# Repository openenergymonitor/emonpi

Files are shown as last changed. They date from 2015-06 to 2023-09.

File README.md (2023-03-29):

# emonPi

Raspberry Pi based energy Monitoring Unit

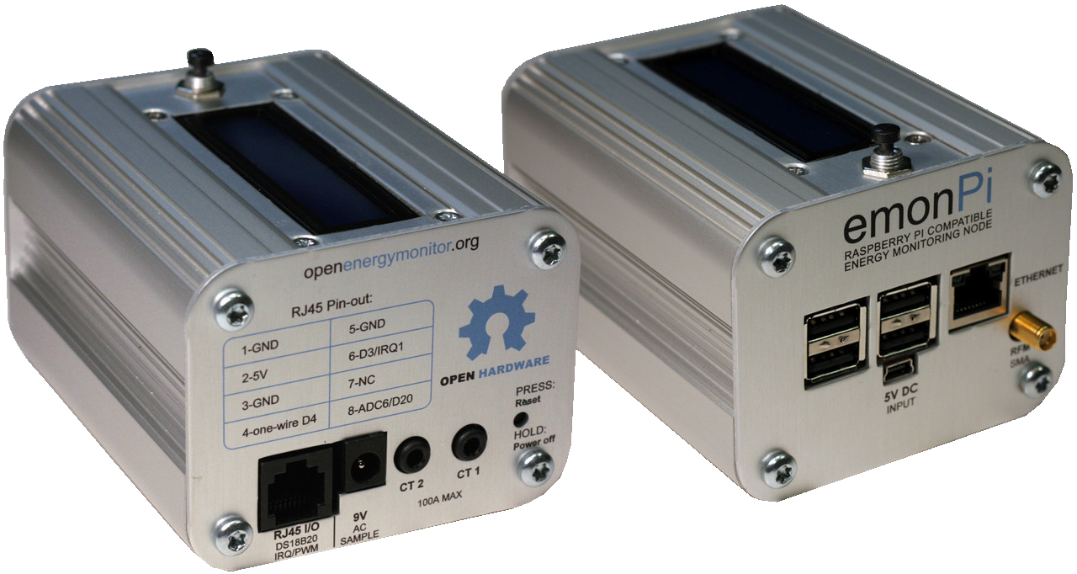
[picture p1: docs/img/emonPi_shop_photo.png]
emonPi


## Documentation

- [Install Guide](https://docs.openenergymonitor.org/emonpi/install.html)
- [Connect](https://docs.openenergymonitor.org/emonpi/connect.html)
- [Pulse counting](https://docs.openenergymonitor.org/emonpi/pulse_counting.html)
- [Temperature sensing](https://docs.openenergymonitor.org/emonpi/temperature_sensing.html)
- [Firmware](https://docs.openenergymonitor.org/emonpi/firmware.html)
- [Configuration](https://docs.openenergymonitor.org/emonpi/configuration.html)
- [Use in North America](https://docs.openenergymonitor.org/emonpi/north-america.html)
- [Modification](https://docs.openenergymonitor.org/emonpi/modification.html)
- [Technical](https://docs.openenergymonitor.org/emonpi/technical.html)

Or view directly on github [here](docs).

## [emonSD image download](https://docs.openenergymonitor.org/emonsd/download.html)

[Software Stack Build & Documentation](https://github.com/openenergymonitor/emonscripts)

## Open-Hardware:

- [Schematic & Board CAD Design Files](https://github.com/openenergymonitor/emonpi/tree/master/hardware)

## Community & Support

- [OpenEnergyMonitor Forums](https://community.openenergymonitor.org)
- OpenEnergyMonitor Shop Support: support@openenergymonitor.zendesk.com

## License

- The hardware designs (schematics and CAD files) are licensed under a Creative Commons Attribution-ShareAlike 3.0 Unported License.
- The firmware is released under the GNU GPL V3 license The documentation is subject to GNU Free Documentation License
- The hardware designs follow the terms of the OSHW (Open-source hardware) Statement of Principles 1.0.

## Disclaimer

```
OUR PRODUCTS AND ASSEMBLY KITS MAY BE USED BY EXPERIENCED, SKILLED USERS, AT THEIR OWN RISK. TO THE FULLEST EXTENT PERMISSIBLE BY THE APPLICABLE LAW, WE HEREBY DISCLAIM ANY AND ALL RESPONSIBILITY, RISK, LIABILITY AND DAMAGES ARISING OUT OF DEATH OR PERSONAL INJURY RESULTING FROM ASSEMBLY OR OPERATION OF OUR PRODUCTS.

Your safety is your own responsibility, including proper use of equipment and safety gear, and determining whether you have adequate skill and experience. OpenEnergyMonitor and Megni registered partnership disclaims all responsibility for any resulting damage, injury, or expense. It is your responsibility to make sure that your activities comply with applicable laws, including copyright. Always check the webpage associated with each unit before you get started. There may be important updates or corrections. All use of the instructions, kits, projects and suggestions given both by megni.co.uk, openenergymonitor.org and shop.openenergymonitor.org are to be used at your own risk. The technology (hardware , firmware and software) are constantly changing, documentation (including build guide and instructions) may not be complete or correct.

If you feel uncomfortable with assembling or using any part of the system, return it to us for a full refund.
```

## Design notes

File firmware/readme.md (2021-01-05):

# Change Log - emonPi Discrete Sampling Firmware

Compile using PlatformIO: https://guide.openenergymonitor.org/technical/compiling/

***

# V2.9.3 (05/01/21

- Wait longer for DS18B20 conversion, require for new batch of RJ45 temp sensors

# V2.9.2 (17/11/19)

- Fix RFM init 

https://community.openenergymonitor.org/t/emonpi-firmware-build/12428/45

```
RAM:   [=====     ]  52.9% (used 1083 bytes from 2048 bytes)
Flash: [======    ]  60.3% (used 18526 bytes from 30720 bytes)
```

# V2.9.0 (16/01/18)

- Allow CT's to be plugged in after unit has powered up. CT input will read zero if no CT is connected.

```
Program:   17886 bytes (54.6% Full)
(.text + .data + .bootloader)

Data:       1048 bytes (51.2% Full)
(.data + .bss + .noinit)
```

# V2.8.4 (21/12/17)

- Correct USA voltage for apparent power sampling to 120V. Only affects battery / DC USB 5V operation. Does not effect when powering unit via AC-AC adaptor.

```
Program:   17942 bytes (54.8% Full)
(.text + .data + .bootloader)

Data:       1034 bytes (50.5% Full)
(.data + .bss + .noinit)
```

# V2.8.3 (07/04/17)

- Reduce min pulse width to 60ms

# V2.8.2 (07/04/17)

* Reduce min pulse width to 60ms

```
Program:   17892 bytes (54.6% Full)
(.text + .data + .bootloader)
Data:       1022 bytes (49.9% Full)
(.data + .bss + .noinit)
```

# V2.8.2 (10/12/16)

* Autodetect LCD on I2C address `0x27` or `0x3f`

```
Program:   17900 bytes (54.6% Full)
(.text + .data + .bootloader)
Data:       1026 bytes (50.1% Full)
(.data + .bss + .noinit)
```

# V2.8.1 (21/11/16)

* Reintroduces "quiet mode" feature as seen in the RFM2Pi firmwares to allow improved RF debugging.

Serial `1q` enables quiet mode (default) and `0q` removes quiet mode for a more verbose output including bad packets that have failed crc checks. In emonHub it can be set with `quiet = true` or `quiet = false` in the interfacer settings. [Pull request discussion](https://github.com/openenergymonitor/emonpi/pull/34).

```
Program:   19206 bytes (58.6% Full)
(.text + .data + .bootloader)
Data:        953 bytes (46.5% Full)
(.data + .bss + .noinit)
```

# V2.8 (18/11/16)

* Compiled using platformIO with [JeeLib 10th Nov 2015 (f097c0039c)](https://github.com/jcw/jeelib/tree/f097c0039c926881d80a74bec7a7aa020de610ee)
* Fixes emonTx drop off [forum discussion](https://community.openenergymonitor.org/t/emon-txs-not-updating-after-emonpi-update/2233/10)

```
Program:   19074 bytes (58.2% Full)
(.text + .data + .bootloader)
Data:        951 bytes (46.4% Full)
(.data + .bss + .noinit)
```

# V2.7 (16/11/16)

* Compiled using platformIO with latest JeeLib (7fc95a72ec)
* Consistency with github releases
* Smaller compiled size
* Ensure soft-reset introduced in V2.5 is included
  * Fix RF droping issue caused by V2.6 being mistakenly compiled

```
Program:   19100 bytes (58.3% Full)
(.text + .data + .bootloader)
Data:        951 bytes (46.4% Full)
(.data + .bss + .noinit)
```

# V2.6 (15/04/16)
* [Update to latest JeeLib with RF Fixes ](https://github.com/jcw/jeelib/issues/92) [68f6e42]~~
* Remove RF keep alive introduced in V2.5~
Compiled with Arduino 1.6.8 | Hex size: 54.8kB | Sketch uses 19,400 bytes (60%) | Global variables: 947 bytes (46%)~~

**(10/05/16) - Temporarily restored to V2.5 to fix emonTx RF dropping issue [thread [[1]](https://community.openenergymonitor.org/t/emonsd-03may16-release/145/40) [[2]](https://openenergymonitor.org/emon/node/12593)**

# V2.5 (18/03/16)
 * Soft reset RFM69CW ever 60s to ensure its kept alive

Compiled with Arduino 1.6.8 | Hex size: 55kB | Sketch uses 19,554 bytes | Global variables: 946 bytes

# V2.4 (8/03/16)
 * Adjust Vcal_EU to improve VRMS voltage reading accuracy when using UK/EU AC-AC
 * Compile with Arduino 1.6.7 with JeeLib 10th Sep 2015 f097c0039c926881d80a74bec7a7aa020de610ee
 * Updated OneWire library to V2.3.2 & updated sensors.getAddress function

Compiled with Arduino 1.6.8 | Hex size: 54.8kB | Sketch uses 19,460 bytes | Global variables: 941 bytes

# V2.3 (20/02/16)
 * Fix VRMS reading bug
 * Compile with Arduino 1.6.7

# V2.2 (30/01/16)
 * Reduction in SRAM memory usage thanks to F-macro serial string implementation
 * Display "Raspberry Pi Booting" message on LCD at startup
 * Only sample from CT channels when CT is connected to that channel (fix noise readings when no CT connected)

# V2.1 (20/1/16)
  * Allow use of group 0

# V2.0 (17/11/15)
  * Don't print ACK's to serial

# V1.9 (16/11/15)
  * Fix counting pulses faster than 110ms, strobed meter LED http://openenergymonitor.org/emon/node/11490

# V1.8 (30/10/15)
  * Enable pulse count INT1 internal pull-up to fix spurious pulse count readings

# V1.7 (12/06/15)
  * Fix bug which stopped USA AC-AC Vcal from being applied at runtime

# V1.6 (12/06/15)
  * Fix interrupt pulse debouce issue by limiting pulse width to 52ms min (50ms is default for LED pulse output meters)
  * Compile with latest JeeLib with fix for RF hang, remove RF reset added in V1.3 (bf179057ee1abc2cfa2965b454421203ac52c6c3)
  * Enable simultaneous pulse counting and temperature monitoring on single RJ45 using breakout

# V1.5 (27/05/15)
  * Change pulse count to be stored as unsigned long datatype
  * Add new variable power 1 + power 2 as third item in the node struct. This will be useful for US installs and Solar PV type 2 installations to provide a feed for consumption (solar PV + grid import / export)

**Important Note:**
After this update a manual change will be required to emonhub.conf, copy and paste the following to override the node decoder for the emonPi node [[5]] in the Nodes section of emonhub.conf:
```
[[5]]
    nodename = emonPi
    firmware = emonPi_RFM69CW_RF12Demo_DiscreteSampling.ino
    hardware = emonpi
    [[[rx]]]
        names = power1,power2,power1_plus_power2,Vrms,T1,T2,T3,T4,T5,T6,pulseCount
        datacodes = h, h, h, h, h, h, h, h, h, h, L
        scales = 1,1,1,0.01,0.1,0.1,0.1,0.1,0.1,0.1,1
        units = W,W,W,V,C,C,C,C,C,C,p
```
https://github.com/openenergymonitor/emonpi/commit/c427cd2bdfce7b3c535388d1ee53cc45183edf9c

# V1.4 (27/05/15)
Make firmware version return command 'v' return firmware version and RFM setting all on one line
https://github.com/openenergymonitor/emonpi/commit/fa4474571cffa45d03483ce9da32f021dd2df91a

# V1.3 (21/05/15)
1.3 firmware dev, add RF init ever 10min to keep RF alive
https://github.com/openenergymonitor/emonpi/commit/96b59c38c045a44e6dea3c1a5e048d038380e88a

# V1.2 (13/05/15)
Fix AC wave detect and improve AC calibration calibration
https://github.com/openenergymonitor/emonpi/commit/41987f1e21b3687b8b0ac6b9f5f5160cdfb808a4

# V1.1 (11/05/15)
Add sample from both CT's as default and set 110V VRMS for apparent power when US calibration is set e.g '2p'
https://github.com/openenergymonitor/emonpi/commit/2565eb3663847c22bfb62b0d1258f8cbc5fea224

# V1.0
First release

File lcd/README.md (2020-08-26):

# HD44780 LCD with PCF8574 I2c

I2C Address: 0x27 or 0x3f

# Enabling The I2C Port

**Tested on Raspbian**

The I2C ports need to be enabled in Raspbian before they can be used.

	$ sudo nano /boot/config.txt

Un-comment / add the line

	dtparam=i2c_arm=on

Edit kernel modules file:

	$ sudo nano /etc/modules

Add this line:

i2c-dev

Exit and save the file.

## Install the I2C utilities:

Usually pre-installed

		$ sudo apt-get install python-smbus i2c-tools

Enter "sudo reboot" to restart the pi and now the I2C pins will be available to use.

## Detect LCD on I2C bus and find out address

	$ sudo i2cdetect -y 1

Expected output is `0x27` or `0x3F` e.g.

```
pi@emonpi:~ $  sudo i2cdetect -y 1
     0  1  2  3  4  5  6  7  8  9  a  b  c  d  e  f
00:          -- -- -- -- -- -- -- -- -- -- -- -- -- 
10: -- -- -- -- -- -- -- -- -- -- -- -- -- -- -- -- 
20: -- -- -- -- -- -- -- 27 -- -- -- -- -- -- -- -- 
30: -- -- -- -- -- -- -- -- -- -- -- -- -- -- -- -- 
40: -- -- -- -- -- -- -- -- -- -- -- -- -- -- -- -- 
50: -- -- -- -- -- -- -- -- -- -- -- -- -- -- -- -- 
60: -- -- -- -- -- -- -- -- -- -- -- -- -- -- -- -- 
70: -- -- -- -- -- -- -- --   
```

Use port 0 for very old 256Mb RAM pi (rev1) - not recommended to use this pi version

# Install emonPiLCD python script

```
sudo apt-get update
sudo apt-get install python3-smbus i2c-tools python3-rpi.gpio python3-pip redis-server python3-gpiozero -y
sudo pip3 install redis paho-mqtt xmltodict requests
```

## Run as service

Run the shell script  
```
./install.sh
```

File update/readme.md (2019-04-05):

# How to run scripts manually

Current directory is emonpi/update

### Update Emoncms

    ./emoncms.sh IS_EMONSD
    ./emoncms.sh 0
    
### Update EmonHub

    ./emonhub.sh
    
### Update Firmware: EmonPi

    ./emonpi.sh
    
### Update Firmware: rfm69pi

    ./rfm69pi.sh
    
### Via main.sh

    ./main.sh UPDATE_TYPE FIRMWARE IMAGE_NAME
    ./main.sh all emonpi emonSD-30Oct18
    ./main.sh emoncms emonSD-30Oct18
    ./main.sh emonhub emonSD-30Oct18
    ./main.sh firmware emonpi emonSD-30Oct18
    
### Via service-runner-update.sh

Current directory is emonpi.

This script is triggered from emoncms via service-runner.

    ./service-runner-update.sh UPDATE_TYPE FIRMWARE
    ./service-runner-update.sh all emonpi

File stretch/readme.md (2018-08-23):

# Raspbian Stretch

This folder contains config files symlinked into the latest emonSD pre-build raspberry pi SD card image based on Raspbian Stretch. 

- Compatiable with RasPi 3B+ 
- Based on Raspbian Stretch Lite 
- **Does not have read-only root FS** - Unlike older emonSD card images, the Stretch image does not have a read-only root partition. After extensive testing and file system monitoring it was determind that we could achieve SD card low write by only mounting /var/log in temp fs and keeping the root partition in RW all the time. This has the advantage of making setup, config and maintenance much easier since the image is closer to the stock raspbian image.
- The folder `~/data``is still mounted on a seperate partition with a low write file-system

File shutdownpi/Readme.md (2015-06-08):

*Not used on production emonpi, functionality is now built into main emonpi lcd script 

Python Script to look for high signal on GPIO 17 (pin 11) and then shutdown the Pi if so

on the emonPi GPIO 17 is connected to ATmega328 Dig5. 
When running default firmware emonPi sets Dig5/GPIO17 high when shutdown push button the the emonPi PCB is held for 5s. The push button is connected to ATmega328 dig 8

emonPi - Raspberry Pi Energy Monitoring 
Part of the OpenEnergyMonitor.org Project

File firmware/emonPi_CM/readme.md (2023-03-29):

# emonPi_CM

**New 16th Feb 2023:** This firmware provides higher accuracy continuous monitoring. Continuous monitoring means that the power readings are representative of the full 10s period that they represent rather than a short snapshot. Support for radio formats: JeeLib Native and **LowPowerLabs (recommended)**.

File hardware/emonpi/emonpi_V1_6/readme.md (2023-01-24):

## emonPi V1.6

**Raspberry Pi Energy Monitoring Shield**

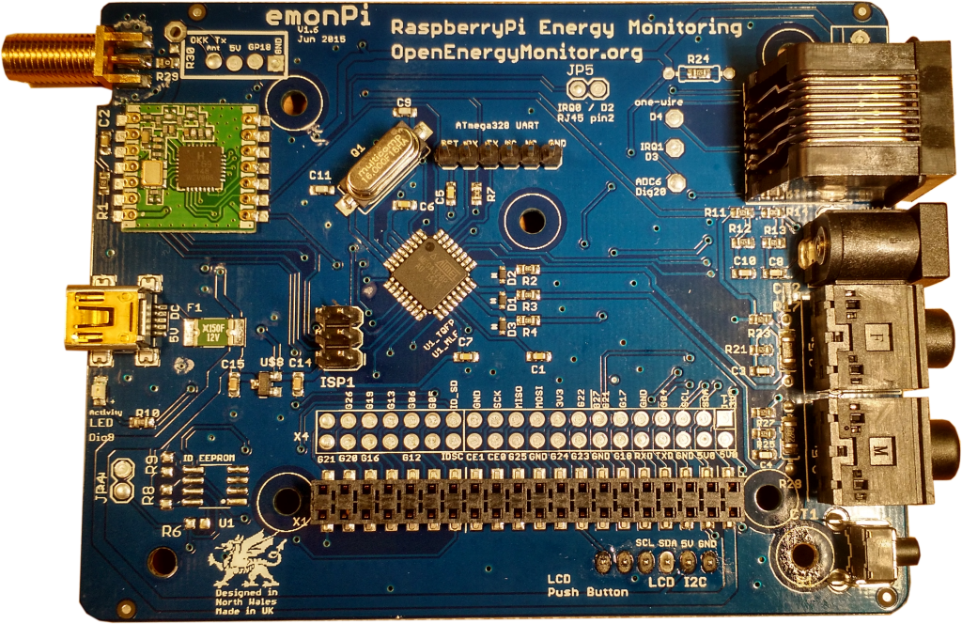
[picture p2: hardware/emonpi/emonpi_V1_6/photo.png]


### Schematic

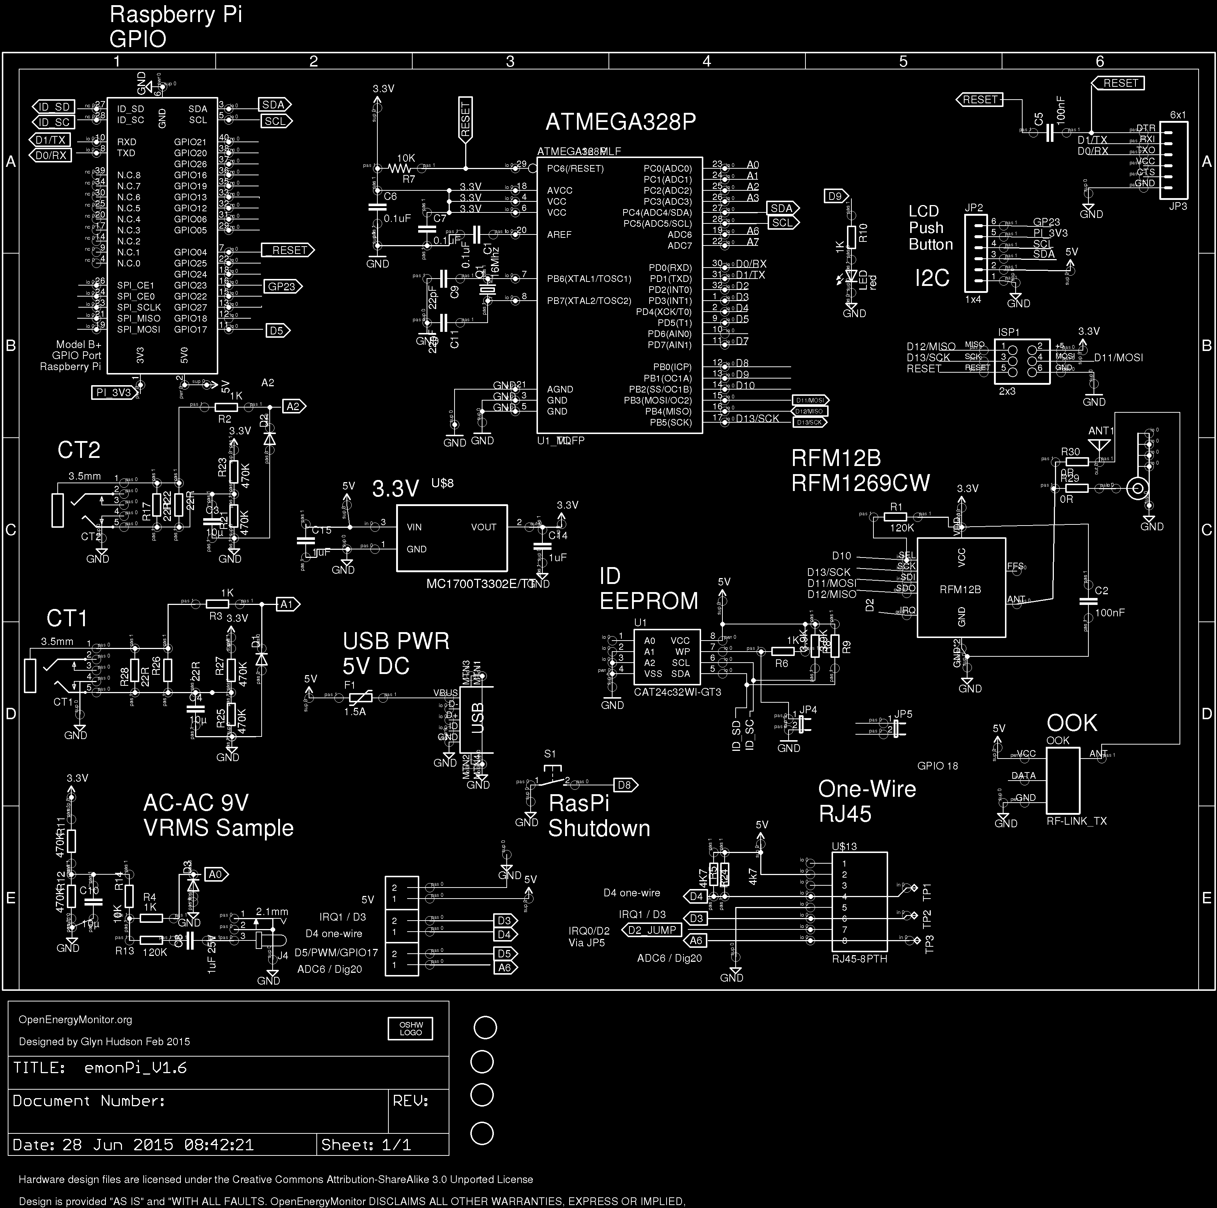
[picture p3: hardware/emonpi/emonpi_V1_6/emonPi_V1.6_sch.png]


### Board

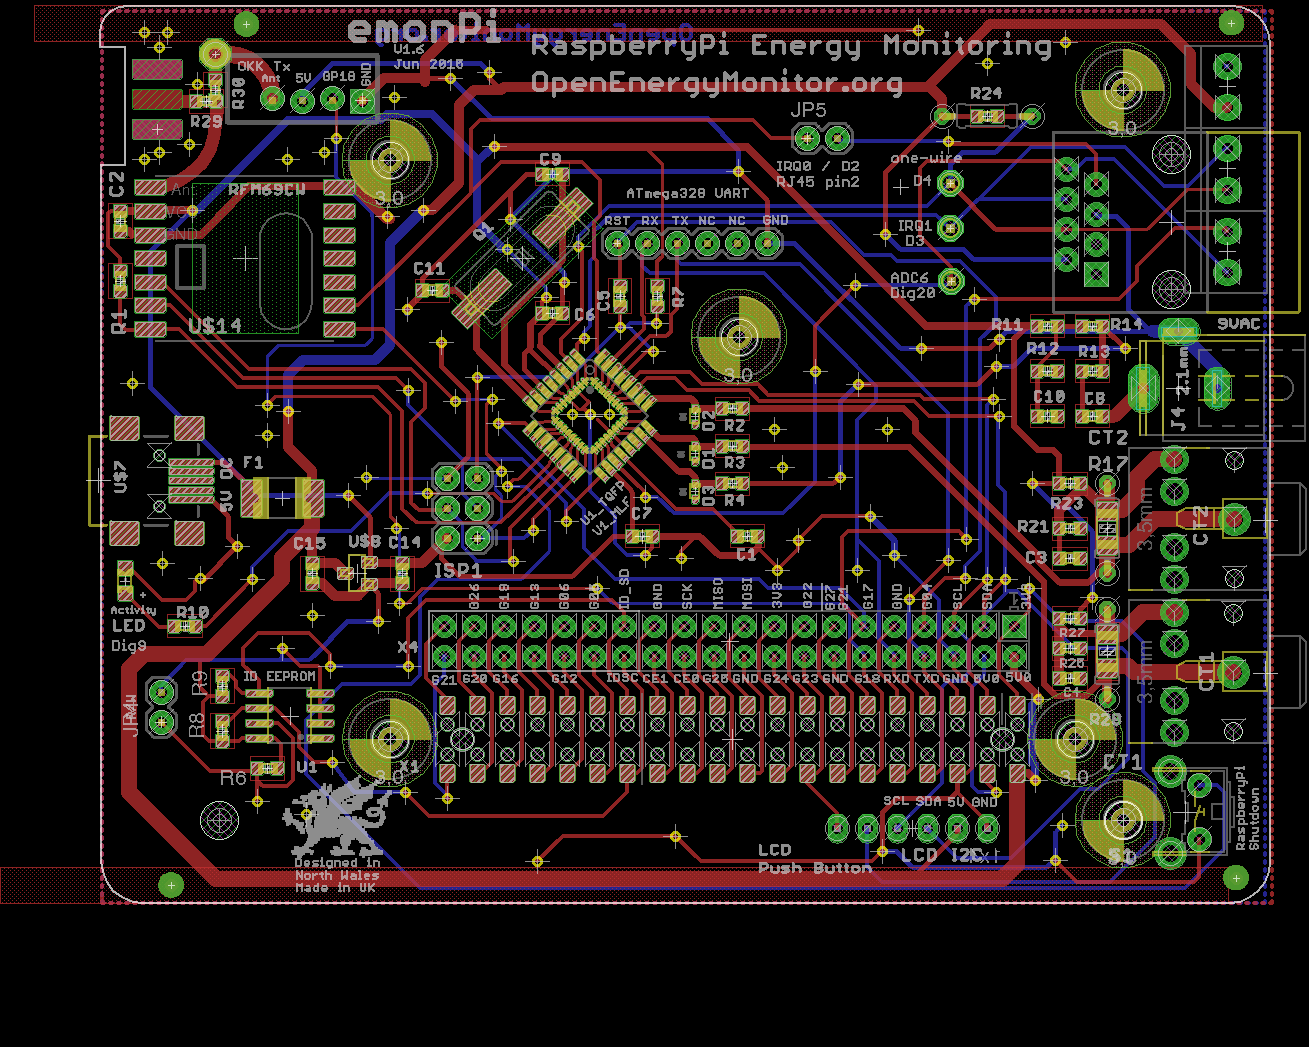
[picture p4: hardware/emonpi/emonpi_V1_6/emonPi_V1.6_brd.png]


### Port Map

| Arduino Pin | AVR Special Function  | emonPi V1.6 Atmega 328 | Raspberry Pi |
|---|---|---|---|
| Analog 0 (D14) | | AC Voltage | |
| Analog 1 (D15) | | CT1 | |
| Analog 2 (D16) | | CT2 | |
| Analog 3 (D17) | | | |
| Analog 4 (D18) | (SDA) | | |
| Analog 5 (D19) | (SCL) | | |
| Analog 6 (D20) | | RJ45 pin 8 – ADC6 / Dig20 | |
| Analog 7 (D21) | | | |
| Digital 0 | (RXD) | FTDI Tx | GPIO 14 / pin 8 |
| Digital 1 | (TXD) | FTDI Rx | GPIO 15 / pin 10  |
| Digital 2 | (int0) PWM | RFM12B/69CW INT / (JP5 – RJ45 pin 7) | |
| Digital 3 | (int1) PWM | RJ45 pin 6 – Pulse counter | |
| Digital 4 | | RJ45 pin 4 – one-wire DS18B20 | |
| Digital 5 | PWM | Raspi GPIO 17 / Pin 11 | GPIO 17 / Pin 11  |
| Digital 6 | PWM | OOK Tx / (GPIO 18 -Pin 12) V1.6 | |
| Digital 7 | | | |
| Digital 8 | | Shutdown PTM Button | |
| Digital 9 | PWM | emonPi PCB LED | |
| Digital 10 | (SS) PWM | RFM69CW SEL | |
| Digital 11 | (MOSI) PWM | RFM69CW SDI | |
| Digital 12 | (MISO) | RFM69CW SDO | |
| Digital 13 | (SCK) | RFM69CW SCK | |

### Raspberry Pi GPIO

| Raspberry Pi GPIO  | RasPi Function  | emonPi V1.6 ATmega328 |
|---|---|---|
| 2 (0 REV1) | I2C | SDA I2C LCD |
| 3 (1 REV 1) | I2C | SCL I2C LCD |
| 4 (pin 7) | | ATmega328 reset |
| 7 | SPI CS | |
| 8 | SPI CS | |
| 9 | SPI | |
| 10 | SPI | |
| 11 | SPI | |
| 14 | UART Tx | Dig 0 /Rx |
| 15 | UART Rx | Dig 1 / Tx |
| 17 (pin 11) | | Atmega Dig 5 – shutdown signal |
| 18 (pin 12) | | OOK Tx (V1.6) |
| 22 | | |
| 23 (pin 16) | | LCD PTM push button (High when pressed)  |
| 24 | | |
| 25 | | |
| 27 (21 REV 1) | | |

Red dots mark GPIO used by the emonPi: 

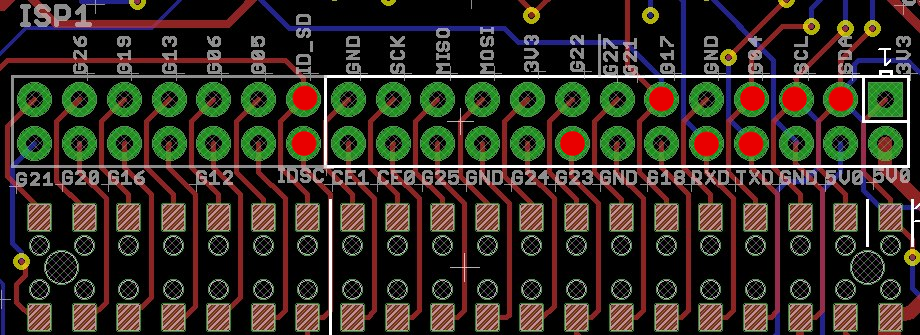
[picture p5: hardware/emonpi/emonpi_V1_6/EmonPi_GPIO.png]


### Enclosure CAD Design

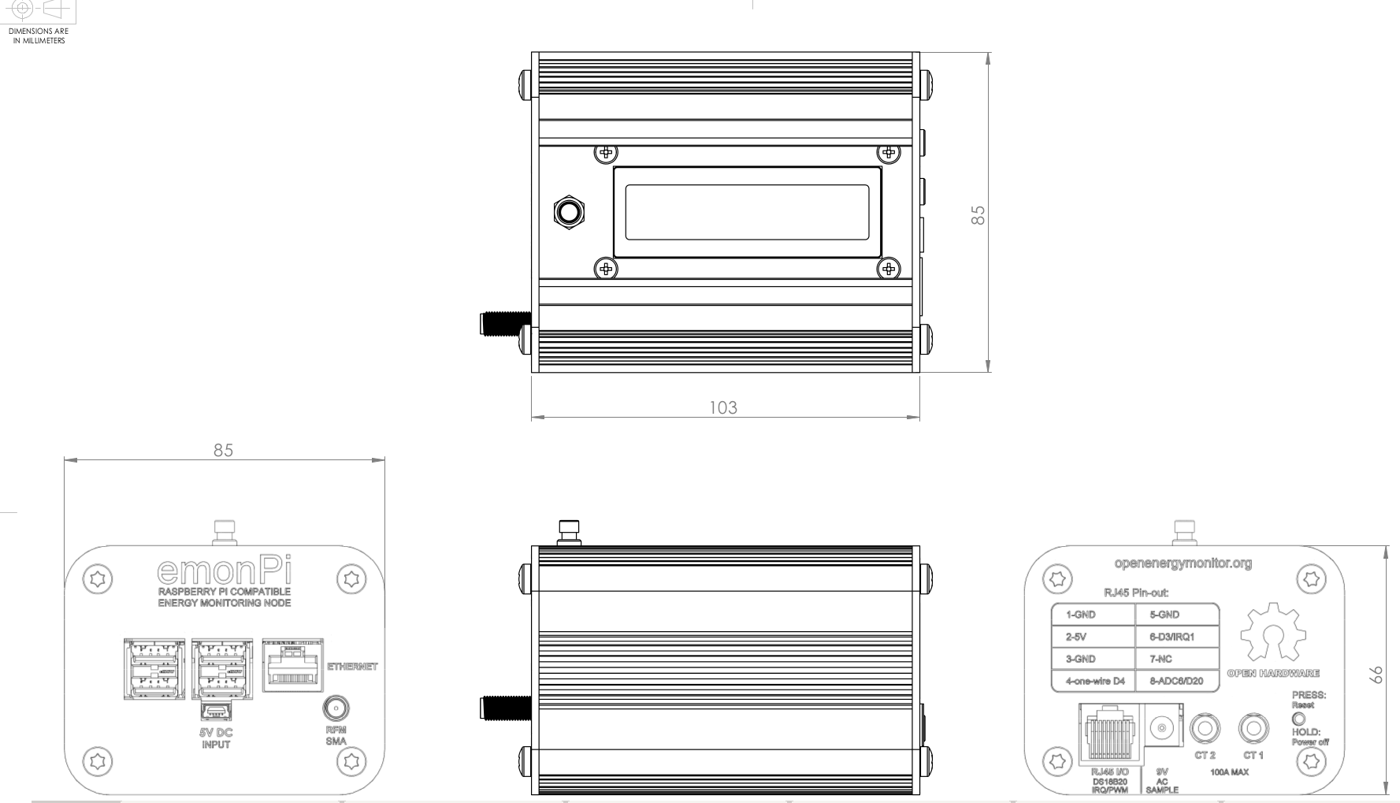
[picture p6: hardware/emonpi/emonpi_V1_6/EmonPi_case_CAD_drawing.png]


### Dimensions

PCB: 99.2mm x 76.1mm

Enclosure: 103mm x 85mm x 99mm

Enclosure Screws: Torx T20

Raspberry Pi fixing kit (Rapid Rapid numbers):

- 4 x 15mm spacer: 33-2040
- 4 x M3 screw: 33-2300

LCD fixing kit (Rapid Rapid numbers):

- 4 x 6mm spacer: 33-2034
- 4 x M3 lock Nut: 33-4402
- 4 x M3 12mm countersunk screw: 33-2955

### Open Hardware

Hardware designs (schematics and CAD) files are licensed under the [Creative Commons Attribution-ShareAlike 3.0 Unported License](http://creativecommons.org/licenses/by-sa/3.0/) and follow the terms of the [OSHW (Open-source hardware) Statement of Principles 1.0.](http://freedomdefined.org/OSHW)

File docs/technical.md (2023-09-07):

# emonPi Technical Overview

The emonPi is an all-in-one Raspberry Pi based energy monitoring unit making for a simple installation where Ethernet or WiFi is available at the meter location.

The emonPi can monitor two single-phase AC circuits using clip-on CT sensors. The emonPi can also monitor temperature, and interface directly with a utility meter via an optical pulse sensor.

emonpi

**Features:**

- 2x CT Sensor inputs for single-phase AC electricity monitoring designed for use with the [100A SCT-013-000 CT sensor](https://shop.openenergymonitor.com/100a-max-clip-on-current-sensor-ct/)
- 1x AC voltage measurement using plug-in AC-AC adapter for real power calculation alongside current measurement from CT sensors. Designed for use with a [9V AC output voltage adapter](https://shop.openenergymonitor.com/ac-ac-power-supply-adapter-ac-voltage-sensor-uk-plug/)
- Support for multiple wired one-wire DS18B20 temperature sensors via RJ45 socket
- Support for pulse counting either wired or via Optical Pulse Sensor
- 433 MHz RFM69 radio transceiver for receiving data from additional energy monitoring or temperature and humidity nodes.
- The emonPi measurement board is based on Arduino (Atmega328). This talks to an integrated Raspberry Pi running our emonSD software stack on it's SD card.
- Full local data logging and visualisation capability using the emonSD Emoncms software stack. Data can also be sent to a remote emoncms server such as emoncms.org.
- Network connectivity via either Ethernet or WiFi.
- **LCD Display:** for easier setup, displays network IP address and sensor status.
- **Push button:** for shutdown and enabling/disabling SSH access.

## emonPi Internals

The emonPi is based on a RaspberryPi + emonPi measurement board. The emonPi measurement board is based on an ATmega328p 8-bit microcontroller running Arduino based firmware. The following video gives a good overview of what is inside an emonPi. Note that we currently ship RaspberryPi version 3b+ which has WiFi onboard rather than the older version featured in this video.

<div class='videoWrapper'>
<iframe width="560" height="315" src="https://www.youtube.com/embed/lc2LzCZnySo" frameborder="0" allowfullscreen></iframe>
</div>

## System Overview

The following system diagram shows the main hardware and software components that make up the emonPi. On the left we have the emonPi measurement board based on the ATmega328 microcontroller with inputs from the different sensors, RFM69 433 MHz transceiver, button and I2C connection to the LCD. 

The Atmega328 microprocessor communicates with the Raspberry Pi via the internal UART serial port (/dev/ttyAMA0).

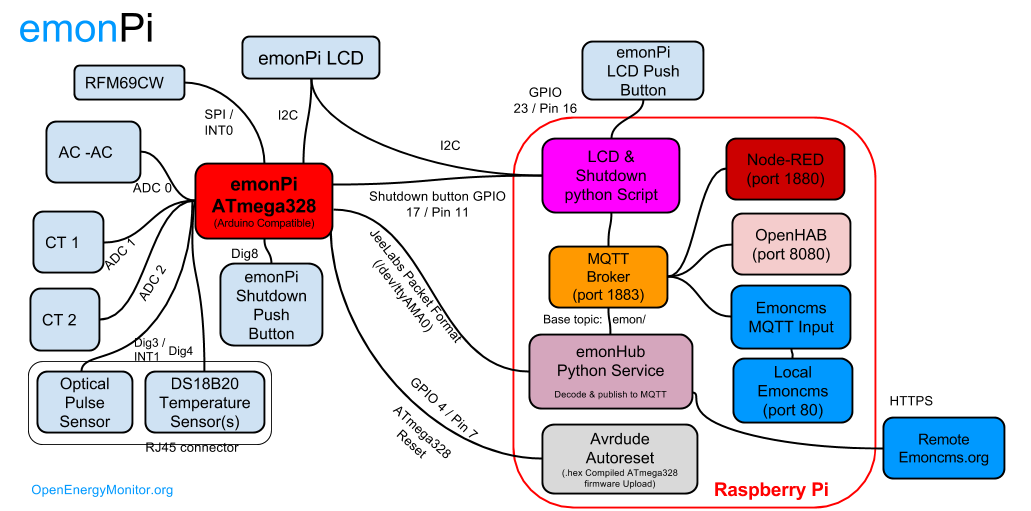
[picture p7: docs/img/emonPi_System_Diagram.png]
emonPi system diagram


### RF

The emonPi uses the HopeRF RFM69CW RF module to receive data from other wireless nodes (emonTx, emonTH etc) using 433 MHz. We use the [JeeLib packet format](http://jeelabs.org/2011/06/09/rf12-packet-format-and-design/). Each RF node has a unique node ID but common network group (default 210). The ATmega328 runs a modified version of [JeeLabs RFM12Demo Sketch](https://github.com/jeelabs/jeelib/blob/master/examples/RF12/RF12demo/RF12demo.ino) to receive the data from radio nodes. Received radio packets are forwarded over serial and decoded on the RaspberryPi using EmonHub.

### Energy Monitoring

The emonPi measurement board includes input circuitry that converts the outputs from the ACAC adapter and CT sensors into signals that are compatible with the Analog to Digital converter (ADC). The ATmega328's 10-bit ADC samples the voltage and current channels sequentially. The Firmware running on the ATmega328 calculates real power, apparent power, power factor, Vrms and Irms of each channel. The real power reading is then pushed every 5s to the RaspberryPi for logging and visualisation.

To learn more about how the electricity monitoring works, see our Learn site here:

- [Learn: AC Power Theory](https://learn.openenergymonitor.org/electricity-monitoring/ac-power-theory/introduction)
- [Learn: CT Sensors, interfacing with an Arduino](https://learn.openenergymonitor.org/electricity-monitoring/ct-sensors/interface-with-arduino)
- [Learn: Measuring AC Voltage with an AC to AC power adapter](https://learn.openenergymonitor.org/electricity-monitoring/voltage-sensing/measuring-voltage-with-an-acac-power-adapter)

The full emonPi measurement board firmware can be accessed and downloaded here:

- [emonPi Discrete Sampling Firmware](https://github.com/openenergymonitor/emonpi/tree/master/firmware)
- The firmware uses the [EmonLib Discrete Sampling Library](https://github.com/openenergymonitor/EmonLib/)

The CT input's are designed for use with the [100A SCT-013-000 CT sensor](https://shop.openenergymonitor.com/100a-max-clip-on-current-sensor-ct/). This sensor has 2000 turns, which means that the current in the secondary is 2000 less than the current in the mains wire primary. The emonPi has a fixed sized burden resistor specified to match this sensor at 22 Ohms. It is possible to change this burden resistor if you wish to use a CT with a different current range or number of turns.

### Pulse Counting

Pulse counting on the emonPi uses the hardware interrupt IRQ1 on the ATmega328. The first hardware interrupt IRQ0 is used by the RFM69CW. Only one pulse counter input is possible per emonTx/emonPi. See guide [+ Add Optical Pulse Sensor](pulse_counting.md) for more information on the optical pulse sensor.

The emonPi firmware implements a check for a minimum pulse width, this can be shortened on systems with more frequent pulses, see line: [https://github.com/openenergymonitor/emonpi/blob/master/firmware/emonPi_DS_jeelib_classic/main.ino#L96](https://github.com/openenergymonitor/emonpi/blob/master/firmware/emonPi_DS_jeelib_classic/main.ino#L96).

## RaspberryPi and emonSD

The emonPi Raspberry Pi runs our emonSD software stack which is based on [Raspbian Buster Lite](https://www.raspberrypi.org/downloads/raspbian/). The pre-built emonSD image is available to [purchase](https://shop.openenergymonitor.com/emonsd-pre-loaded-raspberry-pi-sd-card/) or [download](../emonsd/download.md) or it is possible to built the image yourself using our automated build script, see [EmonScripts](https://github.com/openenergymonitor/EmonScripts).

EmonSD includes [emonHub](https://github.com/openenergymonitor/emonhub) which reads in the serial data from the emonPi measurement board and acts as a broker forwarding this data on to the local installation of emoncms via MQTT or to a remote server such as emoncms.org via HTTP. 

[Emoncms](https://github.com/emoncms/emoncms) is our open source web application for processing, logging and visualising energy, temperature and other environmental data. It is installed as part of the emonSD software stack and provides full local data logging and visualisation capabilities.

## Open Source

**emonPi Firmware** (see [Firmware Modification](../electricity-monitoring/platformio/index.md)<br>
[emonPi Discrete Sampling Firmware](https://github.com/openenergymonitor/emonpi/tree/master/firmware)

**emonPi Schematic and Board files:**<br> [https://github.com/openenergymonitor/emonpi/tree/master/hardware/emonpi/emonpi_V1_6](https://github.com/openenergymonitor/emonpi/tree/master/hardware/emonpi/emonpi_V1_6)

---

## emonPi Specification

| Attribute | Parameter  | Link |
|---|---|---|
| Error due to component and sensor tolerances | <11% | [Further info](https://openenergymonitor.org/emon/buildingblocks/emontx-error-sources)
| Measuring Current (CT) |50mA-96A | [Further info](https://openenergymonitor.org/emon/buildingblocks/ct-sensors-interface)
| Measuring Voltage (AC-AC) | 1st: 110VAC-254VAC / 2nd: 9VAC-12VAC| [Further info](https://openenergymonitor.org/emon/buildingblocks/measuring-voltage-with-an-acac-power-adapter)
| Sample period |  5s  | [Discrete sampling](https://github.com/openenergymonitor/emonpi/blob/master/firmware/firmware/firmware.ino)
| Frequency | 433Mhz | [Identify RF module](https://openenergymonitor.org/emon/buildingblocks/which-radio-module)
| RF range | 40m-100m | [Antenna testing](https://blog.openenergymonitor.org/2014/03/emontx-v3-antenna-testing/)
| Power Consumption | 1.5W-2.5W RasPi2 / 2W-4W RasPi3 |
| Operating temperature | -25 to +80 DegC | [Further info](https://www.raspberrypi.org/help/faqs/#performanceOperatingTemperature)
| Physical Dimensions | 10cm x 8.5cm x 10cm |

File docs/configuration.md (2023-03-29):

# Configuration

**The following configuration instructions apply to the new emonPi_CM firmware only.**

This firmware is available in two variants: 

- **Recommended: LowPowerLabs** radio format.
- JeeLib Native radio format

The firmware does not support receiving data from the original JeeLib Classic radio format.

Make sure that all sensor nodes (e.g emonTx, emonTH) that send data to the emonPi_CM are running firmware that transmits in the correct format.

## The emonPi_CM front-end firmware - description

The firmware that runs in the Atmel ATMega 328P primarily provides the energy monitoring
function and handles the radio traffic coming in from other sensor nodes.

It uses emonLibCM, set up for two current channels, to obtain and process current and
voltage readings and, from external sensors, temperature readings and the pulse input.

The radio traffic is almost completely processed within the RFM69CW radio module, all the
sketch needs to do is retrieve the complete message when it becomes available. When a
complete message is available, a call to `radio.receiveDone()` will return `true`, and the
message is formatted and sent via the serial connection to the Raspberry Pi.

Likewise, when a set of readings is available from emonLibCM, `EmonLibCM_Ready()`
returns true and the power values (or assumed apparent powers calculated from the
nominal voltage and measured current) are loaded into the emonpi structure and similarly
passed to the Raspberry Pi by `send_emonpi_serial()`.

It is now possible to fully calibrate the emonPi. Calibration commands come in via the
same serial interface from the Raspberry Pi, and are handled by `getCalibration()` (in a
separate source file).

It’s also possible to transmit a message – that function is handled by the outbound r.f. data
handler.

Configuration, calibration and the latest energy values are stored in the EEPROM memory
of the ATMega 328P. The task of saving the data to, and retrieving the data from, the
EEPROM is handled

## Configuration & on-line calibration

On-line configuration is locked for the first 3 minutes after the front-end sketch has started
in order to allow the Raspberry Pi to start, without any data emitted to the serial port
affecting the configuration or calibration.

If the emonPi does not appear in emonCMS the very first time it is powered up (following
setting up the Wi-Fi parameters etc), restart the energy monitoring front end with a short
press of the reset button adjacent to the CT1 connector.

The following setup/configuration commands are available:

- **l** list the settings (terse)
- **L** list the settings (verbose)
- **r** restore sketch defaults & restart
- **s** save config to EEPROM
- **v** show firmware version
- **V** verbose mode - changes etc echoed to serial output
- **b\<n\>** set r.f. band n = a single numeral: 4 = 433MHz, 8 = 868MHz, 9 = 915MHz (may require hardware change)
- **p\<nn\>** set the r.f. power. nn - an integer 0 - 31 representing -18 dBm to +13 dBm. Default: 25 (+7 dBm)
- **g\<nnn\>** set Network Group nnn - an integer (OEM default = 210)
- **n\<nn\>** set node ID n= an integer (standard node ids are 1..60)
- **c\<n\>** n = 0 for OFF, n = 1 for ON, enable current & power factor values to serial output for calibration.
- **d\<xx.x\>** a floating point number for the datalogging period
- **k\<x\> \<yy.y\> \<zz.z\>**
  - Calibrate an analogue input channel:
  - x = a single numeral: 0 = voltage calibration, 1 = ct1 calibration, 2 = ct2 calibration, etc
  - yy.y = a floating point number for the voltage/current calibration constant
  - zz.z = a floating point number for the phase calibration for this c.t. (z is not needed, or ignored if supplied, when x = 0)
  - e.g. k0 256.8
  - k1 90.9 2.00
- **f\<xx\>** the line frequency in Hz: normally either 50 or 60
- **a\<xx.x\>** a floating point number for the assumed voltage if no a.c. is detected
- **m\<x\> \<yy\>** meter pulse counting: 
  - x = 0 for OFF, x = 1 for ON
  - yy = an integer for the pulse minimum period in ms. (y is not needed, or ignored when x = 0)
- **t0 \<y\>** turn temperature measurement on or off: y = 0 for OFF, y = 1 for ON, y = 2 ON & search for sensors
- **t\<x\> \<yy\> \<yy\> \<yy\> \<yy\> \<yy\> \<yy\> \<yy\> \<yy\>**
  - change a temperature sensor's address or position:
  - x = a single numeral: the position of the sensor in the list (1-based)
  - yy = 8 hexadecimal bytes representing the sensor's address
  - e.g. 28 81 43 31 07 00 00 D9
  - N.B. Sensors CANNOT be added beyond the array size.
- **T\<ccc\>\n** - transmit a string of alpha-numeric characters.
- **w\<x\>** set the radio on or off 0:OFF, 1:Receive ON, 2:Transmit ON, 3:both ON
- **z** set the energy values and pulse count(s) to zero
- **?** show helper text

The command will be acknowledged, and confirmation given when saving the settings,
only after verbose mode has been set. When you change one or more of the settings, the
change will take effect immediately and you might see the displayed values change. (See
below for the temperature sensors, which are different.)

Option (‘s’) will save all the changes. If you do not do this, the settings will revert to the
previous values at the next restart. After you save (‘s’) the changes, the new settings will
be used forever, or until changed again.

If you restore the sketch default values (‘r’), all the EEPROM data is ignored and the
sketch restarts immediately, using the values set in the sketch. There is then no means of
recovering the EEPROM data.

If the EEPROM has been used previously and has had non-compliant values written, the
EEPROM content will be ignored and the sketch will start using its own default values.
Saving the configuration will format the EEPROM and the sketch’s set values will be
stored.

## Adding or moving Temperature Sensors

Sensors can be added, or moved around, without stopping continuous monitoring of power
and energy, but temperature readings must be disabled. If you are indifferent as to the
order of the sensors, then all you need to do is stop temperature monitoring with ‘t0 0‘
followed by ‘t0 1’ to restart it. The sensors will be detected and read. If you need to
preserve the order which they appear, save the configuration to EEPROM with ‘s’.

If you need to preserve the order of existing sensors, or put new sensors into a specific
order, then the procedure is:

- Make a note of the addresses (serial numbers) and the order of any existing sensors with the verbose ‘V’ then list ‘L’ commands.
- Stop temperature monitoring with ‘t0 0’
- Connect the new/replacement sensor(s) and enable temperature monitoring with ‘t0 1’, list the sensors again.
- You will probably find the order of sensors is not what you want. You can put the sensors into the order you need by typing in the address of each. Stop temperature monitoring with ‘t0 0’, then type each sensor address into the position it needs to occupy, e.g:
  - ‘t1 28 81 43 31 07 00 00 D9’
  - ‘t2 28 8D A5 C7 05 00 00 D5’
  - (‘28’ in the first byte is the signature of a DS18B20.) 
- Enable temperature monitoring with ‘t0 1’, list the sensors and check that all is correct and that they are reading as expected.
- Save the configuration to EEPROM with ‘s’

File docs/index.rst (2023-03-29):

emonPi User Guide
=================

.. toctree::
   :maxdepth: 2
   
   Install Guide <install.md>
   connect.md
   pulse_counting.md
   temperature_sensing.md
   firmware.md
   configuration.md
   modifications.md
   north-america.md
   Technical <technical.md>

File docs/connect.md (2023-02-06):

# Connect

The software running on both the emonPi and emonBase SD card is the same. We have created a pre-built image which we call *emonSD* with everything in place to support both local and remote data logging with Emoncms.

This guide walks through connecting an emonPi or emonBase running the emonSD software to your local network or/and the wider internet with either WiFi, Ethernet or 3G GSM Dongle. If you do not wish to connect to a network it is also possible to access the emonPi and emonBase user interface in stand-alone access point mode.

If you are building your own RaspberryPi base station the emonSD image is available to download here: [Pre-build SD card download & Change Log](../emonsd/download.md). The SD card can also be [purchased from the shop](http://shop.openenergymonitor.com/pre-loaded-emonsd-microsd-card-for-raspberry-pi/).

## Option 1: Connecting via Ethernet

Where possible we recommend connecting via Ethernet for best reliability and ease of setup. To ensure that your emonPi/emonBase does not start a WiFi access point on first boot, connect up the Ethernet cable between the emonPi/emonBase and internet router first and then power up the unit.

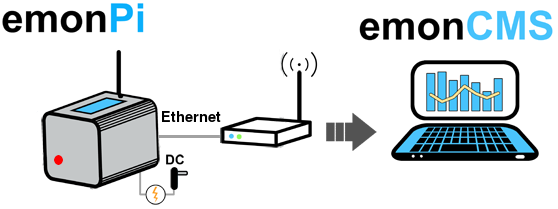
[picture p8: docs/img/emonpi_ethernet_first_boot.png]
emonPi First Boot Ethernet


*Note to self-build users: To ensure that the Pi has enough power a [2.0A USB power adapter is recommended, 2.5A ideal](http://shop.openenergymonitor.com/power-supplies/).*

**emonPi:** The LCD display will display the firmware version then scan for connected sensors. Once the Raspberry Pi has booted up, the LCD will display the IP address of the emonPi on the local network:



*Take care to connect the Ethernet to the socket on the same side as the USB sockets, not the RJ45 connector on the opposite side.*

**emonBase:** Without the LCD Display we have to rely on either the hostname or network discovery tools to find the EmonBase on the network. Try browsing to the hostname: http://emonpi, http://emonpi.local or http://emonpi.lan. 

You should now see the emoncms user login page. Register a new account and then continue to the next step [Log Locally](../emoncms/intro-rpi.md) to configure your system.

If the hostname does not work, it is usually possible to find a list of devices and their IP address's on your internet router. Alternatively Network Discovery tools such as Fing work well. Download [Fing Android](https://play.google.com/store/apps/details?id=com.overlook.android.fing&hl=en_GB) or [Fing iOS](https://itunes.apple.com/gb/app/fing-network-scanner/id430921107?mt=8).

**UPDATE HIGHLY RECOMMENDED:** Now your emonPi/emonBase is connected to a network this would be a good time to pull in any new updates: `Setup > Admin > Update`

## Option 2: Connecting via WiFi

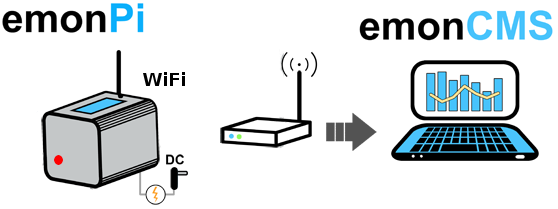
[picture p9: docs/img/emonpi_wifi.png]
emonPi WiFi


- Connect 5V USB power [(2A USB power adapter recommended, 2.5A ideal)](http://shop.openenergymonitor.com/power-supplies/)
- After a couple of minutes the emonPi/emonBase will broadcast a Wifi access point (AP) called `emonsd` with password `emonsd2022` (If you are using an image older than `emonSD-10Nov22`, please refer to this dropdown list to find the correct credentials for your install: https://docs.openenergymonitor.org/emonsd/download.html#emonsd-download).

emonSD-10Nov22 SSID

*Note: Please be patient, it can take a number of minutes to start broadcasting an a WiFi AP at startup. The LCD will display `WiFi: YES 0% 192.168.42.1` once the WiFi AP is active.*

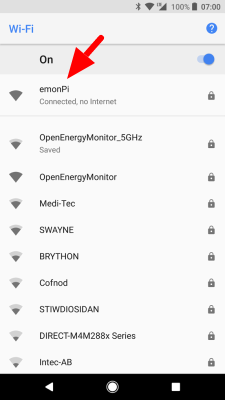
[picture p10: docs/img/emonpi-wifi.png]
emonpi wiki connect


- Connect to `emonPi` WiFi network then either browse to hostname: [http://emonpi](http://emonpi) or [http://emonpi.local](http://emonpi.local) or IP address [http://192.168.42.1](http://192.168.42.1)
- emonPi network setup wizard should now be displayed:

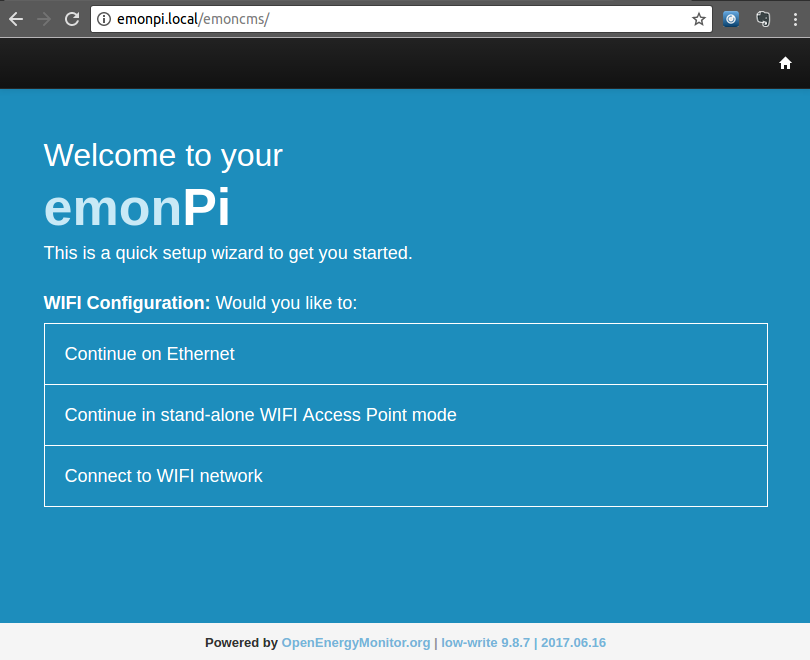
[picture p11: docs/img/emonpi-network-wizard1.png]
emonpi-network-wizard1


- Follow setup wizard to connect to local WiFi network:

*Note: If required emonPi can operate in Wifi AP mode without any network connection. If operating in AP mode use of a [RTC (real-time-clock)](modifications.md) is highly recommended to keep system time.*

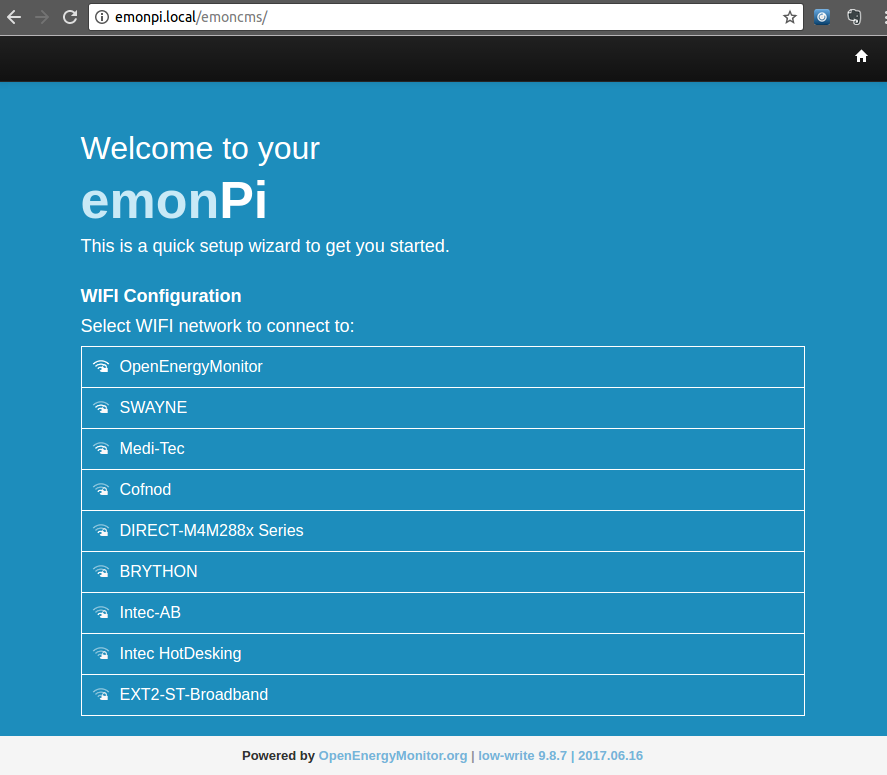
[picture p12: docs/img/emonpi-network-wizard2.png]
emonpi-network-wizard2


**Please be patient, scanning for networks can take a while**

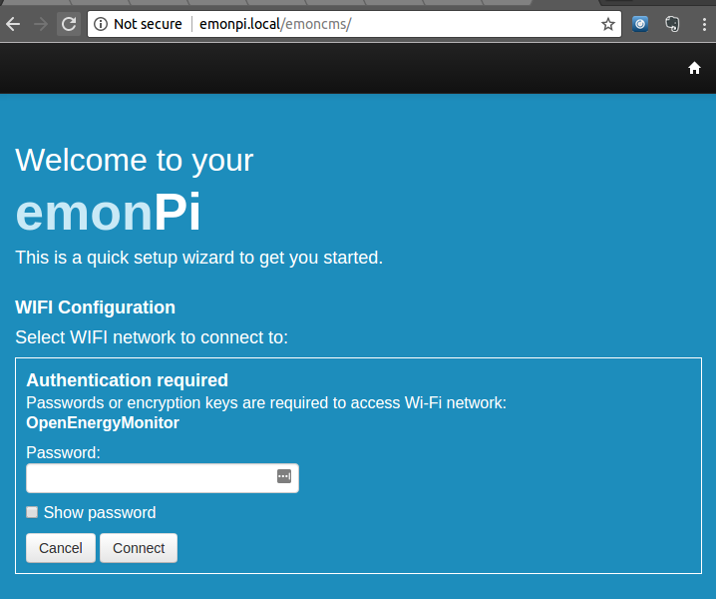
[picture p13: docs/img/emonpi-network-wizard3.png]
emonpi-network-wizard3


- After selecting local WiFi network and entering password the emonPi will turn off its own WiFi AP then reboot and try and connect to local WiFi network.

*Note: if connection fails e.g. incorrect password, follow instructions 1b to connect temporary via Ethernet and use the Emoncms WiFi setup as detailed in step 4*

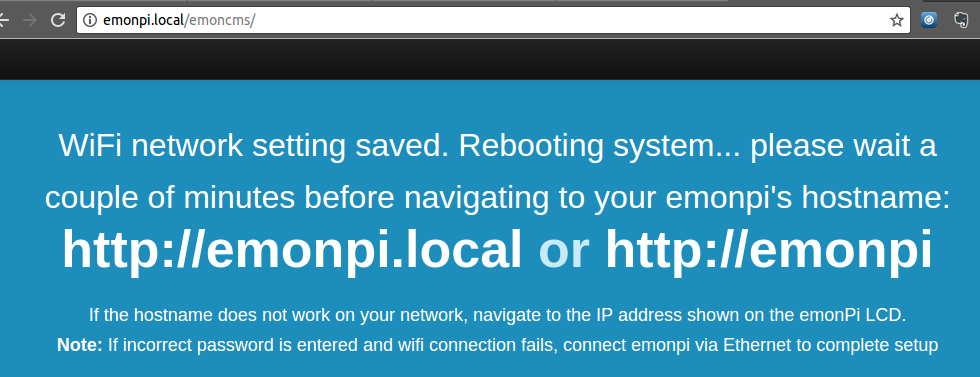
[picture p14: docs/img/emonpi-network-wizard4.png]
emonpi-network-wizard4


- After a couple of minutes attempt to connect to your emonPi/emonBase via it's hostname: [http://emonpi](http://emonpi), [http://emonpi.local](http://emonpi.local) or [http://emonpi.lan](http://emonpi.lan).

- emonPi: If hostname does not work on your network, enter the IP address shown on the LCD into your browsers address bar
- *If using an emonBase and hostname does not work, look up its IP address from your router or use the Fing Network Discovery tool on [Android](https://play.google.com/store/apps/details?id=com.overlook.android.fing&hl=en_GB) and [iOS](https://itunes.apple.com/gb/app/fing-network-scanner/id430921107?mt=8)*.

You should now see the emoncms user login page. Register a new account and then continue to the next step [Log Locally](../emoncms/intro-rpi.md) to configure your system.

## Option 3: Connect to Ethernet and then configure Wifi

An alternative approach to WiFi setup is to connect first using Ethernet and then use the Emoncms WiFi module to configure the WiFi connection. Start by following the Ethernet steps above. Create an emoncms account, login and navigate to **Setup > WiFi**:

Network scan should happen automatically and show the available WiFi networks:

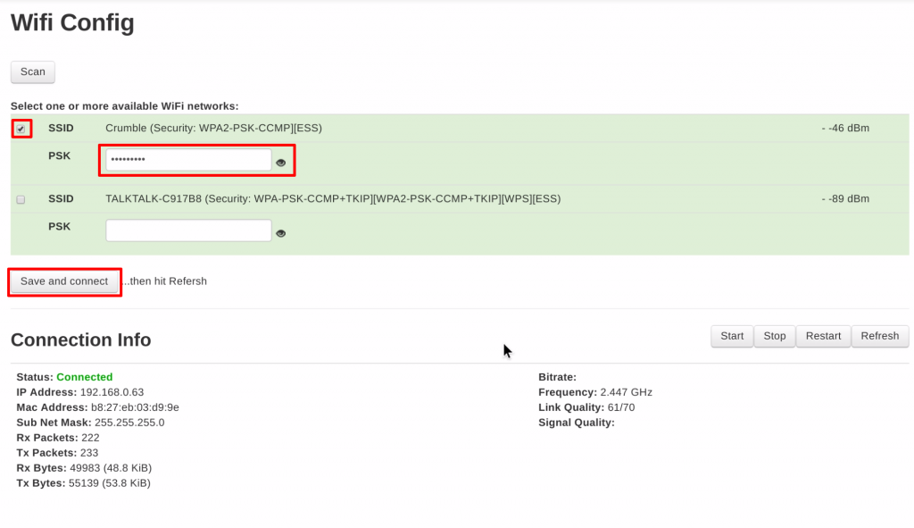
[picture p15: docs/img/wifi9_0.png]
Connect to Wifi


Check the box to select the network(s) you want to connect to. Enter the PSK password and then click `Save and Connect`.

After a few seconds 'Connection Info' should refresh automatically to report `Status: Connected` and after a few more seconds the IP address should appear.

## Advanced: Assign static 

If local static IP address is required the easiest way is to allow IP address to be given via DHCP then fix the IP address on the router. Not all routers support this.

Alternatively to set a static IP address on the emonPi itself connect via SSH and edit /etc/network/interfaces. E.g the following commands will SSH into emonPi, create backup of the interfaces file then setup a static IP on Ethernet. For WiFi change eth0 to wlan0.

    ssh pi@192.168.X.X
    sudo cp /etc/dhcpcd.conf /etc/backup_dhcpcd.conf
    sudo nano /etc/dhcpcd.conf

Append to the end of dhcpcd.conf (change to suit your network and interface required static IP):

    interface eth0
    static ip_address=192.168.0.10/24
    static routers=192.168.0.1
    static domain_name_servers=192.168.0.1

    interface wlan0
    static ip_address=192.168.0.200/24
    static routers=192.168.0.1
    static domain_name_servers=192.168.0.1

    [CTRL + X] then Y to save and exit nano
    sudo reboot

[For more info see Tutorial - How to give your Raspberry Pi a Static IP Address](http://www.modmypi.com/blog/tutorial-how-to-give-your-raspberry-pi-a-static-ip-address)

If required the changes above to dhcpcd.conf can be made by inserting the SD card into a Linux computer and editing the file directly if working offline.

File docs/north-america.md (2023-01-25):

# Use in North America

The emonPi / emonTx hardware units are designed for use on single-phase systems. However, the they can be used on a North American Split-Phase system with the following considerations:

## 1. Ensure clip-on CT sensor will fit your conductors

Typical residential Service Entrance Wires are AWG 2/0 Copper or AWG 4/0 Aluminium.  The opening in the [standard clip-on CT sensor sold in the OpenEnergyMonitor shop](http://shop.openenergymonitor.com/100a-max-clip-on-current-sensor-ct/) is **13mm**, and hence can accommodate a maximum wire size of **AWG 1/0**. Therefore, we recommend you measure the diameter of your feeders before purchasing a CT sensor.

If the standard CT sensor does not fit your conductors there are two options:

1. Use an [Optical Pulse Sensor](https://shop.openenergymonitor.com/optical-utility-meter-led-pulse-sensor/) instead of CT sensor to interface directly with a utility meter. This will give an accurate reading of energy consumed (kWh) but will not provide a real-time power reading (W).

2. Use an alternative larger CT sensor: It's possible to obtain larger CT sensors. However, using an alternative CT will usually require re-calibration and possibly, hardware modification (burden resistor may need replacement). See [Learn > emonTx in North America](../electricity-monitoring/ac-power-theory/use-in-north-america.md) for more info. Please search / post on the [community forums](https://community.openenergymonitor.org) for further assistance.

```{warning}
Installing clip-on CT sensors on USA electrical systems should only by undertaken by a professional electrician. In a typical residential installation, even if the main breaker is switched off, the load center Service Entrance Wires and bus bars are always live.
```

## 2. Use USA AC-AC Adapter

Use the [USA AC-AC voltage sensor adapter sold via the OpenEnergyMonitor Shop](http://shop.openenergymonitor.com/ac-ac-power-supply-adapter-ac-voltage-sensor-us-plug). The system has been calibrated to work with this adapter. Using any other adapter will usually require re-calibration.

## 3. Software Calibration

a) emonPi: Set EmonHub USA Calibration in the `[[RFM2Pi]]` interfacer section of `emonhub.conf` set: `calibration=110v`.

`emonhub.conf` can be edited directly in local Emoncms as described in [EmonHub > Overview](../emonhub/overview.md). See [[[RFM2Pi]] section of emonHub configuration guide](../emonhub/configuration.md) for advanced emonhub config info.

b) emonTx: Enable USA calibration using [on-board DIP switch](../emontx3/configuration.md)

## 4. Sum power values

If monitoring a split-phase system the power values from each leg can be summed in Emoncms to calculate the total power.

The emonPi by default reports `power1_plus_power2`, this input will need to be logged to a feed. See [Setup > Logging Locally](../emoncms/intro-rpi.md).

If using emonTx then the power values from multiple CT inputs can be summed in Emoncms using `+ feed` Input Processor.

See [Learn > emonTx in North America](../electricity-monitoring/ac-power-theory/use-in-north-america.md) for further technical info about the USA system.

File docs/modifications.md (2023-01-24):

# Modifications

## Adding a Real Time Clock (RTC)

The emonPi updates its internal linux time via NTP when connected to the internet. However, if the emonPi is used in an offline network, or an accurate time stamp is essential, a hardware Real Time Clock (RTC) can easily be added to the Pi's GPIO. We have tested using a [DS3231 based RTC module](http://thepihut.com/products/mini-rtc-module-for-raspberry-pi). This RTC module communicates  with the emonPi via I2C, it can be easily connected as follows by soldering a five-pin header onto the emonPi aux GPIO pins: 

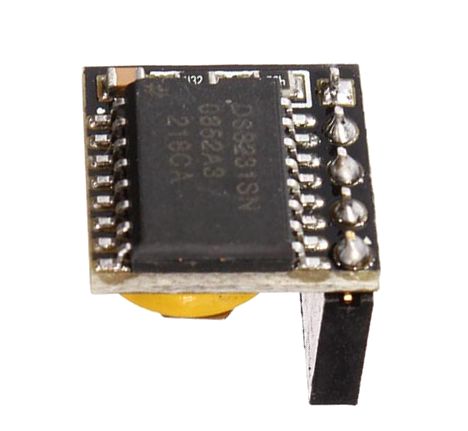
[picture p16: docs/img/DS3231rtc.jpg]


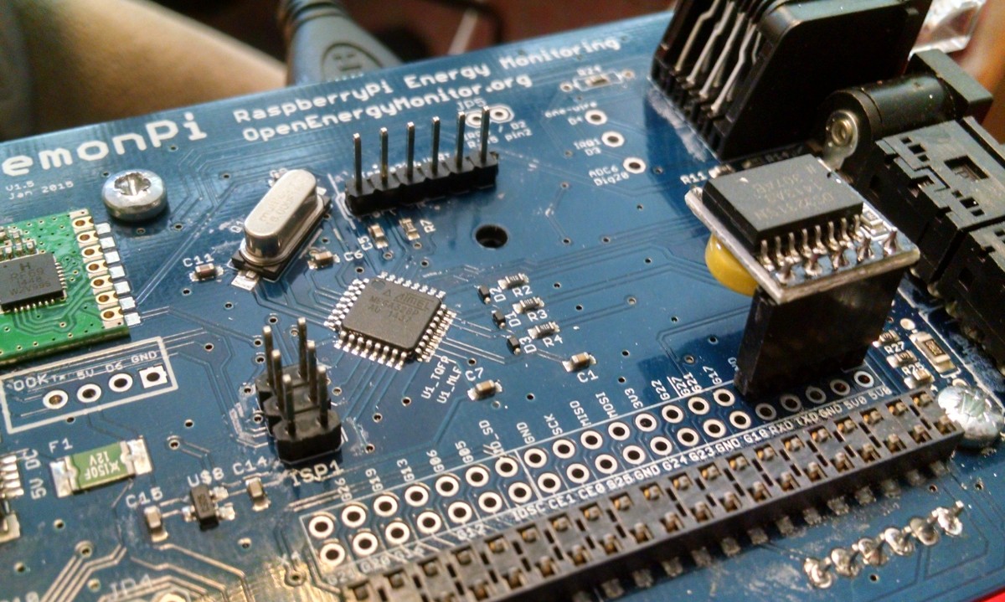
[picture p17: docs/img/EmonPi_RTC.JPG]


Once connected, check it's detected on the I2C bus by running:

    sudo i2cdetect -y 1

If the RTC is successfully detected it should return the following: 

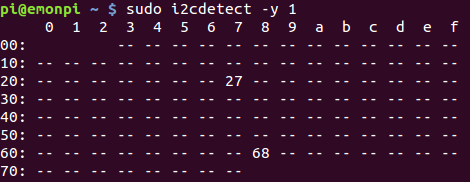
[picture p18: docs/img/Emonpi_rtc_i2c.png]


**0x27** is the emonPi's I2C LCD display and 0x68 is the RTC module.

To setup the DS3231 RTC:

    git clone https://github.com/Seeed-Studio/pi-hat
    cd pi-hats/tools
    sudo ./install.sh -u rtc_ds3231
    sudo reboot

When the RTC has been successfully installed, the output of `sudo i2cdetect -y 1` should show "UU" insted of "68" that is showed previously before the RTC was installed.
 
Read hardware clock and print result

    sudo hwclock -r

Set the system time from the hardware clock

    sudo hwclock -s

Set the hardware clock from the current system time

    sudo hwclock -w

Access help for more usage

    hwclock --help

## LightWaveRF OOK

*Guide below copied for posterity from old wiki, we havent tried this for some time and the steps below may need modification to work on more recent emonSD images.*

[OOK (On-Off-Keying)](http://en.wikipedia.org/wiki/On-off_keying) is a simple RF modulation commonly used by RF controled remote plugs. With the addition of a OOK module the emonPi can be used to control RF plugs. 

This documentation is focused on controlling LightWaveRF plugs & dimmers however it would possible to control other OOK plugs with the correct protocol e.g FS20. The LightWaveRF OOK protocol has been reverse engineered and open-sourced. 

There is a development comunity at [http://lightwaverfcommunity.org.uk](http://lightwaverfcommunity.org.uk).

Thanks to [Lawrie Griffiths](https://github.com/lawrie)/[Geek Grandad blog](https://geekgrandad.wordpress.com) for creating [LightWaveRF Arduino library](https://github.com/lawrie/LightwaveRF) and porting it to [Raspberry Pi with MQTT service](https://github.com/openenergymonitor/lightwaverf-pi). 

The OOK transmitter footprint is (from left to right): ANT, 5V, D6 + (on emonPi V1.6 GPIO18 / Pin 12), GND.

The OOK transmitter data line is connected to Dig 6 of ATmega328 and on current rev of emonPi (V1.6 - sold since Nov 2015) the OOK is also be connected directly to to GPIO 18 (pin 12) and the antenna connection of the OOK module can be jumpered to share the main SMA emonPi antenna.

OOK Tx module footprint on emonPi V1.6:

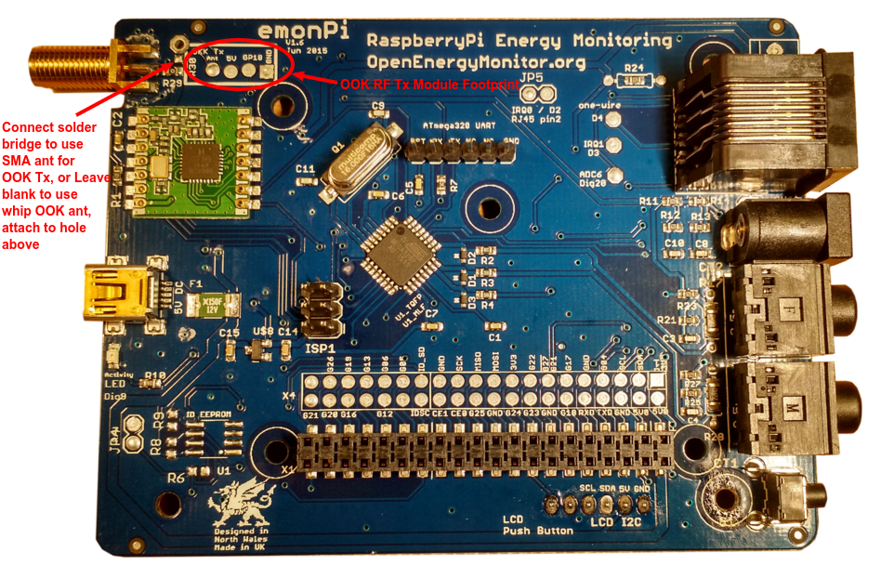
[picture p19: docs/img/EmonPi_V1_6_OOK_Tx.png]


OOK Tx module hacked onto the older emonPi V1.5 (sold pre Nov 2015), the white wire connects to OOK RF antenna to the SMA antenna. A separate antenna could be used. The red wire connects the OOK Data pin to GPIO 18 (labeled G18):

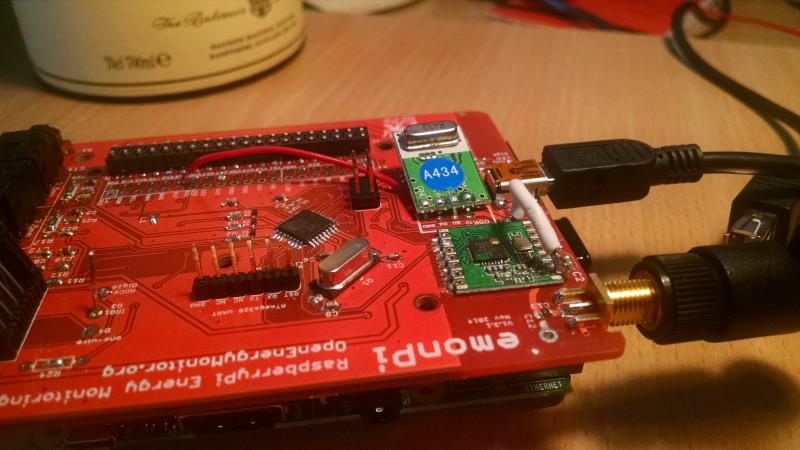
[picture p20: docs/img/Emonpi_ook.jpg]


Installation (process needs review):

    git clone https://github.com/lawrie/lightwaverf-pi.git
    cd lightwaverf-pi
    make
    sudo make install
    sudo service lwrfd start
    sudo update-rc.d lwrfd defaults

LWRF plugs can be controlled by publishing to 'lwrf' MQTT topic. 

The message format is `<channel> <command> [<level>]`, where channel is 1-16, command is 0-2 (2 means mood), and level is 0-31 (used for dimmers).

E.g publishing “1 1” to 'lwrf' topic turns channel 1 on and “1 0” turns it off. 

Plugs can be paired with the emonPi in the usual LightwaveRF way: Either press and hold pairing button (if button exists) or turn on the plug from main power and send 'on' command. Most LightWaveRF plugs allow multiple (up to 6) control devices to be paired. 

To reset the plug and delete all pairing, press and hold the pairing button to enter pairing mode, then press and hold again to erase memory. Then press (don't hold) once to confirm. For plugs without a pairing button, turn on the plug from the mains power, then in the first few seconds, press the 'all off' button on the RF remote. 

**Emulate Remote**

The LightWaveRF Pi MQTT emulates a LightWaveRF remote with the following default ID: `byte id[] = {0x6f,0xed,0xbb,0xdb,0x7b,0xee};`. If you want to be able to control your plugs with either YOUR LightWaveRF remote or the emonPi you will need to capture the unique ID of your remote. To do this you will need an [OOK receiver module](http://uk.rs-online.com/web/p/lower-power-rf-modules/6172044) and an Arduino running the [lwrf receive sketch](https://github.com/lawrie/LightwaveRF/tree/master/examples/lwreceive). The ID is the last 6 bytes of the transmission. Once captured replace the ID in [mqrfmqtt.c](https://github.com/lawrie/LightwaveRF/tree/master/examples/lwreceive) with your remote's ID then recompile (make, sudo make install).

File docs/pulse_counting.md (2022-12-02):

# Pulse counting

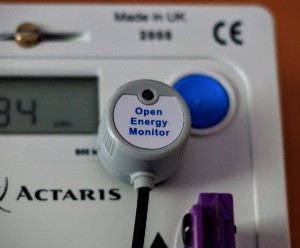
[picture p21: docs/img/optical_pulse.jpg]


Many meters, including single phase, 3-phase, import and export electricity meters, gas meters, water meters and heat meters, have pulse outputs. The pulse output may be a flashing LED or a relay (typically solid state) or both.

Using an Optical Pulse Sensor it is possible to detect the LED / IR 'pulse' output from a utility meters. Meters with wired pulse outputs can be connected directly with two wires and usually switch a voltage provided by the monitoring hardware.

In the case of an electricity meter, a pulse output corresponds to a certain amount of energy passing through the meter (kWh/Wh). For single-phase domestic electricity meters e.g. Elster A100c, each pulse typically corresponds to 1 Wh (1000 pulses per kWh). Water and gas meters will usually be marked to show the quantity of water (litres/gallons) or gas (cubic meters/cubic feet) that each pulse represents.

- The emonPi has one spare interrupt pulse input as standard (IRQ 1, Dig3) which can be used for pulse counting.
- This pulse input is accessible via the RJ45 socket.

Unlike clip-on CT based monitoring, pulse counting is measuring exactly what the utility meter is measuring i.e. what you get billed for. Pulse counting cannot provide an instantaneous power reading like clip on CT sensors can. It is often worthwhile using pulse counting in conjunction with clip on CT sensors to get the best of both techniques.

The emonPi can simultaneously perform pulse counting and CT based monitoring.

```{note}
Some meters are configured to pulse on both import and export. If your meter is, and you use it for both (e.g. an import meter on a property with grid-connected Solar PV) then you will have difficulty making good use of an optical pulse sensor, as it will not agree with either the meter reading or any CT sensor measurement.

One possibility is to use the sign (positive or negative) of the output of a CT sensor attached to the meter's input (or output) to distinguish between positive and negative pulses. You can then either reject negative pulses, or count them separately if you wish.

<a href="https://community.openenergymonitor.org/t/large-discrepancy-between-pulse-counter-and-ct/10561">This community forum discussion</a> contains more information on how to do this.
```

## Option 1: Using an Optical pulse sensor

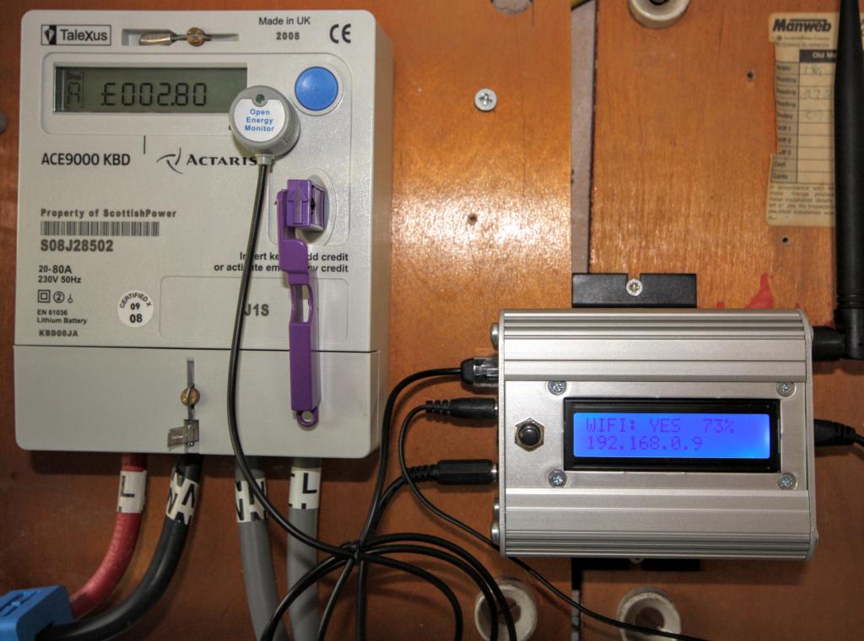
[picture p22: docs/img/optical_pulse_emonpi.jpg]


```{warning}
It is advisable to shield the sensor and the meter from bright light as this can adversely affect readings.
```

1. Identify your utility meter's pulse output, usually a red flashing LED marked 'kWh'. Stick the sensor over the LED, carefully aligning the hole so the flashing LED shines through clearly. Be sure to clean any dust from the meter face before attaching the sensor.

2. Plug sensors RJ45 connector into emonPi / emonTx RJ45 socket.

```{warning}
Ensure the sensor is plugged into the RJ45 socket on the emonPi on the same side as the CT connection jack-plug sockets NOT the Etherent socket.
```

If installed correctly when the emonPi / emonTx is powered up the pulse sensor LED should flash in sync with the utility meter LED. See video clip:

*You may need to switch on a large electrical load e.g. kettle to generate some pulses*

<div class='videoWrapper'>
<iframe width="560" height="315" src="https://www.youtube.com/embed/vq5EmMRrOY0" frameborder="0" allowfullscreen></iframe>
</div>

*Note: If the pulsecount value in emoncms does not increase in line with LED flashes, it maybe that there is light from another source interfering with the pulse detection. Some meters have a plastic cover that makes it quite hard to keep external light away from the pulse sensor. See forum thread [here](https://community.openenergymonitor.org/t/first-try-with-emonpi-pulsecount-stuck-at-1/7375) for more details.*

## Option 2: Wired pulse counting

To connect to a meter with a wired pulse output it's possible to either wire the pulse output cable directly to a RJ45 passthrough connector or to a RJ45 to terminal block adapter. The screenshot below shows an example with a simple RJ45 passthrough connector.

**RJ45 Pinout**<br>
The RJ45 implements a standard pinout used by other manufacturers of DS18B20 temperate sensing hardware such as Sheepwalk Electronics.

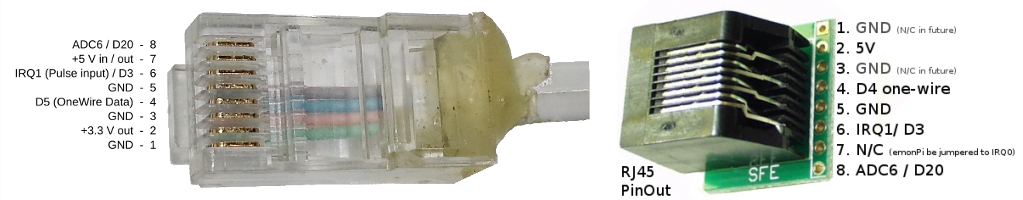
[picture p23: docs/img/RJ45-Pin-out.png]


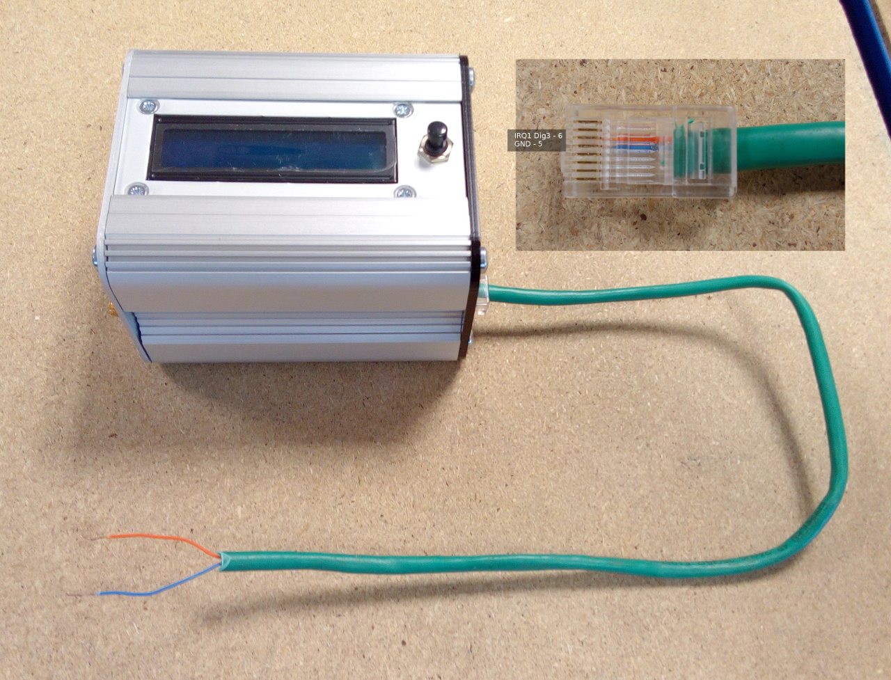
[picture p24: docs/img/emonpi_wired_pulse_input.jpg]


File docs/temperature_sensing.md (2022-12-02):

# Temperature sensing

The emonPi supports temperature sensing using DS18B20 one-wire digital temperature sensors. The standard firmware on the emonPi supports up to 6x temperature sensors.

The emonPi has a special RJ45 socket to which either a single RJ45 DS18B20 temperature sensor can be connected directly or multiple sensors can be connected via either a RJ45 breakout board or terminal block breakout board. 

## Example: 4x temperature sensors and a RJ45 breakout

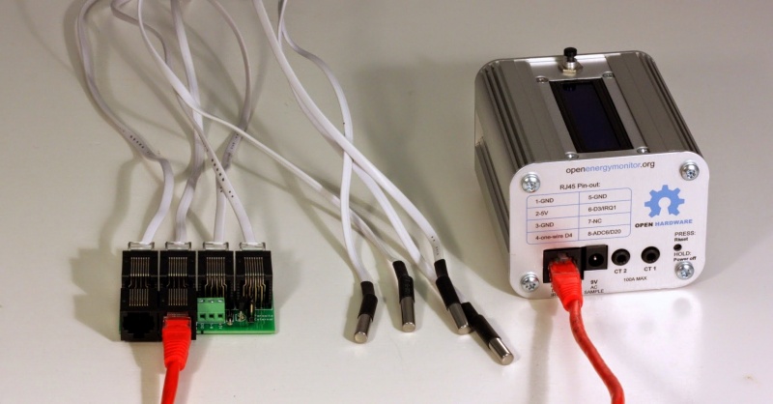
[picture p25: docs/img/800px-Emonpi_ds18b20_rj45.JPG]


- [Shop: RJ45 Encapsulated DS18B20 temperature sensor](http://shop.openenergymonitor.com/rj45-encapsulated-ds18b20-temperature-sensor/)
- [Shop: emonPi / emonTx RJ45 Expander for DS18B20 & Pulse Sensors](https://shop.openenergymonitor.com/rj45-expander-for-ds18b20-pulse-sensors/)
- [An RJ45 coupler can be used to extend RJ45 sensor cables.](http://www.sheepwalkelectronics.co.uk/product_info.php?cPath=26&products_id=36)

## RJ45 Pinout

The RJ45 implements a standard pinout used by other manufacturers of DS18B20 temperate sensing hardware such as Sheepwalk Electronics.



*Note: The RJ45 socket does not support power supply switching via Dig19 (ADC5) as described above.*

## Further reading

If you are using temperature sensors with heating systems such as heat pumps the following blog post by John Cantor provides a number of useful mounting suggestions: [John Cantor's Blog: Temperature sensors for monitoring heat pumps](https://heatpumps.co.uk/2015/06/08/temperature-sensing-with-openenergymonitor)

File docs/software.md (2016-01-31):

# emonPi Software Stack

The emonPi shield is an ATmega328 (with Arduino Uno serial bootloader) based energy monitoring shield for the Raspberry Pi, in addition to doing energy and temperature monitoring on board it also has a RFM69 radio transciever module for receiving and sending data to other wireless nodes. The software running on the emonPi shield is a combination of the [RFM12demo](http://jeelabs.net/projects/jeelib/wiki/RF12demo) example using [JeeLib](https://github.com/jcw/jeelib) RFM69 driver developed by [JeeLabs](http://jeelabs.org/) and the energy monitoring and temperature monitoring code seen on the [emonTx V3](https://github.com/openenergymonitor/emonTxFirmware/tree/master/emonTxV3) using the [EmonLib](https://github.com/openenergymonitor/emonlib) energy monitoring library. Data generated by the emonPi shield and received/sent from the RFM69 network is transferred to the Raspberry Pi via the internal serial port (/dev/ttyAMA0) using [JeeLib packet format](http://jeelabs.net/projects/jeelib/wiki/RF12demo#Output-format): space seperated byte value string used by the JeeLabs RFM12demo example.

On the Raspberry Pi the serial port that connects to the emonpi shield is read by emonhub, from emonhub's perspective the emonpi shield appears as any other wireless node. Node data read from the serial port looks like this:

    OK 10 0 100 0 200 0 100          (emonTx V3 data received via rfm69i transceiver)
    OK 5 0 1 0 2 0 3                 (emonpi shield data generated on the shield)

The source of the data is distinguished by the node ID, which is the first number after the OK. Every number after the OK and the nodeid is a byte value 0 - 256.

**Why byte value string?**

The origin of the reason data is received from RFM12demo as a byte value string is that structures are used to build the RFM packet on the wirless nodes. Using structures makes it possible to send data with much fewer bytes than sending data as a string. A typical structure definition on the emontx looks like this:

    typedef struct { int power1, power2, power3, power4, Vrms, temp; } PayloadTX;

In the emonTx structure every variable happens to be an 2 byte integer so the first 2 bytes of the payload will be power1, the next two bytes power2 and so on. When the rf payload data is received by the RFM transciever its just a series of bytes which then need to be converted back to their real values. This series of bytes is the space seperated byte value string sent from the emonPi shield to the Raspberry Pi serial port which is then decoded by emonHub.

### emonHub

The byte value string is decoded back into real values in the EmonHubJeeInterfacer in emonHub according to the decoder specification in emonhub.conf

    [[15]]
        nodename = EmonPi
        firmware = emonPi_RFM69CW_RF12Demo_DiscreteSampling.ino
        hardware = emonpi
        [[[rx]]]
            names = power1,power2,pulseCount,Vrms,T1,T2,T3,T4,T5,T6
            datacode = h
            scales = 1,1,1,0.01,0.01,0.01,0.01,0.01,0.01,0.01
            units = W,W,"",V,C,C,C,C,C,C
        [[[tx]]]
 
The real values are then made available via an internal bus for other emonhub interfacers to use.

The MQTT Interfacer published the node data to the mosquitto MQTT server running on the emonpi. The topic string contains the nodeid and specifies that its received (rx) data.

    topic            csv values
    emonhub/rx/10    100,200,300
    emonhub/rx/15    1,2,3
    
The MQTT Interfacer also subscribes to topics starting with:

    emonhub/tx/#
    
The topic emonhub/tx/nodeid is used to send data from emoncms or other applications on the emonpi back up to the emonpi shield or the rfm network, designed to be used for control.

### emonPi LCD

The emonPi LCD script subscribes to the emonhub/rx/# topics directly in order to print the power values to the emonPi LCD display.

### Low-write-v8.5 emoncms on the emonpi

The emonpi will have the low write version of emoncms that's running locally enabled by default rather than needing to be enabled as was the case in the previous raspberrypi sd card image.

Even if the local emoncms is not used for storing data it can be used for emonhub configuration and checking the data received from the emonpi shield and rfm network.

The local emoncms can now be used for editing the emonhub.conf file via the browser and viewing the emonhub.log to check for errors. This is intended to reduce the need to SSH into the raspberrypi.

The local emoncms subscribes to the emonhub/rx/nodeid messages published by the emonhub MQTT interfacer via the Modules/nodes/nodes_mqtt_process.php script or emoncms-nodes-service script. This script also reads the nodename, firmware, hardware and variable names and units from emonhub.conf which is used to provide this information in the nodes interface.

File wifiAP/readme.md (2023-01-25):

This guide details how to setup the emonPi to broadcast a WIFI Hotspot using the Edimax EW-7811UN (rtl871xdrv chipset) USB WIFI adapter to make it possible to connect directly to an EmonPi from a tablet or computer without the need for a router or internet connection. 

Bridging Ethernet (eth0) and 3G GSM modems (eth1) using NAT is also covered. The allows the emonPi to function as a 3G router while also being able to access local emoncms. Perfect for remote installations.

This guide was put together using a Pi2 running emonPi SD card `emonSD-20Feb16` based on `RASPBIAN JESSIE LITE (2015-11-21). Kernel 4.1.18`.

There are 4 pieces of software that need to be installed to get this to work:

1. hostapd – WIFI Hotspot
2. edimax version of hostapd
3. isc-dhcp-server – DHCP Server
4. iptables - NAT (link network interfaces) 

# 1) Install dhcp server 

	sudo apt-get install isc-dhcp-server 

# 2) Install Hostapd

If your using **RasPi3 or official RasPi Wifi dongle - nl80211 chipset** with the brcmfmac driver simply 

	sudo apt-get install hostapd
	
If using **Edimax EW-7811UN (rtl871xdrv chipset)** need to use latest version of hostapd (which requires compile) which supports rtl871xdrv in AP mode.

```
sudo apt-get install libnl-genl-3-dev libnl-3-dev
git clone https://github.com/lostincynicism/hostapd-rtl8188
cd hostapd-rtl8188/hostapd
sudo make
sudo make install
``` 

check vesion :

	pi@emonpi:~ $ hostapd -v
	hostapd v2.4 for Realtek rtl871xdrv

# 3) Configure /etc/network/interfaces

Open the network interfaces file to edit:

	sudo nano /etc/network/interfaces

Replace content with:

```
auto lo
iface lo inet loopback

auto eth0
allow-hotplug eth0
iface eth0 inet manual

#allow-hotplug wlan0
#iface wlan0 inet manual
#    wpa-conf /etc/wpa_supplicant/wpa_supplicant.conf

iface wlan0 inet static
address 192.168.42.1
netmask 255.255.255.0

allow-hotplug eth1
iface eth1 inet dhcp
```

# 4) Configure /etc/hostapd/hostapd.conf

Open hostapd config file with:

	sudo nano /etc/hostapd/hostapd.conf

Add the following lines to hostapd.conf (set SSID and password of your choice)

WITHOUT AUTHENTICATION  USE - for **Edimax EW-7811UN (rtl871xdrv chipset**
```
interface=wlan0
ssid=emonPi
driver=nl80211
hw_mode=g
channel=6
wmm_enabled=0
```

WITHOUT AUTHENTICATION  -if using **RasPi3 or official RasPi Wifi dongle - nl80211 chipset with the brcmfmac driver**
```
interface=wlan0
ssid=emonPi
driver=nl80211
hw_mode=g
channel=6
wmm_enabled=0
```

WITH AUTENTICATION USE - for **Edimax EW-7811UN (rtl871xdrv chipset)**

```
interface=wlan0
driver=rtl871xdrv
ssid=emonPi
hw_mode=g
channel=6
macaddr_acl=0
wmm_enabled=0
auth_algs=1
ignore_broadcast_ssid=0
wpa=2
wpa_passphrase=raspberry
wpa_key_mgmt=WPA-PSK
wpa_pairwise=TKIP
rsn_pairwise=CCMP
```
WITH AUTENTICATION  - if using **RasPi3 or official RasPi Wifi dongle - nl80211 chipset with the brcmfmac driver**

```
interface=wlan0
driver=nl80211
ssid=emonPi
hw_mode=g
channel=6
macaddr_acl=0
wmm_enabled=0
auth_algs=1
ignore_broadcast_ssid=0
wpa=2
wpa_key_mgmt=WPA-PSK
wpa_passphrase=raspberry
rsn_pairwise=CCMP
```

Manual start to test everything is working, you should see a Wifi network called `emonPi` and password `raspberry`

	sudo hostapd -dd /etc/hostapd/hostapd.conf

#5) Configure /etc/default/hostapd

	sudo nano /etc/default/hostapd

Set

	DAEMON_CONF="/etc/hostapd/hostapd.conf"

	6) Configure /etc/dhcp/dhcpd.conf

Open dhcpd config file:

	sudo nano /etc/dhcp/dhcpd.conf

Add the following to the end of the file:

```
lease-file-name "/home/pi/data/dhcpd.leases";
subnet 192.168.42.0 netmask 255.255.255.0 {
        range 192.168.42.2 192.168.42.20;
        option broadcast-address 192.168.42.255;
        option routers 192.168.42.1;
        default-lease-time 600;
        max-lease-time 7200;
        option domain-name "local";
        option domain-name-servers 8.8.8.8, 8.8.4.4;
}
```

comment out: 

	#option domain-name "example.org";

	#option domain-name-servers ns1.example.org, ns2.example.org;

uncomment

	authoritative;

Save and exit. 

## Create dhcpd.leases in ~/data 

	sudo touch /home/pi/data/dhcpd.leases

# 7) Configure /etc/default/isc-dhcp-server

	sudo nano /etc/default/isc-dhcp-server 

Remove the comment from DHCPD_CONF, DHCPD_PID and then set the INTERFACES to "wlan0" (including ""), see example below:

```
# Defaults for isc-dhcp-server initscript 
# sourced by /etc/init.d/isc-dhcp-server 
# installed at /etc/default/isc-dhcp-server by the maintainer scripts 
# 
# This is a POSIX shell fragment 
# 

# Path to dhcpd's config file (default: /etc/dhcp/dhcpd.conf). 
DHCPD_CONF=/etc/dhcp/dhcpd.conf 

# Path to dhcpd's PID file (default: /var/run/dhcpd.pid). 
DHCPD_PID=/var/run/dhcpd.pid 

# Additional options to start dhcpd with. 
#       Don't use options -cf or -pf here; use DHCPD_CONF/ DHCPD_PID instead 
#OPTIONS="" 

# On what interfaces should the DHCP server (dhcpd) serve DHCP requests? 
#       Separate multiple interfaces with spaces, e.g. "eth0 eth1". 
INTERFACES="wlan0"
```

# 8.) Setup NAT forwarding 

To bridge eth0 the wlan0 while still allowing us to access the Pi via SSH (pure network bridge does not)

To set this up automatically on boot, edit the file /etc/sysctl.conf and 

	sudo nano /etc/sysctl.conf

Add the following line to the bottom of the file:

	net.ipv4.ip_forward=1

Second, to enable NAT in the kernel, run the following commands to bridge eth0 the wlan0:
```
sudo iptables -t nat -A POSTROUTING -o eth0 -j MASQUERADE
sudo iptables -A FORWARD -i eth0 -o wlan0 -m state --state RELATED,ESTABLISHED -j ACCEPT
sudo iptables -A FORWARD -i wlan0 -o eth0 -j ACCEPT
```

If bridge is also required to eth1 (for 3G dongle) also add:
```
sudo iptables -t nat -A POSTROUTING -o eth1 -j MASQUERADE
sudo iptables -A FORWARD -i eth1 -o wlan0 -m state --state RELATED,ESTABLISHED -j ACCEPT
sudo iptables -A FORWARD -i wlan0 -o eth1 -j ACCEPT
```
Save the iptables rules to /etc/iptables.ipv4.nat

	sudo sh -c "iptables-save > /etc/iptables.ipv4.nat"

Now edit the file /etc/network/interfaces and add the following line to the bottom of the file:

	up iptables-restore < /etc/iptables.ipv4.nat

This did not work for me I had to also add entry to rc.local to load iptables (see below)

# 8) Edit /etc/rc.local

	sudo nano /etc/rc.local

Add before exit 0:

```
sudo iptables-restore < /etc/iptables.ipv4.nat
sudo ifconfig wlan0 192.168.42.1
sudo service isc-dhcp-server restart
```

# 9) Start services at boot

	sudo update-rc.d isc-dhcp-server defaults
	sudo update-rc.d hostapd defaults

Thats it restart your emonpi/emonbase to finish and then connect to network emonPi with password: raspberry

# 11) Add a Real Time Clock (RTC)
When running an emonPi in offline mode we recommend adding a hardware RTC to ensure the system time is always correct. See [emonPi modifications](https://docs.openenergymonitor.org/emonpi/modifications.html)

# Operation 

Once your up and running and connected to emonPi hotspot you should be able to browse to [http://192.168.42.1/emoncms](http://192.168.42.1/emoncms) to acess local Emoncms

# Automated Operation

I've made a script to start and stop WiFi AP mode. 

It works starting WiFi AP when emonPi is in normal Wifi mode without any rebooting and then when AP is stopped normal client mode is resumed.

The script also bridges eth1 (USB 3G dongle) to the WiFi AP. This will be useful when using emonPi with 3G dongle, this will allow a local user to connect to the emponPi via Wifi AP, to connect via SSH, view data locally and even get internet via the 3G dongle...an emonPi 3G router! 

	sudo ln -s /home/pi/emonpi/wifiAP/wifiAP.sh /usr/local/sbin/wifiAP
	
then run 

	sudo wifiAP start

Then to stop

	sudo wifiAP stop

# Forum discussion 

https://openenergymonitor.org/emon/node/12305

# Resources 
Useful blogs, guides and forum threads that I used to work out how to set up the above:

http://www.daveconroy.com/turn-your-raspberry-pi-into-a-wifi-hotspot-with-edimax-nano-usb-ew-7811un-rtl8188cus-chipset

http://askubuntu.com/questions/140126/how-do-i-configure-a-dhcp-server
http://ubuntuforums.org/showthread.php?t=2068111

http://raspberrypi.stackexchange.com/questions/9678/static-ip-failing-for-wlan0

https://forums.opensuse.org/showthread.php/438756-DHCP-can-t-write-to-dhcpd-leases

http://elinux.org/RPI-Wireless-Hotspot

http://askubuntu.com/questions/140126/how-do-i-configure-a-dhcp-server

http://www.instructables.com/id/Raspberry-Pi-as-a-3g-Huawei-E303-wireless-Edima/?ALLSTEPS

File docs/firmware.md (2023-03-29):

# Firmware

The emonPi firmware is based on Arduino.

## Available Firmware

### [emonPi_CM](https://github.com/openenergymonitor/emonpi/tree/master/firmware/emonPi_CM): continuous sampling firmware

**New 16th Feb 2023:** This firmware provides higher accuracy continuous monitoring. Continuous monitoring means that the power readings are representative of the full 10s period that they represent rather than a short snapshot. Support for radio formats: JeeLib Native and **LowPowerLabs (recommended)**.

### [emonPi_DS_jeelib_classic](https://github.com/openenergymonitor/emonpi/tree/master/firmware/emonPi_DS_jeelib_classic): discrete sampling firmware

The original emonPi firmware, this performs power measurement in short discreet snapshots ~300ms long per CT channel at 50Hz per 10s period. Compatible with the original jeelib classic radio format.

## Updating firmware directly from the emonPi user interface

The easiest way of updating the emonPi firmware is to use the firmware upload tool available at `Setup > Admin > Update > Firmware`.

Select port: `ttyAMA0` and Hardware: `emonPi`. Then depending on which firmware variant you wish to upload as described above select the radio format and firmware as required.

Click `Update Firmware` to upload the firmware.



## How to compile and upload firmware

It is also possible to compile and upload the emonPi firmware (Instructions need to be added here on how to compile and upload directly on an emonPi).

### PlatformIO Command Line

PlatformIO works great from the command line. See the excellent [PlatformIO Quick Start Guide](https://docs.platformio.org/en/latest/core/installation/index.html#super-quick-mac-linux) for installation instructions.

**Compile and upload emonPi_CM Continuous Sampling firmware**

    git clone https://github.com/openenergymonitor/emonpi
    cd emonpi/firmware/emonPi_CM
    pio run
    
**Compile and upload emonPi_DS_jeelib_classic Discrete Sampling firmware**

    git clone https://github.com/openenergymonitor/emonpi
    cd emonpi/firmware/emonPi_DS_jeelib_classic
    pio run

**View serial port with PlatformIO CLI**

    pio device monitor

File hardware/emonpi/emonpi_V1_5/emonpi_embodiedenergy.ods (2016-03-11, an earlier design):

EMONPI SHIELD |  | weight (g) | weight (g) |  | MJ/kg | Wh/g |  | Wh |  |  | Source |  |  | EmonPi Shield breakdown
Atmega 328 | 1 | 0.14375 | 0.14375 |  | 1787 | 496 |  | 71 |  |  | Kemma et al. 2005 | "Small" Integrated Circuits (low estimate).
10k | 1 | 0.0008 | 0.0008 |  | 2969 | 825 |  | 0.660 |  |  | Kemma et al. 2005 | Surface mounted devices and LEDs (avg.) |  | SMT Components | 100.2983847222 | 1.98%
100nf | 5 | 0.000024 | 0.00012 |  | 2969 | 825 |  | 0.099 |  |  | Kemma et al. 2005 | Surface mounted devices and LEDs (avg.) |  | SMT Crystal | 453.5972222222 | 8.95%
22pf | 2 | 0.000024 | 0.000048 |  | 2969 | 825 |  | 0.040 |  |  | Kemma et al. 2005 | Surface mounted devices and LEDs (avg.) |  | Integrated circuits | 236.1045833333 | 4.66%
16MHz crystal | 1 | 0.55 | 0.55 | metal case? | 2969 | 825 |  | 454 |  |  | Kemma et al. 2005 | Surface mounted devices and LEDs (avg.) |  | Connectors | 475.2916666667 | 9.37%
 |  |  | 0 |  |  |  |  |  |  |  |  |  |  | PCB | 2166.0416666667 | 42.72%
LED | 1 | 0.005897 | 0.005897 |  | 2969 | 825 |  | 4.863 |  |  | Kemma et al. 2005 | Surface mounted devices and LEDs (avg.) |  | Assembly | 1639.4444444445 | 32.33%
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

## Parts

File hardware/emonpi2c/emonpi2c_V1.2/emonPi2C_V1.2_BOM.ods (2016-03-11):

Qty | Part | Value | Package | Order Code | Notes
3 | R1, R2, R3, R5 | 4.7K | R0603
1 | R4 – Pot | 10k Pot | 3-pin thru hole pot | 850-9643 | Optional – on rear
1 | R6 | 1.3K | R0603
1 | C1 | 0.1uF | C0603
1 | C2 | 1uF | C0603
1 | S1 | 9.5mm | TACTILE-PTH
1 | SV1 | 6-pin | 2.54mm | 78-0625 | Straight?
1 | T1 | 850 | SOT23 | 739-0303
1 | U1 | PCF8574T/3 | SOIC16 | 517-0671
1 | X1 | HD44780LCD-1602 | LCD1602
Mounting Kit
4 | Screws | 20mm screw | counter sunk | 33-2960
4 | Spacer | 5mm | threaded | 33-3540
4 | Nut | M3 | Locking | 33-4402

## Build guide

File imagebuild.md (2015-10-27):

### Raspbian

Download the official raspberrpi raspbian image and write to the SD card.

[http://www.raspberrypi.org/downloads](http://www.raspberrypi.org/downloads)
    
To upload the image using dd on linux 

Check the mount location of the SD card using:

    df -h
    
Unmount any mounted SD card partitions
    
    umount /dev/sdb1
    umount /dev/sdb2
    
Write the raspbian image to the SD card (Make sure of=/dev/sdb is the correct location)

    sudo dd bs=4M if=2014-06-20-wheezy-raspbian.img of=/dev/sdb

Insert the SD card into the raspberrypi and power the pi up.

Find the IP address of your raspberrypi on your network then connect and login to your pi with SSH, for windows users there's a nice tool called [putty](http://www.putty.org/) which you can use to do this. To connect via ssh on linux, type the following in terminal:

    ssh pi@YOUR_PI_IP_ADDRESS

It will then prompt you for a username and password which are: **username:**pi, **password:**raspberry.

### Setup Data partition

Steps for creating 3rd partition for data using fdisk and mkfs:

    sudo fdisk -l
    Note end of last partition (5785599 on standard sd card)
    sudo fdisk /dev/mmcblk0
    enter: n->p->3
    enter: 5785600
    enter: default or 7626751
    enter: w (write partition to disk)
    fails with error, will write at reboot
    sudo reboot
    
    On reboot, login and run:
    sudo mkfs.ext2 -b 1024 /dev/mmcblk0p3
    
**Note:** *We create here an ext2 filesystem with a blocksize of 1024 bytes instead of the default 4096 bytes. A lower block size results in significant write load reduction when using an application like emoncms that only makes small but frequent and across many files updates to disk. Ext2 is choosen because it supports multiple linux user ownership options which are needed for the mysql data folder. Ext2 is non-journaling which reduces the write load a little although it may make data recovery harder vs Ext4, The data disk size is small however and the downtime from running fsck is perhaps less critical.*

Create a directory that will be a mount point for the rw data partition

    mkdir /home/pi/data
    
### Read only mode

Configure Raspbian to run in read-only mode for increased stability (optional but recommended)

The following is copied from: 
http://emonhub.org/documentation/install/raspberrypi/sd-card/

Then run these commands to make changes to filesystem

    sudo cp /etc/default/rcS /etc/default/rcS.orig
    sudo sh -c "echo 'RAMTMP=yes' >> /etc/default/rcS"
    sudo mv /etc/fstab /etc/fstab.orig
    sudo sh -c "echo 'tmpfs           /tmp            tmpfs   nodev,nosuid,size=30M,mode=1777       0    0' >> /etc/fstab"
    sudo sh -c "echo 'tmpfs           /var/log        tmpfs   nodev,nosuid,size=30M,mode=1777       0    0' >> /etc/fstab"
    sudo sh -c "echo 'tmpfs           /var/lib/dhcp   tmpfs   nodev,nosuid,size=1M,mode=1777        0    0' >> /etc/fstab"
    sudo sh -c "echo 'proc            /proc           proc    defaults                              0    0' >> /etc/fstab"
    sudo sh -c "echo '/dev/mmcblk0p1  /boot           vfat    defaults                              0    2' >> /etc/fstab"
    sudo sh -c "echo '/dev/mmcblk0p2  /               ext4    defaults,ro,noatime,errors=remount-ro 0    1' >> /etc/fstab"
    sudo sh -c "echo '/dev/mmcblk0p3  /home/pi/data   ext2    defaults,rw,noatime                   0    2' >> /etc/fstab"
    sudo sh -c "echo ' ' >> /etc/fstab"
    sudo mv /etc/mtab /etc/mtab.orig
    sudo ln -s /proc/self/mounts /etc/mtab
    
The Pi will now run in Read-Only mode from the next restart.

Before restarting create two shortcut commands to switch between read-only and write access modes.

Firstly “ rpi-rw “ will be the command to unlock the filesystem for editing, run

    sudo nano /usr/bin/rpi-rw

and add the following to the blank file that opens

    #!/bin/sh
    sudo mount -o remount,rw /dev/mmcblk0p2  /
    echo "Filesystem is unlocked - Write access"
    echo "type ' rpi-ro ' to lock"

save and exit using ctrl-x -> y -> enter and then to make this executable run

    sudo chmod +x  /usr/bin/rpi-rw

Next “ rpi-ro “ will be the command to lock the filesytem down again, run

    sudo nano /usr/bin/rpi-ro

and add the following to the blank file that opens

    #!/bin/sh
    sudo mount -o remount,ro /dev/mmcblk0p2  /
    echo "Filesystem is locked - Read Only access"
    echo "type ' rpi-rw ' to unlock"

save and exit using ctrl-x -> y -> enter and then to make this executable run

    sudo chmod +x  /usr/bin/rpi-ro
        
Lastly reboot for changes to take effect

    sudo shutdown -r now
    
Login again, change data partition permissions:

    sudo chmod -R a+w data
    sudo chown -R pi data
    sudo chgrp -R pi data

Install software stack:

    git clone https://github.com/openenergymonitor/emonpi.git
    ./install
    ./emoncmsinstall

Add wifi check script to run every minute to check wifi is connected. 

    sudo cp /home/pi/emonpi/wifi-check /usr/local/bin/wifi-check
    sudo chmod +x /usr/local/bin/wifi-check
    sudo crontab -e
  
add to crontab to run every 5 min:

    */5 * * * * /usr/local/bin/wifi-check > /tmp/wificheck.log 2>&1

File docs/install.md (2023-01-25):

# EmonPi Install Guide

The following guide provides an quick overview of how to setup the hardware part of an emonPi energy monitoring system for monitoring up to two AC circuits.

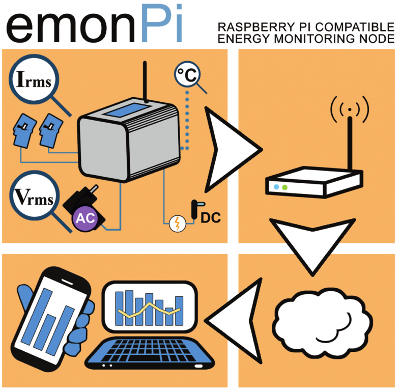
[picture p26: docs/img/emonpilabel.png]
emonpi install digram


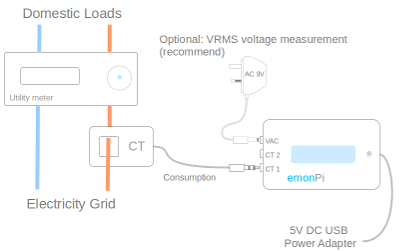
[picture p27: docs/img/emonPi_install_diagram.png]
emonpi install


```{warning}
[Please read the CT installation guide before installing.](../electricity-monitoring/ct-sensors/installation)
Your safety is your responsibility. Clip-on current sensors are non-invasive and should not have direct contact with the AC mains. However, installing the sensors will require working in close proximity to cables carrying high voltage. As a precaution, we recommend ensuring the cables are fully isolated; i.e., switch off the power prior to installing your sensors and proceed slowly with care. If you have any doubts, seek professional assistance.
```

## 1. CT sensor

- Clip the CT sensor around either the **Line** or **Neutral** cable
- Connect jack plug into either CT1 or CT2 socket on the emonPi
- If the power reading is negative, reverse the CT sensor orientation
- CT sensor cable should not be extended to avoid induced noise
- For Solar PV install see [Solar PV Application page](../applications/solar-pv.md)
- [Learn more about how CT sensors work...](https://learn.openenergymonitor.org/electricity-monitoring/voltage-sensing/measuring-voltage-with-an-acac-power-adapter)

```{note}
The clip-on CT sensors must be clipped round either the Line or Neutral AC wire. **NOT BOTH**
```

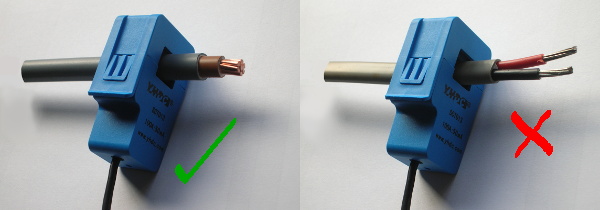
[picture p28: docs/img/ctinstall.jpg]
CT sensor installation


## 2. AC-AC Adapter

- Plug the AC-AC adapter into a power outlet
- This may require installation of a new outlet or extending an existing one
- AC-AC adapter cable can be extended if required
- Plug power connector into the AC socket on the emonPi
- Essential for [Solar PV monitoring](../applications/solar-pv.md)
- Provides AC waveform reference for accurate Real Power measurements.
- [Learn more about measuring voltage with AC-AC power adapator...](https://learn.openenergymonitor.org/electricity-monitoring/voltage-sensing/measuring-voltage-with-an-acac-power-adapter)

## 3. DC 5V USB Adapter

- Plug the DC 5V USB adapter into a power outlet
- Plug the mini-B USB connector into the emonPi
- High quality minimum [1.2A power supply recommended](https://shop.openenergymonitor.com/power-supplies/)

## 4. Optical Utility Meter LED Pulse Sensor (optional)

- See [Optical Pulse Sensor setup page](https://guide.openenergymonitor.org/setup/pulse-counting/)
- Connects to emonPi / emonTx via RJ45 connector
- Self-adhesive velcro attachment to utility meter
- One optical pulse sensor per emonPi/emonTx
- Can be used in conjunction with temperature sensors using [RJ45 Breakout](http://shop.openenergymonitor.com/rj45-expander-for-ds18b20-pulse-sensors/)

## 5. Temperature Sensors (optional)

- Connect to emonPi / emonTx via RJ45 connector.
- Up to 6x [RJ45 sensors](https://shop.openenergymonitor.com/rj45-encapsulated-ds18b20-temperature-sensor/) can be connected using the [RJ45 expander](http://shop.openenergymonitor.com/rj45-expander-for-ds18b20-pulse-sensors/).
- Up to 6x [wired sensors](https://shop.openenergymonitor.com/encapsulated-ds18b20-temperature-sensor/) can be connected using the [terminal block breakout board](https://shop.openenergymonitor.com/rj45-to-terminal-block-breakout-for-ds18b20/).
- Sensor wire can be extended using RJ45 cable and the [RJ45 Extender](http://shop.openenergymonitor.com/rj45-extender/).

## 6. Installation Examples

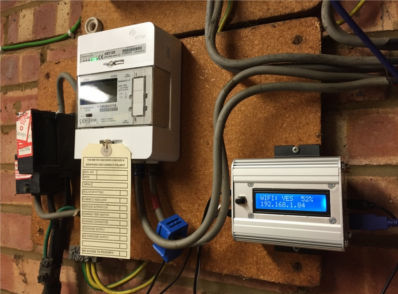
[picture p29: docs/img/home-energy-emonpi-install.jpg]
home energy


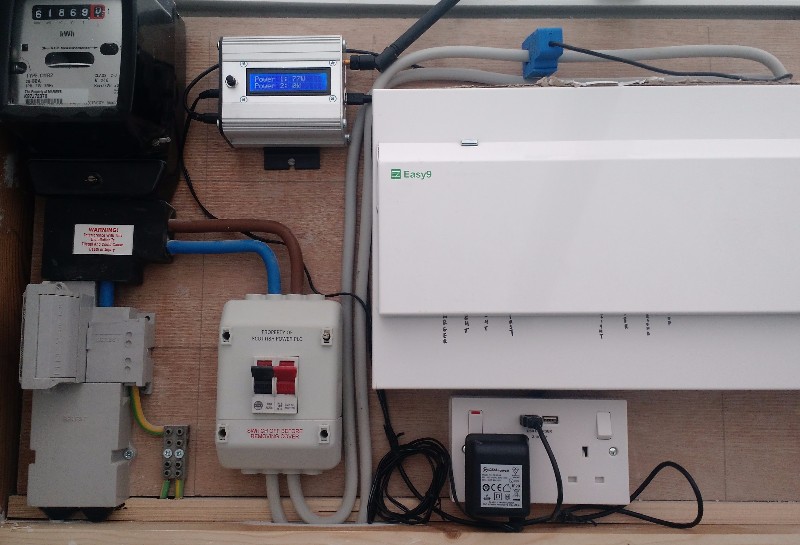
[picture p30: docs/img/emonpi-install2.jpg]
home energy2


The included clips can be used to mount the emonPi / emonTx on a wall. 

See [Solar PV Application Note](/applications/solar-pv/) for emonPi solar PV install guide & images.

## 7. Power Up

```{note}
Ensure all sensors are connected before powering up.
```

a.) **Switch on DC & AC power**

b.) **Check CT sensor(s) & AC Wave are detected:**



c.) **emonPi should remember WiFi network and re-connect**



## 8. Shutdown

Optional: Shut down the emonPi, hold down the shutdown button for 5 seconds, then wait 30 seconds for unit to fully shut down.

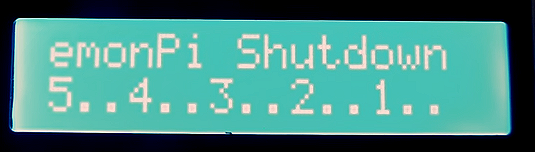
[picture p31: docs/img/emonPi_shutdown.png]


```{warning}
Unplugging power from the emonPi without following the correct shutdown procedure can result in a corrupted SD card.
```

## 9. Video Guide
<div class='videoWrapper'>
<iframe width="560" height="315" src="https://www.youtube.com/embed/6SB4fRYQjno" frameborder="0" allowfullscreen></iframe>
</div>

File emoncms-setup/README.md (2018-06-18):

## emonPi / emonBase Network setup wizard 

Network setup wizard on first-boot via Emoncms interface 

See blog post:

https://blog.openenergymonitor.org/2017/06/emonpi-network-setup-wizard/

### Install 

Setup sudoers entry

    sudo visudo -cf /home/pi/emonpi/emoncms-setup/emoncms-setup-sudoers && \
    sudo cp /home/pi/emonpi/emoncms-setup/emoncms-setup-sudoers /etc/sudoers.d/
    sudo chmod 0440 /etc/sudoers.d/emoncms-setup-sudoers
    
Install Emoncms module 

    ln -s /home/pi/emonpi/emoncms-setup /var/www/emoncms/Modules/setup

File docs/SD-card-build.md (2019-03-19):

# Archived emonSD-26Oct17 build guide

**For download: See [emonSD releases page (Git wiki)](https://github.com/openenergymonitor/emonpi/wiki/emonSD-pre-built-SD-card-Download-%26-Change-Log)**.

***

## emonPi/emonBase Resources

- [**User docs & setup guide**](http://guide.openenergymonitor.org)
- [**Purchase Pre-built SD card**](http://shop.openenergymonitor.com/emonsd-pre-loaded-raspberry-pi-sd-card/)
- [**Purchase emonPi**](shop.openenergymonitor.com/emonpi-3/)
- [**Pre-built image repository & changelog**](https://github.com/openenergymonitor/emonpi/wiki/emonSD-pre-built-SD-card-Download-&-Change-Log)

***

# emonSD Features  

- Base image RASPBIAN JESSIE LITE
- 8GB min SD card size
- Read-only root file system
- Stable Emoncms Core
- Apache web-server
- MQTT
- NodeRed
- OpenHAB

***

# Contents

<!-- toc -->

- [Initial Linux Setup](#initial-linux-setup)
  * [Update](#update)
  * [Change password, set international options & expand File-system](#change-password-set-international-options--expand-file-system)
  * [Change hostname](#change-hostname)
  * [Change Password](#change-password)
  * [Root filesystem read-only with RW data partition](#root-filesystem-read-only-with-rw-data-partition)
  * [Custom MOTD (message of the day)](#custom-motd-message-of-the-day)
  * [Memory Tweak](#memory-tweak)
- [RasPi Serial port setup](#raspi-serial-port-setup)
  * [Use custom cmdline.txt](#use-custom-cmdlinetxt)
  * [Disable serial console boot](#disable-serial-console-boot)
  * [Enable serial uploads with avrdude and autoreset](#enable-serial-uploads-with-avrdude-and-autoreset)
  * [Raspberry Pi 3 Compatibility](#raspberry-pi-3-compatibility)
- [Setup Read-only filesystem](#setup-read-only-filesystem)
- [Install emonPi Services](#install-emonpi-services)
  * [emonPi LCD service](#emonpi-lcd-service)
  * [Setup emonPi update](#setup-emonpi-update)
  * [Setup NTP Update](#setup-ntp-update)
  * [Fix Random seed](#fix-random-seed)
- [Install mosquitto MQTT](#install-mosquitto-mqtt)
- [emonHub](#emonhub)
  * [Install emonHub (emon-pi) variant:](#install-emonhub-emon-pi-variant)
- [Install Emoncms Core](#install-emoncms-core)
  * [emonPi specific Emoncms settings](#emonpi-specific-emoncms-settings)
  * [Move MYSQL database location](#move-mysql-database-location)
  * [Low write mode Emoncms optimisations](#low-write-mode-emoncms-optimisations)
  * [Install Emoncms Modules](#install-emoncms-modules)
    + [Configure Emoncms WiFi Module](#configure-emoncms-wifi-module)
      - [Install wifi-check script](#install-wifi-check-script)
    + [Setup Emoncms Backup & import module](#setup-emoncms-backup--import-module)
  * [Emoncms Language Support](#emoncms-language-support)
- [Install Emoncms MQTT input service](#install-emoncms-mqtt-input-service)
- [Lightwave RF MQTT service](#lightwave-rf-mqtt-service)
- [Configure Firewall](#configure-firewall)
- [Install NodeRED](#install-nodered)
- [Install openHAB](#install-openhab)
- [GSM HiLink Huawei USB modem dongle support](#gsm-hilink-huawei-usb-modem-dongle-support)
- [emonPi Setup Wifi AP mode](#emonpi-setup-wifi-ap-mode)
- [Symlink scripts](#symlink-scripts)
  * [emonSDexpand:](#emonsdexpand)
  * [Fstab:](#fstab)
- [Clean Up](#clean-up)
  * [Remove unused packages](#remove-unused-packages)
  * [Run Factory reset](#run-factory-reset)

<!-- tocstop -->

***

# Initial Linux Setup

## Update

	sudo apt-get update -y
	sudo apt-get upgrade -y

## Change password, set international options & expand File-system

Using raspi-config utility:

	sudo raspi-config

Raspbian minimal image is 2GB by default, expand to fill 4GB. Then reboot

## Change hostname

From 'raspberry' to 'emonpi'

	sudo nano /etc/hosts
	sudo nano /etc/hostname

## Change Password

From 'raspberrypi' to 'emonpi2016'

	sudo passwd

## Root filesystem read-only with RW data partition

## Custom MOTD (message of the day)

Use custom motd to alert users they are logging into an emonPi with RW / RO toggle instructions:

```
sudo rm /etc/motd
sudo ln -s /home/pi/emonpi/motd /etc/motd
```

## Memory Tweak

Append `gpu_mem=16` to `/boot/config.txt` this caps the RAM available to the GPU. Since we are running headless this will give us more RAM at the expense of the GPU

***

# RasPi Serial port setup

To allow the emonPi to communicate with the RasPi via serial we need to disconnect the terminal console from /tty/AMA0.

## Use custom cmdline.txt

	sudo mv /boot/cmdline.txt /boot/original.cmdline.txt
	sudo cp /home/pi/emonpi/cmdline.txt /boot/

This changes the  a custom cmdline.txt file:

From:

	dwc_otg.lpm_enable=0 console=ttyAMA0,115200 console=tty1 root=/dev/mmcblk0p2 rootfstype=ext4 elevator=deadline fsck.repair=yes rootwait

To:

	dwc_otg.lpm_enable=0 console=tty1 elevator=noop root=/dev/mmcblk0p2 rootfstype=ext4 fsck.repair=yes rootwait

Note changing `elevator=deadline` to `elevator=noop` disk scheduler. Noop that is best recommend for flash disks, this will result in a reduction in disk I/O performance

"Noop: Inserts all the incoming I/O requests to a First In First Out queue and implements request merging. Best used with storage devices that does not depend on mechanical movement to access data (yes, like our flash drives). Advantage here is that flash drives does not require reordering of multiple I/O requests unlike in normal hard drives" - [Full article](http://androidmodguide.blogspot.co.uk/p/io-schedulers.html). [Forum topic discussion](http://openenergymonitor.org/emon/node/11695).

## Disable serial console boot

 	sudo systemctl stop serial-getty@ttyAMA0.service
 	sudo systemctl disable serial-getty@ttyAMA0.service

## Enable serial uploads with avrdude and autoreset

	git clone https://github.com/openenergymonitor/avrdude-rpi.git ~/avrdude-rpi && ~/avrdude-rpi/install

## Raspberry Pi 3 Compatibility

The emonPi communicates with the RasPi via GPIO 14/15 which on the Model B,B+ and Pi2 is mapped to UART0. However on the Pi3 these pins are mapped to UART1 since UART0 is now used for the bluetooth module. However UART1 is software UART and baud rate is dependant to clock speed which can change with the CPU load, undervoltage and temperature; therefore not stable enough. One hack is to force the CPU to a lower speed ( add `core_freq=250` to `/boot/cmdline.txt`) which cripples the Pi3 performance. A better solution for the emonPi is to swap BT and map UART1 back to UART0 (ttyAMA0) so we can talk to the emomPi in the same way as before.  

RasPi 3 by default has bluetooth (BT) mapped to `/dev/AMA0`. To allow use to use high performace hardware serial (dev/ttyAMA0) and move bluetooth to software serial (/dev/ttyS0) we need to add an overlay to `config.txt`. See `/boot/overlays/README` for more details. See [this post for RasPi3 serial explained](https://spellfoundry.com/2016/05/29/configuring-gpio-serial-port-raspbian-jessie-including-pi-3/).

	sudo nano /boot/config.txt

Add to the end of the file

	dtoverlay=pi3-miniuart-bt

We also need to run to stop BT modem trying to use UART

	sudo systemctl disable hciuart

See [RasPi device tree commit](https://github.com/raspberrypi/firmware/commit/845eb064cb52af00f2ea33c0c9c54136f664a3e4) for `pi3-disable-bt` and [forum thread discussion](https://www.raspberrypi.org/forums/viewtopic.php?f=107&t=138223)

Reboot then test serial comms with:

	sudo minicom -D /dev/ttyAMA0 -b38400

You should see data from emonPi ATmega328, sending serial `v` should result in emonPi returning it's firmware version and config settings.

To fix SSHD bug (when using the on board WiFi adapter and NO Ethernet). [Forum thread](https://openenergymonitor.org/emon/node/12566). Edit ` /etc/ssh/sshd_config ` and append:

	IPQoS cs0 cs0

***

# Setup Read-only filesystem

[Follow Raspberry Pi Read-Only guide](https://github.com/emoncms/emoncms/blob/master/docs/RaspberryPi/read-only.md)

# Install emonPi Services

	sudo apt-get install git-core -y
	cd /home/pi
	git clone https://github.com/openenergymonitor/emonpi
	git clone https://github.com/openenergymonitor/RFM2Pi

## emonPi LCD service

Enable I2C module, install packages needed for emonPi LCD service `python-smbus i2c-tools python-rpi.gpio python-pip redis-server` and `pip install uptime redis paho-mqtt`, and install emonPi LCD python scrip service to run at boot

	sudo emonpi/lcd/./install

Restart and test if I2C LCD is detected, it should be on address `0x27`:

	sudo i2cdetect -y 1

## Setup emonPi update

	Add Pi user cron entry:

		crontab -e

	Add the cron entries to check if emonpi update or emonpi backup has been triggered once every 60s:

	```
	MAILTO=""

	# # Run emonPi update script ever min, scrip exits unless update flag exists in /tmp
	* * * * * /home/pi/emonpi/service-runner >> /var/log/service-runner.log 2>&1
	```

	To enable triggering update on first factory boot (when emonpiupdate.log does not exist) add entry to `rc.local`:

		/home/pi/emonpi/./firstbootupdate

	This line should be present already if the emonPi speicifc `rc.local` file has been symlinked into place, if not:

		sudo rm /etc/rc.local
		sudo ln -s /home/pi/emonpi/emonpi/rc.local_jessieminimal /etc/rc.local

	The `update` script looks for a flag in `/tmp/emonpiupdate` which is set when use clicks Update in Emoncms. If flag is present then the update script runs `emonpiupdate`, `emoncmsupdate` and `emonhubupdate` and logs to `~/data/emonpiupdate.log`. If log file is not present then update is ran on first (factory) boot.

## Setup NTP Update

See [forum thread](https://community.openenergymonitor.org/t/emontx-communication-with-rpi/3659/2)

`sudo crontab -e`

Add

```
# Force NTP update every 1 hour

0 * * * * /home/pi/emonpi/ntp_update.sh >> /var/log/ntp_update.log 2>&1
```

## Fix Random seed

Random seed is important for secure ssh and https connections. Using a RO root FS we need to symlink randomised to RW data partition to enable to service to run and be random. See [forum thread](https://community.openenergymonitor.org/t/random-seed/3637).

```
$ rpi-rw
$ cd /var/lib/systemd/
$ sudo mv random-seed ~/data/
$ sudo ln -s ~/data/random-seed
$ rpi-ro
$ sudo systemctl restart systemd-random-seed
$ sudo systemctl status systemd-random-seed
```

Random seed service should now be running.

***

# Install mosquitto MQTT

Install & configure Mosquitto MQTT server, PHP MQTT
```
wget http://repo.mosquitto.org/debian/mosquitto-repo.gpg.key
sudo apt-key add mosquitto-repo.gpg.key
cd /etc/apt/sources.list.d/
sudo wget http://repo.mosquitto.org/debian/mosquitto-jessie.list
sudo apt-get update
sudo apt-get install mosquitto mosquitto-clients libmosquitto-dev -y
sudo pecl install Mosquitto-beta
(Hit enter to autodetect libmosquitto location)
```

To check which version of Mosquitto pecl has installed run `$ pecl list-upgrades`. Currently emonSD (Oct17) is running Mosquitto 0.3. See this [forum post](https://community.openenergymonitor.org/t/raspbian-stretch/5096/60?u=glyn.hudson) and [this one](https://community.openenergymonitor.org/t/upgrading-emonsd-php-mosquito-version/6265/13) discussing the choice of Mosquitto alpa.

```
pecl list-upgrades
Channel pear.php.net: No upgrades available
Channel pear.swiftmailer.org: No upgrades available
pecl.php.net Available Upgrades (stable):
=========================================
Channel      Package   Local          Remote         Size
pecl.php.net dio       0.0.6 (beta)   0.1.0 (beta)   37kB
pecl.php.net Mosquitto 0.3.0 (beta)   0.4.0 (beta)   24kB
pecl.php.net redis     2.2.5 (stable) 3.1.6 (stable) 196kB
```

To upgrade to Mosquitto 0.4 run (currently not fully tested as of Jan 18): *Update: seems to work fine*

`$ sudo pecl install Mosquitto-0.4.0`

Install PHP Mosquitto extension:

    printf "extension=mosquitto.so" | sudo tee /etc/php5/mods-available/mosquitto.ini 1>&2
    sudo php5enmod mosquitto

Turn off Mosquitto persistence and enable authentication:

	sudo nano /etc/mosquitto/mosquitto.conf

Set `persistence false` and add the lines:

	allow_anonymous false
	password_file /etc/mosquitto/passwd

Set logging to errors only

	log_type error

Create a password file for MQTT user `emonpi` with:

	sudo mosquitto_passwd -c /etc/mosquitto/passwd emonpi

Enter password `emonpimqtt2016` (default)

**Test MQTT**

Open *another shell window* to subscribe to a test topic:

	mosquitto_sub -v -u 'emonpi' -P 'emonpimqtt2016' -t 'test/topic'

 In the first shell oublish to the test topic :

	mosquitto_pub -u 'emonpi' -P 'emonpimqtt2016' -t 'test/topic' -m 'helloWorld'

If all is working we should see `helloWorld` in the second shell

***

# emonHub

Install other EmonHub dependencies if they have not been installed already by emonPi LCD service

```
sudo apt-get install -y python-pip python-serial python-configobj”
sudo pip install paho-mqtt pydispatcher
```

## Install emonHub (emon-pi) variant:

	cd ~/
	git clone https://github.com/openenergymonitor/emonhub.git && emonhub/install

Check log file:

	tail /var/log/emonhub/emonhub.log

We can check data is being posted to MQTT by subscribing to the base topic `emon/#` if new node variable MQTT topic structure is used or `emonhub/#` if old MQTT CSV topic structure is used

	mosquitto_sub -v -u 'emonpi' -P 'emonpimqtt2016' -t 'emon/#'

***

# Install Emoncms Core

*V9 Core (stable branch)*

Follow [Emoncms Raspberry Pi Raspbian Jessie install guide](https://github.com/emoncms/emoncms/blob/master/docs/RaspberryPi/readme.md)

## emonPi specific Emoncms settings

* MYSQL root password: `emonpimysql2016`
* MYSQL `emoncms` user password: `emonpiemoncmsmysql2016`
* Use emonPi default settings:
	* `cd /var/www/emoncms && cp default.emonpi.settings.php settings.php`
* Create feed directories in RW partition `/home/pi/data` instead of `/var/lib`:
	* `sudo mkdir /home/pi/data/{phpfina,phptimeseries}`
	* `sudo chown www-data:root /home/pi/data/{phpfina,phptimeseries}`

*Note: at time of writing the version of `php5-redis` included in the Raspbian Jessie sources (2.2.5-1) caused Apache to crash (segmentation errors in Apache error log). Installing the latest stable version (2.2.7) of php5-redis from github fixed the issue. This step probably won't be required in the future when the updated version of php5-redis makes it's way into the sources. The check the version in the sources: `sudo apt-cache show php5-redis`*

```
git clone --branch 2.2.7 https://github.com/phpredis/phpredis
cd phpredis
(check the version we are about to install:)
cat php_redis.h | grep VERSION
phpize
./configure
sudo make
sudo make install
```

## Move MYSQL database location

The MYSQL database for Emoncms is usually in `/var/lib`, since the emonPi runs the root FS as read-only we need to move the MYSQL database to the RW partition `home/pi/data/mysql`. Follow stepsL [Moving MYSQL database in Emoncms Read-only documentation](https://github.com/emoncms/emoncms/blob/master/docs/RaspberryPi/read-only.md#move-mysql-database)

## Low write mode Emoncms optimisations

[Related forum discussion thread](http://openenergymonitor.org/emon/node/11695)

Follow [Raspberry Pi Emoncms Low-Write guide](https://github.com/emoncms/emoncms/blob/master/docs/RaspberryPi/Low-write-mode.md) from [Setting up logging on read-only FS](https://github.com/emoncms/emoncms/blob/master/docs/RaspberryPi/Low-write-mode.md#setup-logfile-environment) onwards (we have earlier setup read-only mode):

* [Setting up logging on read-only FS](https://github.com/emoncms/emoncms/blob/master/docs/RaspberryPi/Low-write-mode.md#setup-logfile-environment)
	* After running install we want to use emonPi specific rc.local instead:
		* `sudo rm /etc/rc.local`
		* `sudo ln -s /home/pi/emonpi/rc.local_jessieminimal /etc/rc.local`

* [Move PHP sessions to tmpfs (RAM)](https://github.com/emoncms/emoncms/blob/master/docs/RaspberryPi/Low-write-mode.md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)
* [Configure Redis](https://github.com/emoncms/emoncms/blob/master/docs/RaspberryPi/Low-write-mode.md#configure-redis)
	* After redis config **Ensure all redis databases have been removed from `/var/lib/redis`**
* Disable apache access log:
	* `sudo nano /etc/apache2/conf-enabled/other-vhosts-access-log.conf`
	* comment out the access log
* Ensure apache error log goes to /var/log/apache2/error.log
 	*  `sudo nano /etc/apache2/envvars`
 	*  Ensure `export APACHE_LOG_DIR=/var/log/apache2/$SUFFIX`

* [Reduce garbage in syslog due to Raspbian bug](https://openenergymonitor.org/emon/node/12566):

	* Edit the `/etc/rsyslog.conf` and comment out the last 4 lines that use xconsole:

```
#daemon.*;mail.*;\

#       news.err;\

#       *.=debug;*.=info;\

#       *.=notice;*.=warn       |/dev/xconsole
```

No need to [Enable Low-write mode in emoncms](https://github.com/emoncms/emoncms/blob/master/docs/RaspberryPi/Low-write-mode.md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) since these changes to `settings.php` are already set in `default.emonpi.settings.php` that we installed earlier.

## Install Emoncms Modules

```
cd /var/www/emoncms/Modules
git clone https://github.com/emoncms/dashboard.git
git clone https://github.com/emoncms/app.git
git clone https://github.com/emoncms/wifi.git
git clone https://github.com/emoncms/config
git clone https://github.com/emoncms/graph

cd /home/pi/
git clone https://github.com/emoncms/backup
git clone https://github.com/emoncms/postprocess
git clone https://github.com/emoncms/usefulscripts
```

- After installing modules check and apply database updates in Emoncms Admin.

### Configure Emoncms WiFi Module

Follow install instructions in [WiFi module Readme](https://github.com/emoncms/wifi/blob/9.0/README.md) to give web user permission to execute system WLAN commands.

Move `wpa_supplicant.conf` (file where WiFi network authentication details are stored) to RW partition with symlink back to /etc:

	sudo mv /etc/wpa_supplicant/wpa_supplicant.conf /home/pi/data/wpa_supplicant.conf
	sudo ln -s /home/pi/data/wpa_supplicant.conf /etc/wpa_supplicant/wpa_supplicant.conf  

#### Install wifi-check script

To check if wifi is connected every 5min and re-initiate connection if not.

Add wifi-check script to `/user/local/bin`:

	sudo ln -s /home/pi/emonpi/wifi-check /usr/local/bin/wifi-check

Make wifi check script run as root crontab every 5min:

	sudo crontab -e

Add the line:

``*/5 * * * * /usr/local/bin/wifi-check > /var/log/wificheck.log 2>&1" mycron ; ``

### Setup Emoncms Backup & import module

Follow [instructions on emonPi backup module page](https://github.com/emoncms/backup) to symlink the Emoncms module from the folder in /home/pi/backup that also contains the backup shell scripts

## Emoncms Language Support

```
sudo apt-get install gettext
sudo dpkg-reconfigure locales
```
Select required languages from the list by pressing [Space], hit [Enter to install], see [language translations supported by Emoncms](https://github.com/emoncms/emoncms/tree/master/Modules/user/locale)

`sudo apache2 restart`

[more info on gettext](https://github.com/emoncms/emoncms/blob/master/docs/gettext.md)

***

# Install Emoncms MQTT input service

To enable data posted to base topic `emon/` topic to appear in Emoncms inputs e.g `emon/emontx/power1 10` creates an input from emonTx node with power1 with value 10.

[Follow install guide]( https://github.com/emoncms/emoncms/blob/master/docs/RaspberryPi/MQTT.md)

	sudo service mqtt_input start

[Forum Thread discussing emonhub MQTT support](http://openenergymonitor.org/emon/node/12091)

*Previously EmonHub posted decoded data to MQTT topic with CSV format to  `emonhub/rx/5/values 10,11,12` which the Nodes module suscribed to and decoded. Using the MQTT input service in conjunction with the new EmonHub MQTT node topic structure depreciates the Nodes module*

# Lightwave RF MQTT service

[Follow LightWave RF MQTT GitHub Repo Install Guide](https://github.com/openenergymonitor/lightwaverf-pi)

***

# Configure Firewall

Apache web server `sudo ufw allow 80/tcp` and`sudo ufw allow 443/tcp`

SSH server: `sudo ufw allow 22/tcp`

Mosquitto MQTT: `sudo ufw allow 1883/tcp`

Redis: `sudo ufw allow 6379/tcp`

OpenHAB: `sudo ufw allow 8080/tcp`

NodeRed: `sudo ufw allow 1880/tcp`

	sudo ufw enable

***

# Install NodeRED

[Follow OEM NodeRED install guide](https://github.com/openenergymonitor/oem_node-red) with OEM examples.

Default flows admin user: `emonpi` and password `emonpi2016`

***

# Install openHAB

[Follow OEM openHAB install guide](https://github.com/openenergymonitor/oem_openHab) with OEM examples

# GSM HiLink Huawei USB modem dongle support

[Follow Huawei Hi-Link RasPi setup guide](https://github.com/openenergymonitor/huawei-hilink-status/blob/master/README.md) to setup HiLink devices and useful status utility. The emonPiLCD now uses the same Huawei API to display GSM / 3G connection status and signal level on the LCD.

# emonPi Setup Wifi AP mode

Wifi Access Point mode is useful when using emonPi without a interent connection of with a 3G dongle.

[Follow guide to install hostpad and DHCP](https://github.com/openenergymonitor/emonpi/blob/master/docs/wifiAP.md)

Including installing start/ stop script to start the AP and also bridge the 3G dongle interface on eth1 to wlan0

***

# Symlink scripts

## emonSDexpand:

`sudo ln -s /home/pi/usefulscripts/sdpart/sdpart_imagefile /sbin/emonSDexpand`

## Fstab:

`sudo ln -s /home/pi/emonpi/fstab /etc/fstab`

***

# Clean Up

## Remove unused packages

`$ sudo apt-get clean all`

## Run Factory reset

```
sudo su
/home/pi/emonpi/.factoryreset
```

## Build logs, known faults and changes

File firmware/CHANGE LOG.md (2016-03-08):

# Change Log - emonPi Firmwarwe

# V3.3 (08/03/16
 * Adjust Vcal_EU to improve VRMS voltage reading accuracy when using UK/EU AC-AC
 * Compile with Arduino 1.6.7 with JeeLib 10th Sep 2015 f097c0039c926881d80a74bec7a7aa020de610ee
 * Updated OneWire library to V2.3.2 & updated sensors.getAddress function

Sketch uses 20,668 bytes (64%) of program storage space. Maximum is 32,256 bytes.
Global variables use 1,070 bytes (52%) of dynamic memory, leaving 978 bytes for local variables. Maximum is 2,048 bytes.

# V3.2 (31/01/16) 
 * Reduction in SRAM memory usage thanks to F-macro serial string implementation

# V3.1 (31/01/16)
 * Display "Rasberry Pi Booting" message at startup & don't sample from CT input channel when no CT is physically connected to that input

# V3.0 December 2015
  * Continuous sampling using emonLibCM https://github.com/openenergymonitor/EmonLibCM

# V2.0 (17/11/15)
  * Don't print ACK's to serial 

# V1.9 (16/11/15)
  * Fix counting pulses faster than 110ms, strobed meter LED http://openenergymonitor.org/emon/node/11490

# V1.8 (30/10/15)
  * Enable pulse count INT1 internal pull-up to fix spurious pulse count readings
 
# V1.7 (12/06/15)
  * Fix bug which stopped USA AC-AC Vcal from being applied at runtime

# V1.6 (12/06/15)
  * Fix interrupt pulse debouce issue by limiting pulse width to 52ms min (50ms is default for LED pulse output meters) 
  * Compile with latest JeeLib with fix for RF hang, remove RF reset added in V1.3 (bf179057ee1abc2cfa2965b454421203ac52c6c3)
  * Enable simultaneous pulse counting and temperature monitoring on single RJ45 using breakout

# V1.5 (27/05/15)
  * Change pulse count to be stored as unsigned long datatype
  * Add new variable power 1 + power 2 as third item in the node struct. This will be useful for US installs and Solar PV type 2 installations to provide a feed for consumption (solar PV + grid import / export)

**Important Note:**
After this update a manual change will be required to emonhub.conf, copy and paste the following to override the node decoder for the emonPi node [[5]] in the Nodes section of emonhub.conf:
```
[[5]]
    nodename = emonPi
    firmware = emonPi_RFM69CW_RF12Demo_DiscreteSampling.ino
    hardware = emonpi
    [[[rx]]]
        names = power1,power2,power1_plus_power2,Vrms,T1,T2,T3,T4,T5,T6,pulseCount
        datacodes = h, h, h, h, h, h, h, h, h, h, L
        scales = 1,1,1,0.01,0.1,0.1,0.1,0.1,0.1,0.1,1
        units = W,W,W,V,C,C,C,C,C,C,p
```
https://github.com/openenergymonitor/emonpi/commit/c427cd2bdfce7b3c535388d1ee53cc45183edf9c

# V1.4 (27/05/15)
Make firmware version return command 'v' return firmware version and RFM setting all on one line
https://github.com/openenergymonitor/emonpi/commit/fa4474571cffa45d03483ce9da32f021dd2df91a

# V1.3 (21/05/15)
1.3 firmware dev, add RF init ever 10min to keep RF alive
https://github.com/openenergymonitor/emonpi/commit/96b59c38c045a44e6dea3c1a5e048d038380e88a

# V1.2 (13/05/15) 
Fix AC wave detect and improve AC calibration calibration 
https://github.com/openenergymonitor/emonpi/commit/41987f1e21b3687b8b0ac6b9f5f5160cdfb808a4

# V1.1 (11/05/15) 
Add sample from both CT's as default and set 110V VRMS for apparent power when US calibration is set e.g '2p'
https://github.com/openenergymonitor/emonpi/commit/2565eb3663847c22bfb62b0d1258f8cbc5fea224

# V1.0 
First release

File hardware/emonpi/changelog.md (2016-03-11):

# Hardware Change Log

## emonPi

### V1.5
    
* First release KickStarter rewards **May-Nov 2015**

### V1.6 

**Nov 15 onwards**

   * Pull back tracks and GND place around mount holes
   * Connect OOK to GPIO 18
   * Move OOK to top of board to avoid Pi2 connector shorting issue
   * Disconnect RJ45 pin 1 and 3 from GND to stop short when Ethernet is inserted
    * Add to silkscreen that the diode Cathode (flat line - negative) points upward) on the PCB and the Anode goes to GND (downward)
    * Add double side silkscreen for LCD I2C & switch header
    * Fix 'designed by' typo on rear silkscreen :-)

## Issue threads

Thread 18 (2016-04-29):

emonPi LCD display correct RasPi3 WiFi signal strength

glynhudson, 2016-04-29:
RasPi3 wifi reports:

```
$ iwconfig
wlan0     IEEE 802.11bgn  ESSID:"Moelwyn"
          Mode:Managed  Frequency:2.447 GHz  Access Point: 00:11:09:0D:1F:CD
          Bit Rate=54 Mb/s   Tx-Power=1496 dBm
          Retry short limit:7   RTS thr:off   Fragment thr:off
          Encryption key:off
          Power Management:on
          Link Quality=41/70  Signal level=-69 dBm
          Rx invalid nwid:0  Rx invalid crypt:0  Rx invalid frag:0
          Tx excessive retries:0  Invalid misc:0   Missed beacon:0
```

Edimax dongle on Pi2 reports

```
$ iwconfig
wlan0     IEEE 802.11bgn  ESSID:"Crumble"  Nickname:"<WIFI@REALTEK>"
          Mode:Managed  Frequency:2.447 GHz  Access Point: 7C:4C:A5:2E:7C:ED
          Bit Rate:72.2 Mb/s   Sensitivity:0/0
          Retry:off   RTS thr:off   Fragment thr:off
          Power Management:off
          Link Quality=100/100  Signal level=90/100  Noise level=0/100
          Rx invalid nwid:0  Rx invalid crypt:0  Rx invalid frag:0
          Tx excessive retries:0  Invalid misc:0   Missed beacon:0
```

Currently with the above o/p the LCD would display -69% for the Wifi strength on the pi3 and 90% from pi2 as the LCD script currently reads the `Signal Level` with

```
        if wlan0ip:
            # wlan link status
            with open('/proc/net/wireless', 'r') as f:
                wireless = f.readlines()
            signals = [x.split()[3] for x in wireless if x.strip().startswith('wlan0')]
            if signals:
                signallevel = signals[0].partition('.')[0]
        r.set("wlan:signallevel", signallevel)
```

We need to detect a negative number and then instead display `signal quality` as a percentage e.g  Link Quality=41/70 = 41/70*100 = 59%

Closed 2016-05-04.

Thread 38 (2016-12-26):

Lastest emonSD image updates on every reboot!

pb66, 2016-12-26:
Latest build and fully updated.

My emonPi updates on every reboot, it seems the "firstbootupdate" script is initializing an update even when it is not required. When I looked into it and tested the separate "or" parts of the if statement in this line

https://github.com/openenergymonitor/emonpi/blob/master/firstbootupdate#L13

I found the log file is non-zero size as expected since it is not the first boot, but the $button value is 0 at rest and 1 when pressed, so the button action actually works as a "update bypass" if held while rebooting not a "forced update".

By editing this line to

    if [ ! -s /home/pi/data/emonpiupdate.log ] || [ $button == 1 ]; then

it works as expected.

I can see there was a [recent change](https://github.com/openenergymonitor/emonpi/commit/44f5aa70f050cdb41e36110ab4e361653e9284af) to this code that inverted the action based on the $button value, was this intended? has the switch been physically changed in production?

glynhudson, 2016-12-27:
Good spot, I got the GPIO state inverted. It's been fixed now. Thanks 👍

pb66, 2016-12-28:
Cool! thanks.
I submitted PR to change the comment to suit #39 too

glynhudson, 2016-12-29:
Great, thanks!

- sent from my mobile device

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

Closed 2016-12-27.

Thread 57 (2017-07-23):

Postprocess Module Included in SD Image?

davidski, 2017-07-23:
Is the postprocess module intended to be included in the stock SD image? It's not currently in the listed default modules, though I have it on my Nov 2016 image, possibly as a result of having run the emoncms update script, which appears to install that module.

Seeking clarification before I add this to the default module list in my Chef-version of the build process. :smile:

JonMurphy, 2017-07-24:
this should help!
https://community.openenergymonitor.org/t/post-process-disappeared/4583?u=jon

davidski, 2017-07-24:
Thanks, @JonMurphy! Looking through that thread and the `emoncms/postprocess` repo, it looks like the postprocess module has existed as a stand alone module for a while and should be included in the emonSD setup process. If you or another contributor could confirm that that's correct, I'll get an issue opened on the emonSD repo.

TrystanLea, 2017-07-24:
Yes I can confirm postprocess module is included and I plan to announce and write a guide for it soon :)

Closed 2017-07-24.

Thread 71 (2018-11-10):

Overflow of "now" variable after 50 days?

SeanDS, 2018-11-10:
In [src.ino](https://github.com/openenergymonitor/emonpi/blob/24dee5dd0ed66a6f366b11d1dd90a0bde74fb6fc/firmware/src/src.ino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), the variable `now` is set to the result of `millis()`. The [Arduino documentation for this function](https://www.arduino.cc/reference/en/language/functions/time/millis/) states:

    This number will overflow (go back to zero), after approximately 50 days.

I think this has an effect on the RF reset timeout and sample checks:
```arduino
if ((now - last_rf_rest) > RF_RESET_PERIOD)
```
```arduino
if ((now - last_sample) > TIME_BETWEEN_READINGS)
```

I think that after `now` overflows, the checks above will always result in false until `now` again reaches the time of the last `last_rf_rest` and `last_sample` times before the overflow, i.e. around once every 50 days. That means that from power-on, the board will reset the RF module and make samples every `RF_RESET_PERIOD` and `TIME_BETWEEN_READINGS` milliseconds, until ~50 days have past, then only make samples and reset the RF module *every 50 days*.

Maybe I've misunderstood how this works in the C/AVR/Arduino world, but I thought I'd point it out in case this is a bug.

A potential fix could simply be to put this before the two checks above:

```arduino
  // Check if now has overflowed.
  if (now < last_sample || now < last_rf_rest) {
    // Assume now has overflowed, so reset variables that are checked against now.
    last_rf_rest = 0;
    last_sample = 0;
  }
```

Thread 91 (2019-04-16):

User pi

borpin, 2019-04-16:
https://github.com/openenergymonitor/emonpi/blob/0c477c895f3eb198bf821c79cd068f396631cf12/install/init.sh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

Could the current user be used instead of `pi` or else pass in a parameter for the user?

Thinking is making it non-rpi specific

TrystanLea, 2019-04-25:
Fixed here, thanks: https://github.com/openenergymonitor/emonpi/commit/f3a63c9b3012c42c98abdcc96fdbdcd1a8d5f589

Closed 2019-04-25.

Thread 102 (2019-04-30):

On update only pull current branch

borpin, 2019-04-30:
https://github.com/openenergymonitor/emonpi/blob/1a87023a3000b611c2d99a87505e88d84e8d79eb/update/emoncms.sh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

Looking for somewhere to put the git command to allow a git describe to respond with the expected output, and I realised that only the current branch is pulled on update.

Why not just a `git pull` as that 'fetches' (everything) and 'merges' the current branch.

Either way, can `git fetch --all --prune` be inserted before this conditional as it simply updates git with the commit history rather than changing anything.

borpin, 2019-09-02:
closed via #114

Closed 2019-09-02.

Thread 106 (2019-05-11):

Possible Cleanup of old Node Red Files

Paulf007, 2019-05-11:
As node-red was removed from the image , consider removing the old .node-red modules.
If you install node red-on the emon pi with the installation script node red crashed on startup as there are still old nodes that has not been loaded in the flows.
See below -

Flows stopped due to missing node types.
emoncms-server
wunderground

Steve720, 2019-05-11:
Seen here too.  Had to remove /home/pi/.node-red before installing node-red on a fresh install of emonSD-30Oct18.zip.

borpin, 2019-05-12:
There is work currently in place to replace the creation of an Image file, to an install script that will run on Raspbian Light.  This will solve this problem.  The Image file won't be updated I suspect, just withdrawn.

glynhudson, 2019-05-12:
Sure, the `~/.node-red` folder will be removed from the next image created using the new build scripts. Apologies for the hassle.

Closed 2019-05-12.

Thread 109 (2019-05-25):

Conflicting safe update lists causing problems when update called from emoncms

pb66, 2019-05-25:
See https://community.openenergymonitor.org/t/permanent-raspberry-pi-booting-after-failed-emonpi-update/10963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

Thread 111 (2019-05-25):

Old updater runs but all paths are invalid as changed for new updater scripts

pb66, 2019-05-25:
see https://community.openenergymonitor.org/t/permanent-raspberry-pi-booting-after-failed-emonpi-update/10963/5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

Closed 2019-05-29.

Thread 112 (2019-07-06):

Archive missing v2.83

JensMunkHansen, 2019-07-06:
Hi Developers

I made a typo in the emonhub.conf from the GUI. It puzzled me a lot since using ssh I was looking at a different file. I followed a thread which suggested me to update firmware....

I would very much like to get back to my starting point v2.83 bit it is missing in your archive. Is it possible for you to add it.

Thanks in advance
Jens

glynhudson, 2019-11-17:
Hi, I would recommend updating to the lastest emonPi FW

Closed 2019-11-17.

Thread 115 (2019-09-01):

"keep alive" too aggressive?

pb66, 2019-09-01:
https://github.com/openenergymonitor/emonpi/blob/2.9.1/firmware/src/src.ino#L269-L271

```
if ((now - last_rf_rest) > RF_RESET_PERIOD) {
      rf12_initialize(nodeID, RF_freq, networkGroup);                             // Periodically reset RFM69CW to keep it alive :-(
    }
```

This code appears to run every iteration of the main loop after the first 60s because `last_rf_rest` is declared as 0 during set up and never gets updated.

glynhudson, 2019-09-01:
Good spot. Have you heard if this is this causing any known issues?

Maybe it's not worth changing since it's proven stable in its current form. The RF on my early test emonPi has not had a single dropout in over 4yrs of operation.

pb66, 2019-11-17:
TBH I wasn't aware of any actual reported cases but there is now that someone has tried recompiling the emonpi FW with some changes. See https://community.openenergymonitor.org/t/emonpi-firmware-build/12428/37?u=pb66

adtyne, 2019-11-17:
This issue gave me serious problems building a working customised firmware in recent days, adding a single line to update `last_rf_rest` fixed my issues immediately. I'm not sure why this hasn't cause a problem in your build environment, but hit problems using PlatformIO on my Pi, PlatformIO on my desktop machine and using the Arduino IDE and resolving the dependencies manually.

Whilst this might not be causing problems in the official build, and may only cause problems for people wanting to do extend the functionality to suit their own purposes.  I don't see that applying this fix would be a determent to the wider user base, and it might just prevent a problem down the line.

glynhudson, 2019-11-17:
Fixed by https://github.com/openenergymonitor/emonpi/commit/e3ca73b876ebac2c324eeba84f8d517dc34e543d

Please let me know if V2.9.2 release works for you: https://github.com/openenergymonitor/emonpi/releases/tag/2.9.2

adtyne, 2019-11-20:
Hello Glyn

I’ve been running that firmware on my system since you published the release without any problems.

Many Thanks

Alistair Tyne

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

glynhudson, 2019-11-20:
Thanks, the change has been incorporated into a stable firmware release. Our internal testing has also not highlighted any issues. Thanks for your help.

Closed 2019-11-17.

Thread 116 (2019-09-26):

Setting upstream branch tracking info

TrystanLea, 2019-09-26:
In attempting to automate the switching of the postprocess, device and sync modules to newly created stable branches I came across an issue caused by for some reason certain repositories not having upstream branch tracking info set. This meant I could not pull in all branches and switch to the newly created stable branches.

The solution I found to work was the following:
 https://github.com/openenergymonitor/emonpi/compare/923e05deeb9ea5945b5493c665f21a20f6be182c..master

I needed to run:

    git branch --set-upstream-to=origin/$branch

and then:

    git pull

without the branch specific pull, it was then possible to run:

    git checkout stable

@borpin what do you think of this solution? Its a shame to pollute every emonpiupdate log with:

    Branch stable set up to track remote branch stable from origin.

but it does seem to work well.

TrystanLea, 2019-09-26:
PS: @borpin im sure you will be happy with the new stable branches. Im thinking of adding a feature to select stable, master or auto from the emoncms UI to make switching between stable/master on a global level easier.

borpin, 2019-09-27:
On changing from UI - great! I was thinking of an advanced update page that would allow a per repo brach selection option.

Not come across this problem with git. Can't try till Sunday. Can you tell me what you tried that failed?

Did you try a `git fetch --all` (from memory)?

Might be how the initial clone was done in the past. Is it a problem on a fresh scripted install?

TrystanLea, 2019-09-27:
Thanks @borpin yes I tried git fetch -all, not quite sure why that didnt work. Im also away until Sunday now. Will reply with more detail then.

borpin, 2019-09-30:
So I have just had a go on an emonpi setup, created by the script (I think) a while back.

I've included a screenshot as the colour helps explain things.

TL:DR
It **should** work by simply using `git fetch` (not `git pull`) first which gets all of the repo info and then a `git checkout <branch>`.

The oddity is that it talks about a 'new' branch, but I don't think it really means that, rather that it has created a new local branch that is tracking a remote branch (if you see what I mean).

```
pi@emonpi:/var/www/emoncms $ cd Modules/device/
pi@emonpi:/var/www/emoncms/Modules/device $ git branch -a
* master
  remotes/origin/HEAD -> origin/master
  remotes/origin/emoncmsorg
  remotes/origin/indexedinputs
  remotes/origin/master
  remotes/origin/remove_user_dependency
pi@emonpi:/var/www/emoncms/Modules/device $ git fetch
From https://github.com/emoncms/device
 * [new branch]      stable     -> origin/stable
pi@emonpi:/var/www/emoncms/Modules/device $ git branch -a
* master
  remotes/origin/HEAD -> origin/master
  remotes/origin/emoncmsorg
  remotes/origin/indexedinputs
  remotes/origin/master
  remotes/origin/remove_user_dependency
  remotes/origin/stable
pi@emonpi:/var/www/emoncms/Modules/device $ git checkout stable
Branch stable set up to track remote branch stable from origin.
Switched to a new branch 'stable'
pi@emonpi:/var/www/emoncms/Modules/device $ git branch -a
  master
* stable
  remotes/origin/HEAD -> origin/master
  remotes/origin/emoncmsorg
  remotes/origin/indexedinputs
  remotes/origin/master
  remotes/origin/remove_user_dependency
  remotes/origin/stable
pi@emonpi:/var/www/emoncms/Modules/device $
```
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

Finally this looks correct.
```
pi@emonpi:/var/www/emoncms/Modules/device $ git remote show origin
* remote origin
  Fetch URL: https://github.com/emoncms/device
  Push  URL: https://github.com/emoncms/device
  HEAD branch: master
  Remote branches:
    emoncmsorg             tracked
    indexedinputs          tracked
    master                 tracked
    remove_user_dependency tracked
    stable                 tracked
  Local branches configured for 'git pull':
    master merges with remote master
    stable merges with remote stable
  Local refs configured for 'git push':
    master pushes to master (up to date)
    stable pushes to stable (up to date)
```

I will do the same for the postprocess folder...
```
pi@emonpi:/var/www/emoncms/Modules $ cd postprocess
pi@emonpi:/var/www/emoncms/Modules/postprocess $ git remote show origin
* remote origin
  Fetch URL: https://github.com/emoncms/postprocess
  Push  URL: https://github.com/emoncms/postprocess
  HEAD branch: master
  Remote branches:
    emoncmsorg tracked
    emonpi     tracked
    master     new (next fetch will store in remotes/origin)
    stable     new (next fetch will store in remotes/origin)
  Local branch configured for 'git pull':
    emonpi merges with remote emonpi
  Local ref configured for 'git push':
    emonpi pushes to emonpi (up to date)
pi@emonpi:/var/www/emoncms/Modules/postprocess $ git branch -a
* emonpi
  remotes/origin/HEAD -> origin/emonpi
  remotes/origin/emoncmsorg
  remotes/origin/emonpi
pi@emonpi:/var/www/emoncms/Modules/postprocess $ git fetch
remote: Enumerating objects: 18, done.
remote: Counting objects: 100% (18/18), done.
remote: Compressing objects: 100% (13/13), done.
remote: Total 18 (delta 7), reused 13 (delta 5), pack-reused 0
Unpacking objects: 100% (18/18), done.
From https://github.com/emoncms/postprocess
 * [new branch]      master     -> origin/master
 * [new branch]      stable     -> origin/stable
pi@emonpi:/var/www/emoncms/Modules/postprocess $ git branch -a
* emonpi
  remotes/origin/HEAD -> origin/emonpi
  remotes/origin/emoncmsorg
  remotes/origin/emonpi
  remotes/origin/master
  remotes/origin/stable
pi@emonpi:/var/www/emoncms/Modules/postprocess $ git remote show origin
* remote origin
  Fetch URL: https://github.com/emoncms/postprocess
  Push  URL: https://github.com/emoncms/postprocess
  HEAD branch: master
  Remote branches:
    emoncmsorg tracked
    emonpi     tracked
    master     tracked
    stable     tracked
  Local branch configured for 'git pull':
    emonpi merges with remote emonpi
  Local ref configured for 'git push':
    emonpi pushes to emonpi (up to date)
pi@emonpi:/var/www/emoncms/Modules/postprocess $ git checkout stable
Branch stable set up to track remote branch stable from origin.
Switched to a new branch 'stable'
pi@emonpi:/var/www/emoncms/Modules/postprocess $ git remote show origin
* remote origin
  Fetch URL: https://github.com/emoncms/postprocess
  Push  URL: https://github.com/emoncms/postprocess
  HEAD branch: master
  Remote branches:
    emoncmsorg tracked
    emonpi     tracked
    master     tracked
    stable     tracked
  Local branches configured for 'git pull':
    emonpi merges with remote emonpi
    stable merges with remote stable
  Local refs configured for 'git push':
    emonpi pushes to emonpi (up to date)
    stable pushes to stable (up to date)
pi@emonpi:/var/www/emoncms/Modules/postprocess $ git branch -a
  emonpi
* stable
  remotes/origin/HEAD -> origin/emonpi
  remotes/origin/emoncmsorg
  remotes/origin/emonpi
  remotes/origin/master
  remotes/origin/stable
pi@emonpi:/var/www/emoncms/Modules/postprocess $
```

borpin, 2019-09-30:
As an aside, could you update all of the `master` branches so the version number is +1 & 'beta' please @TrystanLea?

TrystanLea, 2019-10-01:
updated version: https://github.com/emoncms/emoncms/commit/b925f6e067c748a46a1f890e237b7bda52e2589e

TrystanLea, 2019-10-01:
I previously updated the versions for the other modules e.g: https://github.com/emoncms/sync/commit/39361e49afb6b0cc293ad4b021895f02dc758be5 just somehow forgot the main repo

TrystanLea, 2019-10-01:
If I run git fetch and then git checkout it gives me this message, so looks like git pull is required.

    ------------------------------------------
    Updating /var/www/emoncms/Modules/wifi module
    ------------------------------------------
    Fetching origin
    - git branch: master
    - git tags: 2.0.0-28-g16c75d2
    - no local changes

    Already on 'master'
    Your branch is behind 'origin/master' by 1 commit, and can be fast-forwarded.
      (use "git pull" to update your local branch)

borpin, 2019-10-01:
> I previously updated the versions for the other modules

It was other modules I found - Emoncms/device has the same version for master & stable.

I see you updated WiFi a few minutes ago but left off the 'beta' :grinning:.

borpin, 2019-10-01:
> If I run git fetch and then git checkout it gives me this message, so looks like git pull is required.

Use the `prune` command to help clean it up.

Yes, I think it will. I couldn't test that as stable and master were the same!

borpin, 2019-10-01:
I think it is partly because the original clone targets a specific branch.

TrystanLea, 2019-10-01:
> I see you updated WiFi a few minutes ago but left off the 'beta' grinning.

Yes I don’t want to add the beta to all modules, I think we just keep to updating the version on the module master branches after making a change and then merge to stable when ready.

TrystanLea, 2019-10-01:
> Use the prune command to help clean it up.

prune command is already in there:

    git fetch --prune --all

borpin, 2019-10-01:
> Yes I don’t want to add the beta to all modules

Ok but it then will get really confusing when looking at current state of Modules.  At least a 'b' would immediately identify that the Module was pulled from master as opposed to stable.

TrystanLea, 2019-10-01:
I was thinking that we need to attach the branch to the version in the module list. That would be a good thing to add alongside the ability to change between stable/master on a global level via the UI.

borpin, 2019-10-01:
Can do. Could also make it clearer what are 'core' and what are 'addons'.

One per line, perhaps hold a 'manifest' type file that lists all modules available and then the version number if installed in the UI.

Perhaps:

Module name (with URL) | Version | Branch | Git Describe
--|--|--|--
Emoncms | Version: low-write 10.1.7 | master | 10.1.6-125-g6274f797
backup | v2.0.0 | stable | xxxxxxx

TBH I would not list the core modules, just the add-ons.

TrystanLea, 2019-10-02:
yes I think that would be really nice and I agree better without core modules, just the add-ons

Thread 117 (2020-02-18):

factoryreset script out of date

WeeBull, 2020-02-18:
`/opt/openenergymonitor/emonpi/factoryreset` is out of date with respect to the rest of the OS. It tries to access `/home/pi/emonpi` and `/home/pi/data` which don't exist, and then leaves the system in a broken state. In my case, Wi-Fi searching no longer worked in the web setup.

Suggest either fixing or removal.

glynhudson, 2020-08-04:
This has been fixed, the new factory reset script is located in `/opt/openenergymonitor/EmonScripts/other/factoryreset`. The only factory reset in this emonpi repo will remain for use on older images.

https://github.com/openenergymonitor/EmonScripts/blob/master/other/factoryreset

Closed 2020-08-04.

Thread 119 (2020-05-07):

USB ports changing randomly when using 2x usb devices?

auc0le, 2020-05-07:
Hello,

I am using the store built emon pi device with a VE direct cable to a 712 battery monitor.  That was working fine.

Then I plugged in a norteck Zwave/Zigbee stick for use with OPEN HAB.   Now it seems like the USB ports rotate every day or so and emonpi loses the VE Direct feed.

Here is a screen shot showing the missing data from the last week:
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

Whenever this happens, I have to edit the emonhub config to point to the correct usb port. /dev/ttyUSB2 was the winner today but /dev/ttyUSB0 was the winner yesterday.

Why don't the devices stay the same?  I mean they aren't being unplugged because the emonpi is in an access controlled area.

auc0le, 2020-05-11:
So I unplugged the Z-wave/Zigbee stick and the USB port changed again whenever I rebooted the emonpi - even though the VE Direct cable was never un-plugged.  So it seems as if the USB port assignment isn't constant and likely to change whenever the USB re-inits.

Closed 2020-08-04.

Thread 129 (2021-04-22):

Can't connect my network

ntthang-dev, 2021-04-22:
Hello, my emonPi device currently has an error that cannot connect to the network as follows.

## The first is about the configuration information I'm using:

- The OS I use for emonPi is version: emonSD-24Jul20 (Stable)
- The types of wifi I connect to include 2.4GHz and 5.0GHz
- My current router is very normal and I have no device blocking

## My current problem is as follows:

I have reinstalled the operating system with the latest version as described above. I have seen the installation instructions of emonPi on its [website](https://guide.openenergymonitor.org/setup/connect/) and I follow the steps as above.

After booting, the LCD screen of emonPi shows the IP address 192.168.42.1 and I connected to the wifi network of emonPi and connected to my Wifi network. After doing the above, the device reboots on the LCD screen and after reboot it shows "Ethernet not connected" on the LCD screen. I tried other times the same with wired LAN, 2.4GHz - 5.0GHz wireless network and even after every try I reinstalled emonPi's operating system. However, the same results are all not connected to the network. I use emonCMS, Fing to scan and find emonPi IP in my network, I can't see it, and I also use PuTTy to connect SSH with emonPi but it doesn't work.

I tried connecting my monitor to emonPi via the HDMI port of rasberry3 and I entered the command `ifconfig` and i`wconfig` both showed no connection to the network.

During the device reboot after connecting me to wifi for it through 192.168.42.1, I pinged the device, the result showed that the device can only ping in a very short time after that's impossible to ping completely, the failure rate is 98%.

Don't know what this error is and how to fix it. Thanks.

Closed 2021-04-25.

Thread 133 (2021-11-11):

I have a emonPi that was logging power production from my PV, utilization of electricity etc happily for years now and it suddenly stopped logging data.

fritserasmus, 2021-11-11:
I purchased and installed an emonPi to read power consumption, PV production, etc.

It was working just fine for many years to suddenly stop logging one day without any warning.

I would like to re-install the latest emonPI monitor software and restore current data and configuration files to carry over all the reports and config that are in the current environment.

In the admin I can see there is still an attempt to read and scroll back in the reports I can see all data prior to the Feed stop .

Is there anybody out there that did the same thing before that is willing to give me some pointers. The backup-restore function appears to overwrite everything and I am not sure that is the correct thing to do.

Thanking in advance.

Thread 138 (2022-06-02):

Calibration out of date?

snerd9334, 2022-06-02:
https://github.com/openenergymonitor/emonpi/blob/9f87e5380ac4042e300f6f80d115695fc491b00f/firmware/src/src.ino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

The model referenced here (77DE-06-09) is now no longer manufactured. It has been replaced with 77-DB-06-09.

Spec sheet for old model: https://www.farnell.com/datasheets/1596487.pdf
Spec sheet for new model: https://www.farnell.com/datasheets/1772940.pdf

There are differences between the specifications of the two transformers, so I wonder if the calibration figure on the line referenced at the top of this post needs updating?

Thank you

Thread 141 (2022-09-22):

emonpi fails to start if the username is not pi

MattWoodhead, 2022-09-22:
I installed the emonpi pre-built SD using the Raspberry Pi imager tool. I used the advanced option in the imager tool to change the username from the default 'pi' (for security reasons). Several of the emonpi services fail to start as there are paths that have been hardcoded including the pi username in some scripts.

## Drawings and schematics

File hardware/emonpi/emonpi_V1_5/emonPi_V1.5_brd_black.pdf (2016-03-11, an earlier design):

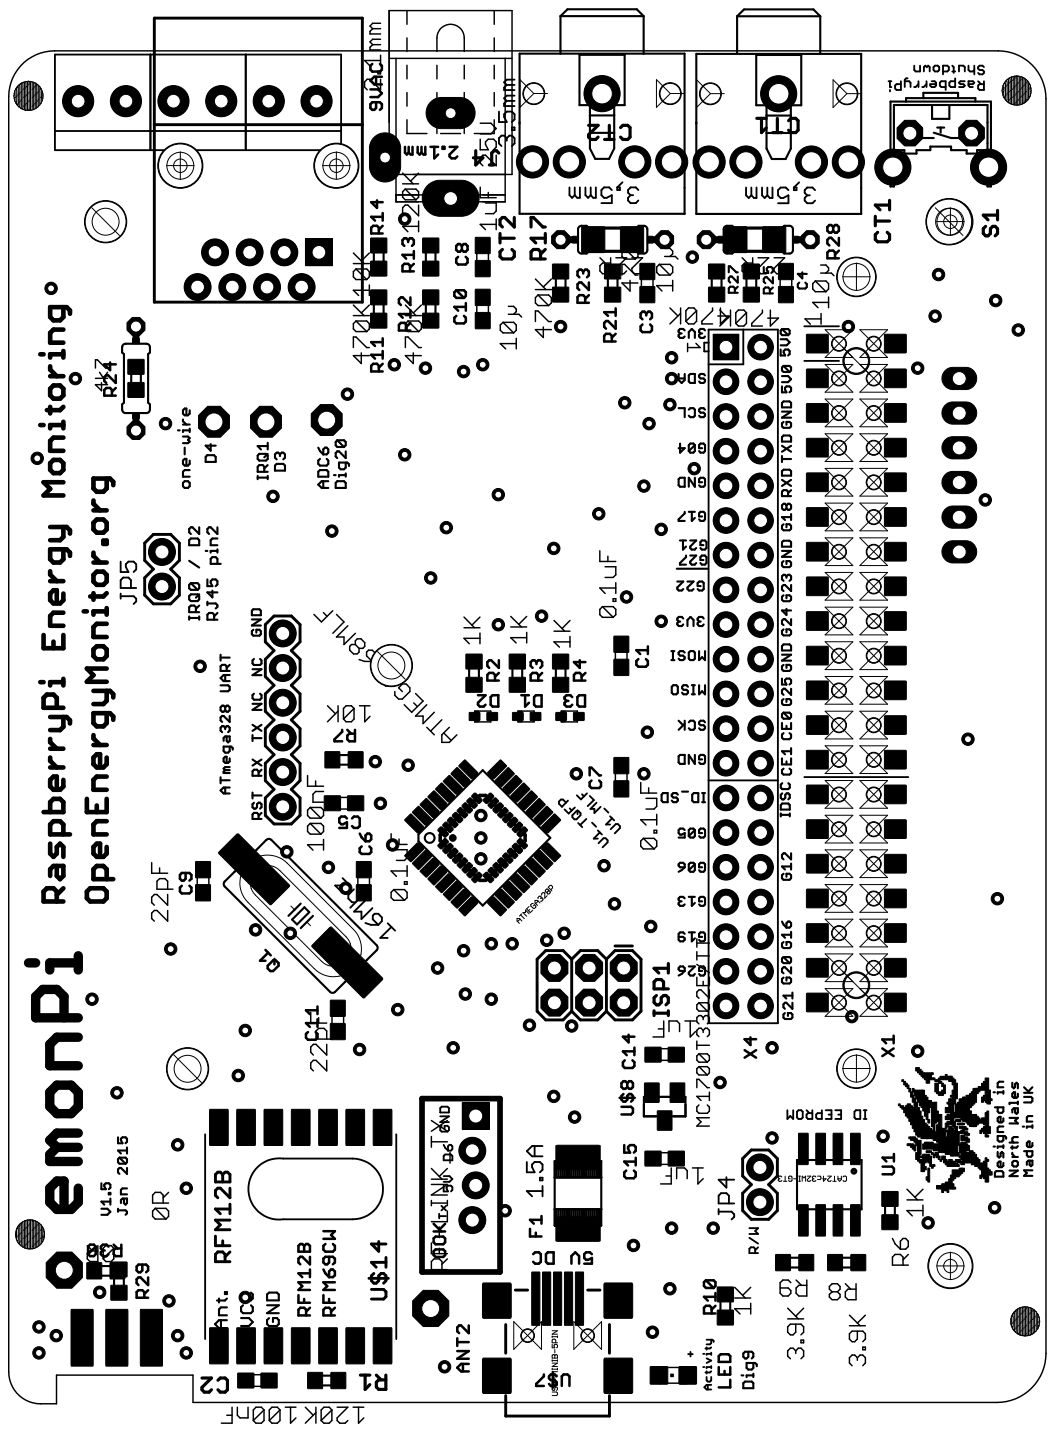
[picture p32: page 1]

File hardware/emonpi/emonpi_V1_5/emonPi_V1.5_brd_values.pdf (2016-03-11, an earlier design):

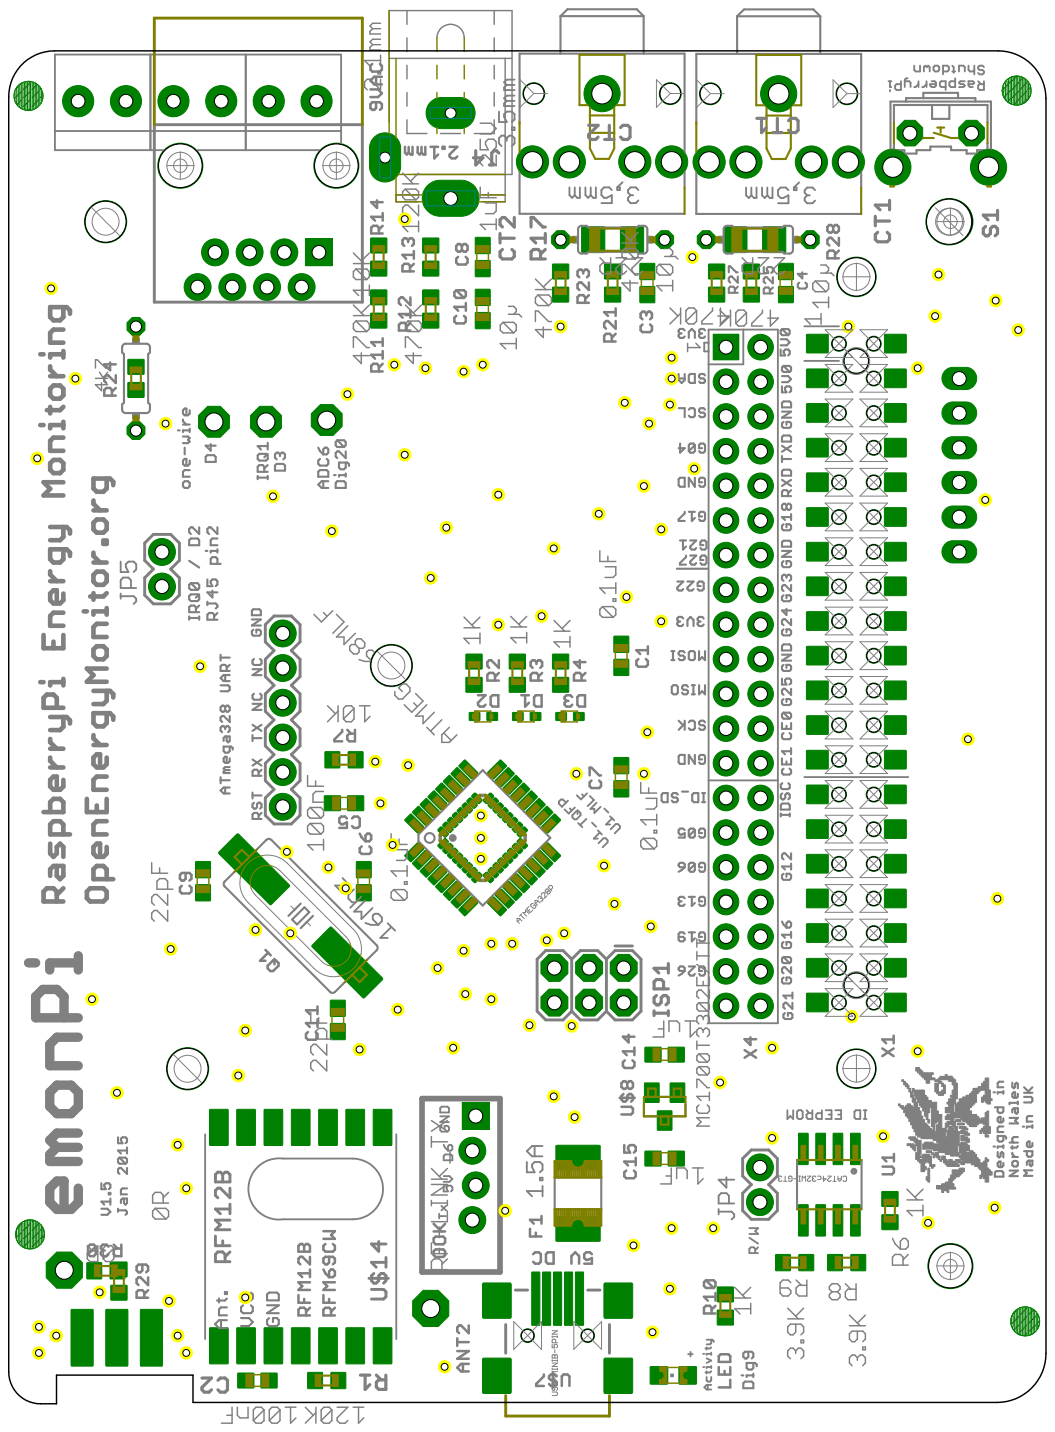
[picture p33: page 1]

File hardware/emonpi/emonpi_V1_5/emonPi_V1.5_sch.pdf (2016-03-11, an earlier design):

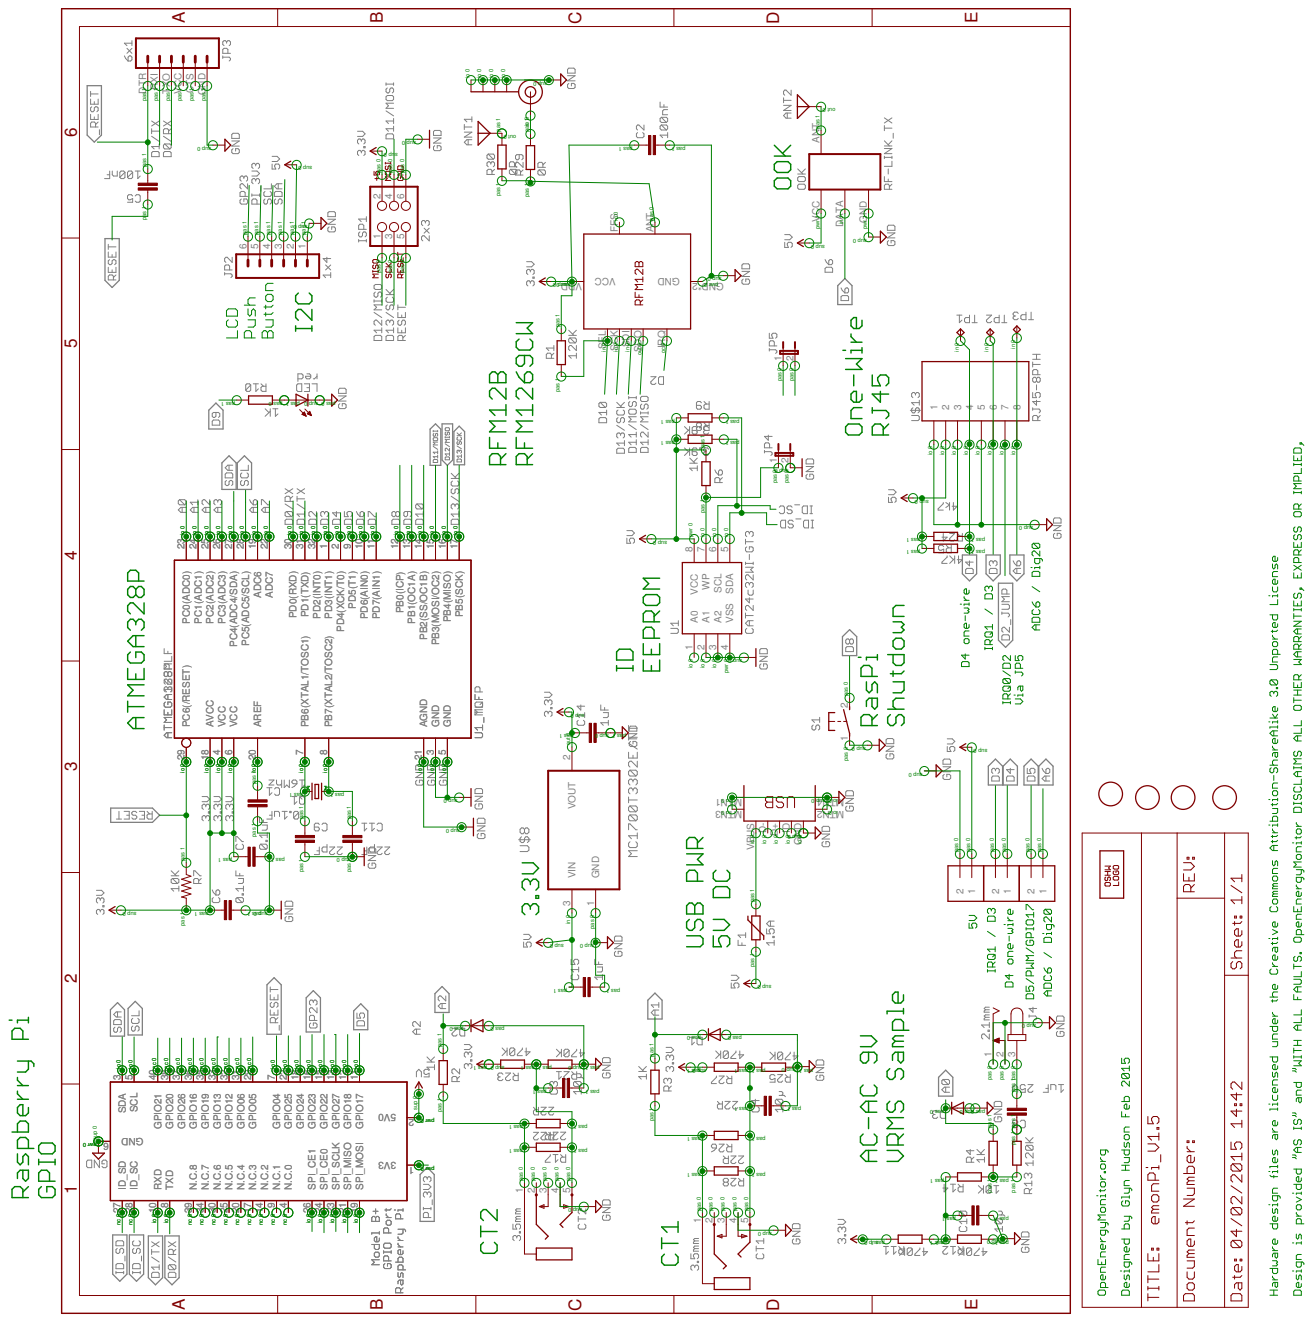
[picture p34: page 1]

ANT CCV DDV DNG

PB4(MISO) 16 PB3(MOSI/OC2) 15 PB2(SS/OC1B) 14 PB1(OC1A) 13 PB0(ICP) 12 PD7(AIN1) 11 PD6(AIN0) 10 PD5(T1) 9 PD4(XCK/T0) 2 PD3(INT1) 1 PD2(INT0) 32 PD1(TXD) 31 PD0(RXD) 30 ADC7

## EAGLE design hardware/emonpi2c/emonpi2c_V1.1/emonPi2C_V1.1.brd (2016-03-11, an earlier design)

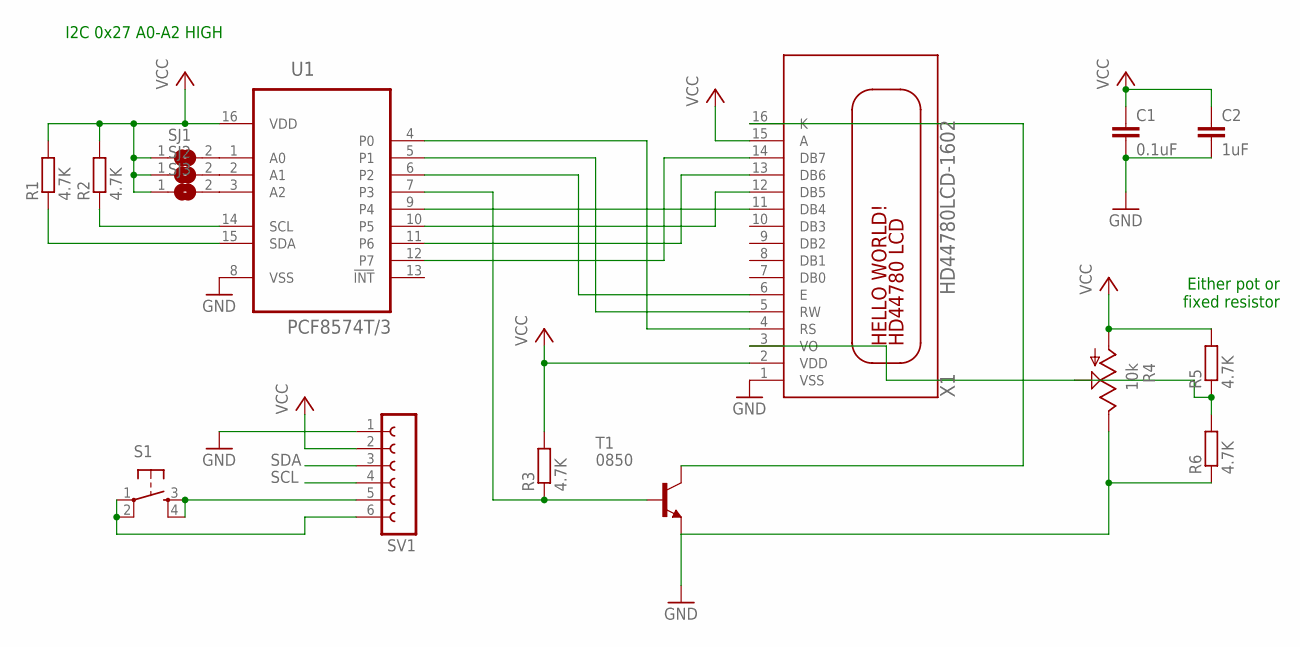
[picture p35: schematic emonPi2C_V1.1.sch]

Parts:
C1: 0.1uF; C0603
C2: 1uF; C0603
R1, R2, R3, R5, R6: 4.7K; R0603
R4: 10k; B25P
S1: TAC_SWITCHPTH; TACTILE-PTH
SJ1, SJ2, SJ3: SJ
SV1: FE06-1; FE06
T1: 0850; SOT23
U1: PCF8574T/3; SOIC127P1032X265-16N
X1: HD44780LCD-1602; LCD1602

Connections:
5V: C1.1, C2.1, R1.2, R2.2, R3.2, R4.A, R5.2, SJ1.1, SJ2.1, SJ3.1, SV1.2, U1.16 (VDD), X1.2 (VDD), X1.15 (A)
CS: U1.6 (P2), X1.6 (E)
DB4: U1.9 (P4), X1.11 (DB4)
DB5: U1.10 (P5), X1.12 (DB5)
DB6: U1.11 (P6), X1.13 (DB6)
DB7: U1.12 (P7), X1.14 (DB7)
GND: C1.2, C2.2, R4.E, R6.1, SV1.1, T1.2 (E), U1.8 (VSS), X1.1 (VSS)
K: T1.3 (C), X1.16 (K)
unnamed: SJ3.2, U1.3 (A2)
unnamed: SJ2.2, U1.2 (A1)
unnamed: S1.3, S1.4, SV1.5
unnamed: S1.1, S1.2, SV1.6
unnamed: SJ1.2, U1.1 (A0)
unnamed: R4.S, R5.1, R6.2, X1.3 (VO)
P3: R3.1, T1.1 (B), U1.7 (P3)
RS: U1.4 (P0), X1.4 (RS)
RW: U1.5 (P1), X1.5 (RW)
SCL: R2.1, SV1.4, U1.14 (SCL)
SDA: R1.1, SV1.3, U1.15 (SDA)

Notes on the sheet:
Either pot or fixed resistor
I2C 0x27 A0-A2 HIGH

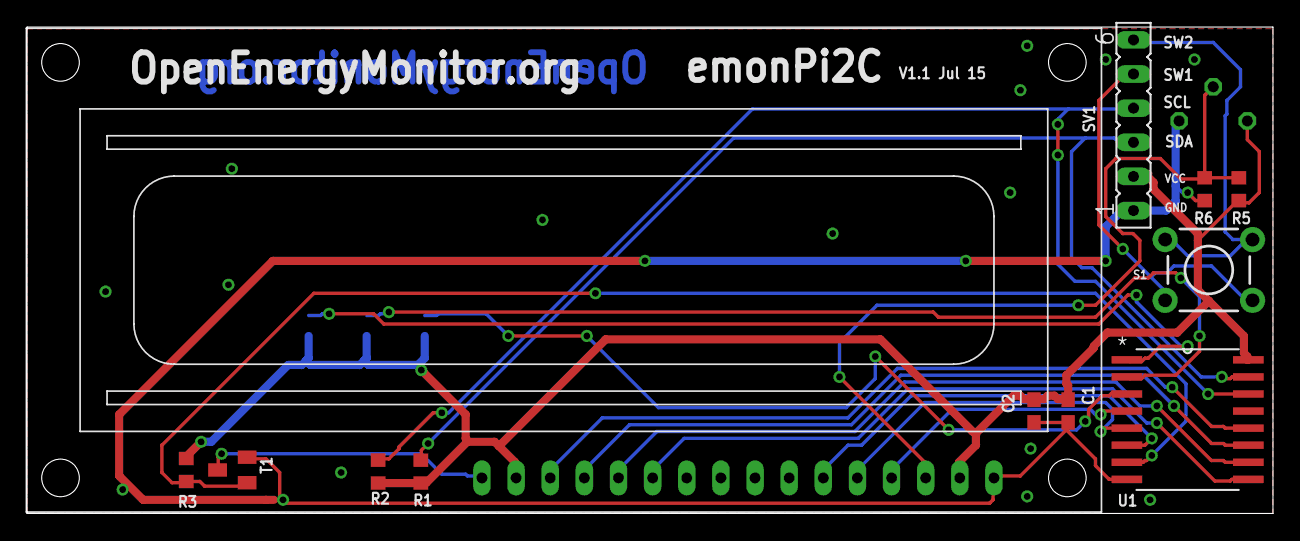
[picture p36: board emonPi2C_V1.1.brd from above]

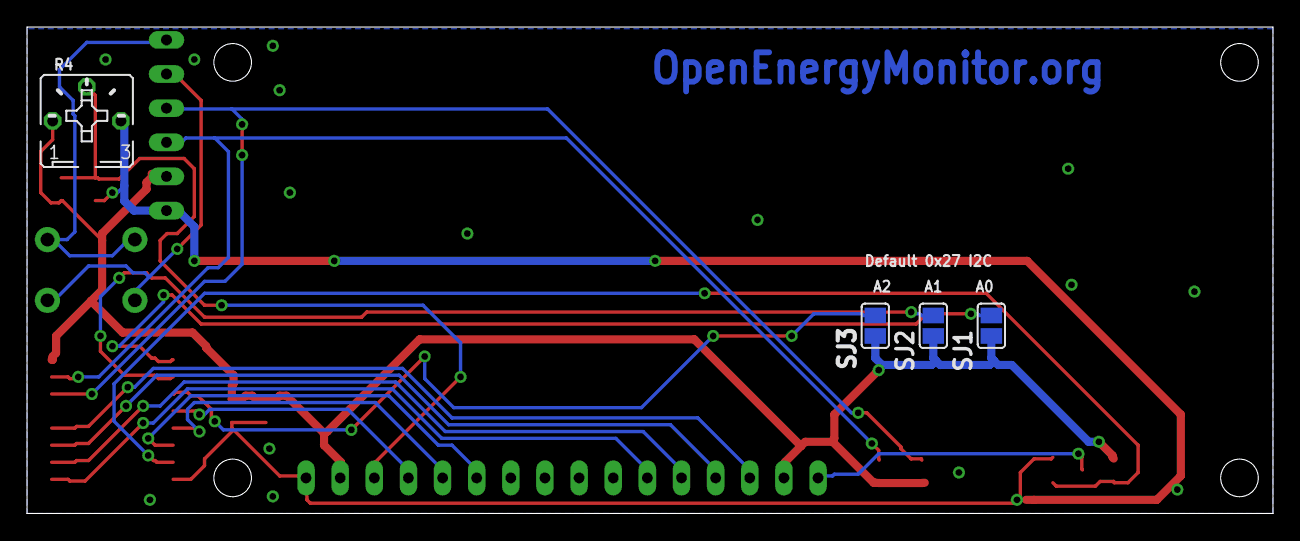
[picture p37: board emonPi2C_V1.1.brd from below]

Board: 2 copper layers, 92.7 x 36.2 mm, 16 parts (4 on the bottom side), 19 nets.

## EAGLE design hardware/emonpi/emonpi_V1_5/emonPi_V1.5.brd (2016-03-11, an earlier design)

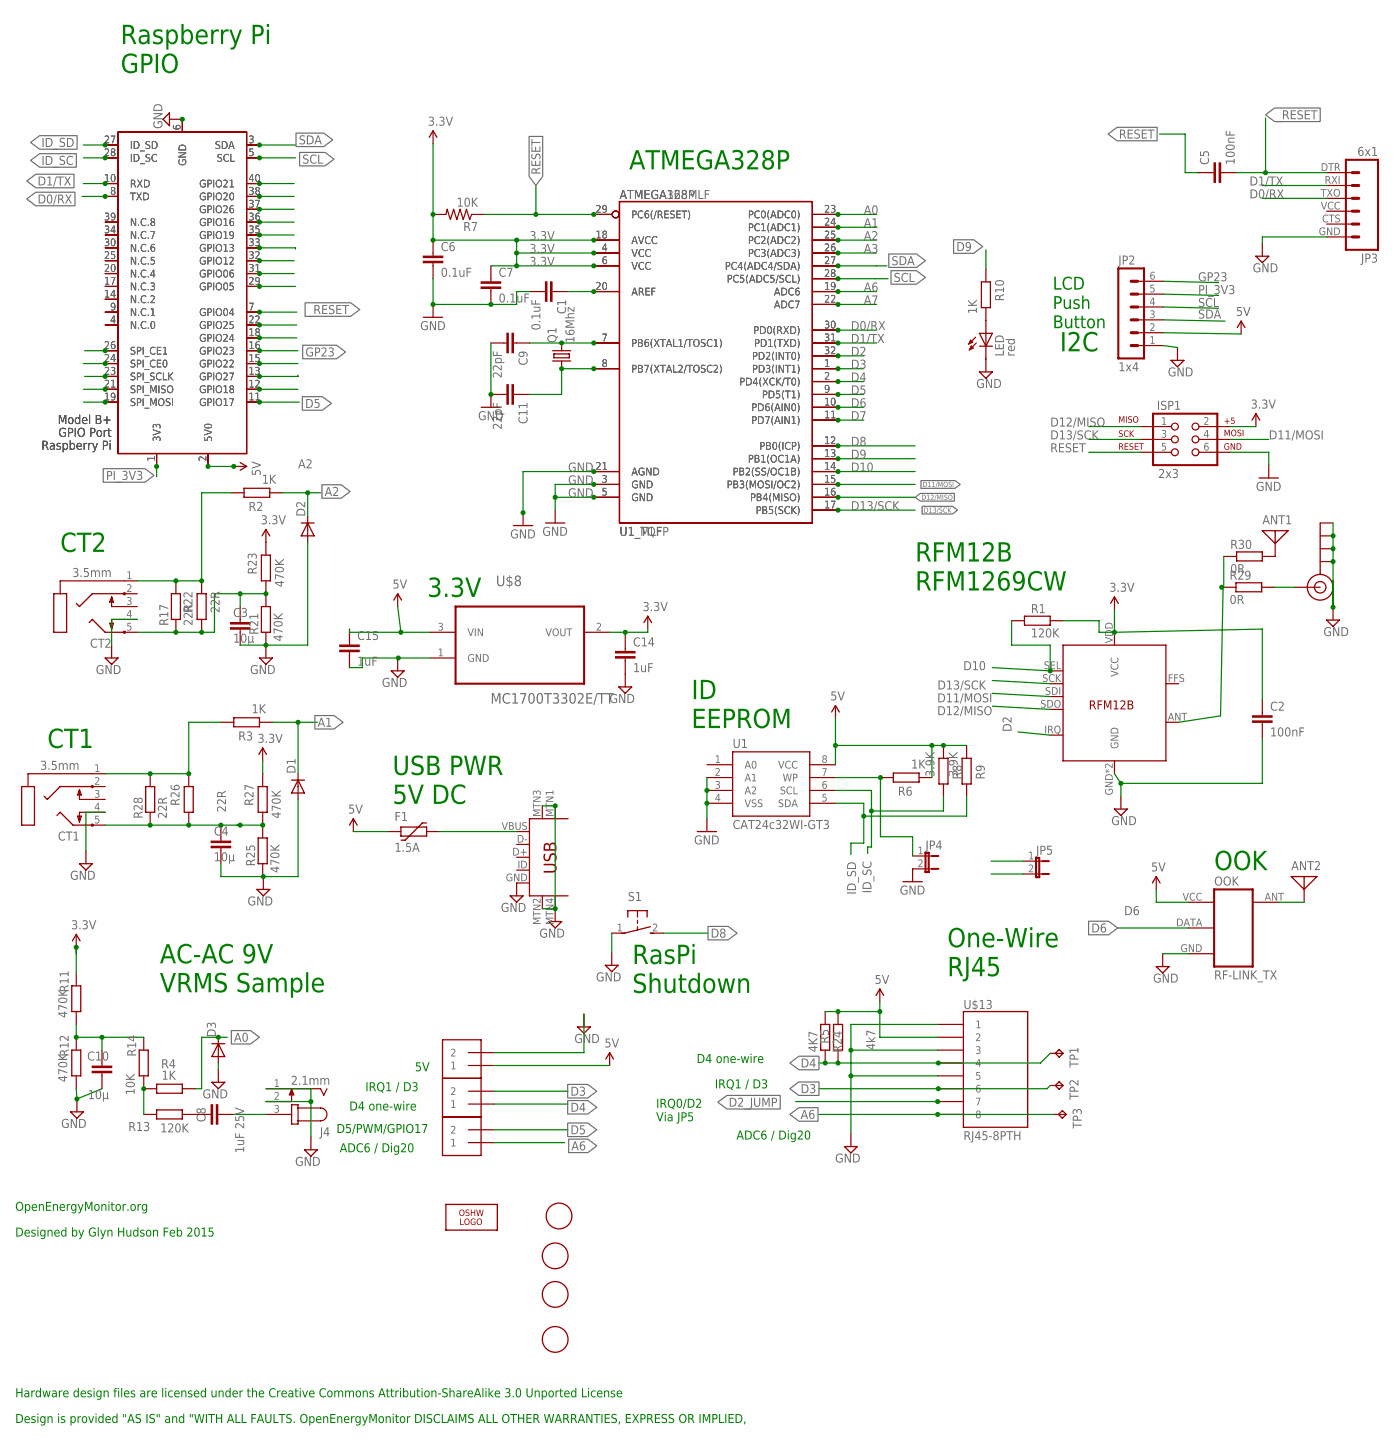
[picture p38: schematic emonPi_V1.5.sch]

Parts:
ANT1, ANT2: ANTENNA; PAD-01
C1, C6, C7: 0.1uF; C0603
C2, C5: 100nF; C0603
C3, C4, C10: 10µ; C0603
C8: 1uF 25V; C0603
C9, C11: 22pF; C0603
C14, C15: 1uF; C0603
CT1, CT2: 3.5mm; STX3100
D1, D2, D3: DIODE-SOD523; SOD523
F1: 1.5A; PTC1812L
ISP1: 2x3; 2X3
J1, J2, J3: 1X2-3.5MM
J4: 2.1mm; SPC4077
J$1: SMA_EDGE; SMA-EDGE
JP2: 1x4; MA06-1
JP3: 6x1; FTDI_BASIC
JP4, JP5: JUMPER-2PTH; 1X02
LED: red; CHIPLED_0805
LOGO1: OSHW_LOGO_10MILX0200-NT; OSHW_10X200_NOTEXT
OOK: RF-LINK_TX
Q1: 16Mhz; HC49UP
R1, R13: 120K; R0603
R2, R3, R4, R6, R10: 1K; R0603
R5: 4k7; 0204/7
R7, R14: 10K; R0603
R8, R9: 3.9K; R0603
R11, R12, R21, R23, R25, R27: 470K; R0603
R17, R28: 22R; R1206
R22, R26: 22R; 0204/7
R24: 4K7; R0603
R29, R30: 0R; R0603
S1: 31-XX; B3F-31XX
TP1, TP2, TP3: TPPAD1-13; P1-13
U1: CAT24c32WI-GT3; SO08
U1_MLF: ATMEGA168MLF; MLF32
U1_TQFP: ATMEGA328P; TQFP32-08
U$1, U$3, U$4, U$5: FIDUCIAL; FIDUCIAL_1MM
U$7: USB-MINIB-5PIN; USB-MINIB-CISECO
U$8: MC1700T3302E/TT; SOT95P237X112-3N
U$13: RJ45-8PTH; RJ45-8
U$14: RFM12B
X1: RASPI_GPIO_B+_SMT; RASPI_SMT_GPIO_B+_PIN
X4: RASPI_GPIO_B+_PIN

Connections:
3.3V: C2.1, C6.1, C7.1, C14.1, ISP1.2, R1.2, R7.2, R11.2, R23.2, R27.2, U1_MLF.4 (VCC), U1_MLF.6 (VCC), U1_MLF.18 (AVCC), U1_TQFP.4 (VCC), U1_TQFP.6 (VCC), U1_TQFP.18 (AVCC), U$8.2 (VOUT), U$14.VDD (VCC)
5V: C15.1, F1.1, J1.1, JP2.2, OOK.VCC (+5V), R5.2, R6.1, R8.1, R9.1, R24.1, U1.8 (VCC), U$8.3 (VIN), U$13.2, X1.2 (5V0), X4.2 (5V0)
A0: D3.C, R4.1, U1_MLF.23 (PC0(ADC0)), U1_TQFP.23 (PC0(ADC0))
A1: D1.C, R3.1, U1_MLF.24 (PC1(ADC1)), U1_TQFP.24 (PC1(ADC1))
A2: D2.C, R2.1, U1_MLF.25 (PC2(ADC2)), U1_TQFP.25 (PC2(ADC2))
A3: U1_MLF.26 (PC3(ADC3)), U1_TQFP.26 (PC3(ADC3))
A6: J3.1, TP3.TP, U1_MLF.19 (ADC6), U1_TQFP.19 (ADC6), U$13.8
A7: U1_MLF.22 (ADC7), U1_TQFP.22 (ADC7)
D0/RX: JP3.TXO (3), U1_MLF.30 (PD0(RXD)), U1_TQFP.30 (PD0(RXD)), X1.8 (TXD), X4.8 (TXD)
D1/TX: JP3.RXI (2), U1_MLF.31 (PD1(TXD)), U1_TQFP.31 (PD1(TXD)), X1.10 (RXD), X4.10 (RXD)
D2: JP5.1, U1_MLF.32 (PD2(INT0)), U1_TQFP.32 (PD2(INT0)), U$14.IRQ
D2_JUMP: JP5.2, U$13.7
D3: J2.2, TP2.TP, U1_MLF.1 (PD3(INT1)), U1_TQFP.1 (PD3(INT1)), U$13.6
D4: J2.1, R5.1, R24.2, TP1.TP, U1_MLF.2 (PD4(XCK/T0)), U1_TQFP.2 (PD4(XCK/T0)), U$13.4
D5: J3.2, U1_MLF.9 (PD5(T1)), U1_TQFP.9 (PD5(T1)), X1.11 (GPIO17), X4.11 (GPIO17)
D6: OOK.DATA, U1_MLF.10 (PD6(AIN0)), U1_TQFP.10 (PD6(AIN0))
D7: U1_MLF.11 (PD7(AIN1)), U1_TQFP.11 (PD7(AIN1))
D8: S1.2 (S), U1_MLF.12 (PB0(ICP)), U1_TQFP.12 (PB0(ICP))
D9: R10.2, U1_MLF.13 (PB1(OC1A)), U1_TQFP.13 (PB1(OC1A))
D10: R1.1, U1_MLF.14 (PB2(SS/OC1B)), U1_TQFP.14 (PB2(SS/OC1B)), U$14.SEL
D11/MOSI: ISP1.4, U1_MLF.15 (PB3(MOSI/OC2)), U1_TQFP.15 (PB3(MOSI/OC2)), U$14.SDI
D12/MISO: ISP1.1, U1_MLF.16 (PB4(MISO)), U1_TQFP.16 (PB4(MISO)), U$14.SDO
D13/SCK: ISP1.3, U1_MLF.17 (PB5(SCK)), U1_TQFP.17 (PB5(SCK)), U$14.SCK
DIG6: R29.1, R30.1, U$14.ANT
GND: C1.2, C2.2, C3.2, C4.2, C6.2, C7.2, C9.2, C10.2, C11.2, C14.2, C15.2, CT1.4, CT2.4, D1.A, D2.A, D3.A, ISP1.6, J1.2, J4.1, J4.2, J$1.GND@0 (GND), J$1.GND@1 (GND), J$1.GND@2 (GND), J$1.GND@3 (GND), JP2.1, JP3.GND (6), JP4.2, LED.C, OOK.GND, R12.1, R21.2, R25.2, S1.1, U1.2 (A1), U1.3 (A2), U1.4 (VSS), U1_MLF.3 (GND), U1_MLF.5 (GND), U1_MLF.21 (AGND), U1_TQFP.3 (GND), U1_TQFP.5 (GND), U1_TQFP.21 (AGND), U$7.GND, U$7.MTN1 (MTN2), U$7.MTN2 (MTN3), U$7.MTN3 (MTN1), U$7.MTN4, U$8.1 (GND), U$13.1, U$13.3, U$13.5, U$14.GND, U$14.P$12 (GND), X1.6 (GND), X4.6 (GND)
GP23: JP2.6, X1.16 (GPIO23), X4.16 (GPIO23)
ID_SC: R8.2, U1.6 (SCL), X1.28 (ID_SC), X4.28 (ID_SC)
ID_SD: R9.2, U1.5 (SDA), X1.27 (ID_SD), X4.27 (ID_SD)
unnamed: C9.1, Q1.2, U1_MLF.7 (PB6(XTAL1/TOSC1)), U1_TQFP.7 (PB6(XTAL1/TOSC1))
unnamed: C11.1, Q1.1, U1_MLF.8 (PB7(XTAL2/TOSC2)), U1_TQFP.8 (PB7(XTAL2/TOSC2))
unnamed: C3.1, CT2.5, R17.1, R21.1, R22.1, R23.1
unnamed: C8.1, R13.1
unnamed: R4.2, R13.2, R14.1
unnamed: CT1.1, R3.2, R26.2, R28.2
unnamed: ANT1.1, R30.2
unnamed: ANT2.1, OOK.ANT
unnamed: C4.1, CT1.5, R25.1, R26.1, R27.1, R28.1
unnamed: F1.2, U$7.VBUS
unnamed: CT2.1, R2.2, R17.2, R22.2
unnamed: C8.2, J4.3
unnamed: C1.1, U1_MLF.20 (AREF), U1_TQFP.20 (AREF)
unnamed: J$1.SIG (SIGNAL), R29.2
unnamed: X1.12 (GPIO18), X4.12 (GPIO18)
unnamed: X1.13 (GPIO27), X4.13 (GPIO27)
unnamed: X1.15 (GPIO22), X4.15 (GPIO22)
unnamed: C10.1, R11.1, R12.2, R14.2
unnamed: X1.18 (GPIO24), X4.18 (GPIO24)
unnamed: X1.22 (GPIO25), X4.22 (GPIO25)
unnamed: LED.A, R10.1
unnamed: X1.19 (SPI_MOSI), X4.19 (SPI_MOSI)
unnamed: X1.21 (SPI_MISO), X4.21 (SPI_MISO)
unnamed: X1.23 (SPI_SCLK), X4.23 (SPI_SCLK)
unnamed: X1.24 (SPI_CE0), X4.24 (SPI_CE0)
unnamed: X1.26 (SPI_CE1), X4.26 (SPI_CE1)
unnamed: X1.4 (N.C.0), X4.4 (N.C.0)
unnamed: X1.9 (N.C.1), X4.9 (N.C.1)
unnamed: X1.14 (N.C.2), X4.14 (N.C.2)
unnamed: X1.17 (N.C.3), X4.17 (N.C.3)
unnamed: X1.20 (N.C.4), X4.20 (N.C.4)
unnamed: X1.25 (N.C.5), X4.25 (N.C.5)
unnamed: X1.29 (GPIO05), X4.29 (GPIO05)
unnamed: X1.31 (GPIO06), X4.31 (GPIO06)
unnamed: X1.32 (GPIO12), X4.32 (GPIO12)
unnamed: X1.33 (GPIO13), X4.33 (GPIO13)
unnamed: X1.35 (GPIO19), X4.35 (GPIO19)
unnamed: X1.36 (GPIO16), X4.36 (GPIO16)
unnamed: X1.37 (GPIO26), X4.37 (GPIO26)
unnamed: X1.38 (GPIO20), X4.38 (GPIO20)
unnamed: X1.40 (GPIO21), X4.40 (GPIO21)
unnamed: X1.30 (N.C.6), X4.30 (N.C.6)
unnamed: X1.34 (N.C.7), X4.34 (N.C.7)
unnamed: X1.39 (N.C.8), X4.39 (N.C.8)
unnamed: JP4.1, R6.2, U1.7 (WP)
PI_3V3: JP2.5, X1.1 (3V3), X4.1 (3V3)
RESET: C5.1, ISP1.5, R7.1, U1_MLF.29 (PC6(/RESET)), U1_TQFP.29 (PC6(/RESET))
SCL: JP2.4, U1_MLF.28 (PC5(ADC5/SCL)), U1_TQFP.28 (PC5(ADC5/SCL)), X1.5 (SCL), X4.5 (SCL)
SDA: JP2.3, U1_MLF.27 (PC4(ADC4/SDA)), U1_TQFP.27 (PC4(ADC4/SDA)), X1.3 (SDA), X4.3 (SDA)
_RESET: C5.2, JP3.DTR (1), X1.7 (GPIO04), X4.7 (GPIO04)

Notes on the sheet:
AC-AC 9V VRMS Sample
OpenEnergyMonitor.org
Designed by Glyn Hudson Feb 2015
Hardware design files are licensed under the Creative Commons Attribution-ShareAlike 3.0 Unported License
Design is provided "AS IS" and "WITH ALL FAULTS. OpenEnergyMonitor DISCLAIMS ALL OTHER WARRANTIES, EXPRESS OR IMPLIED,
D4 one-wire
IRQ1 / D3
ADC6 / Dig20
D5/PWM/GPIO17
USB PWR 5V DC
RasPi Shutdown
I2C
RFM12B RFM1269CW
OOK
One-Wire RJ45
CT1
CT2
Raspberry Pi GPIO
ATMEGA328P
LCD Push Button
ID EEPROM
IRQ0/D2 Via JP5
3.3V

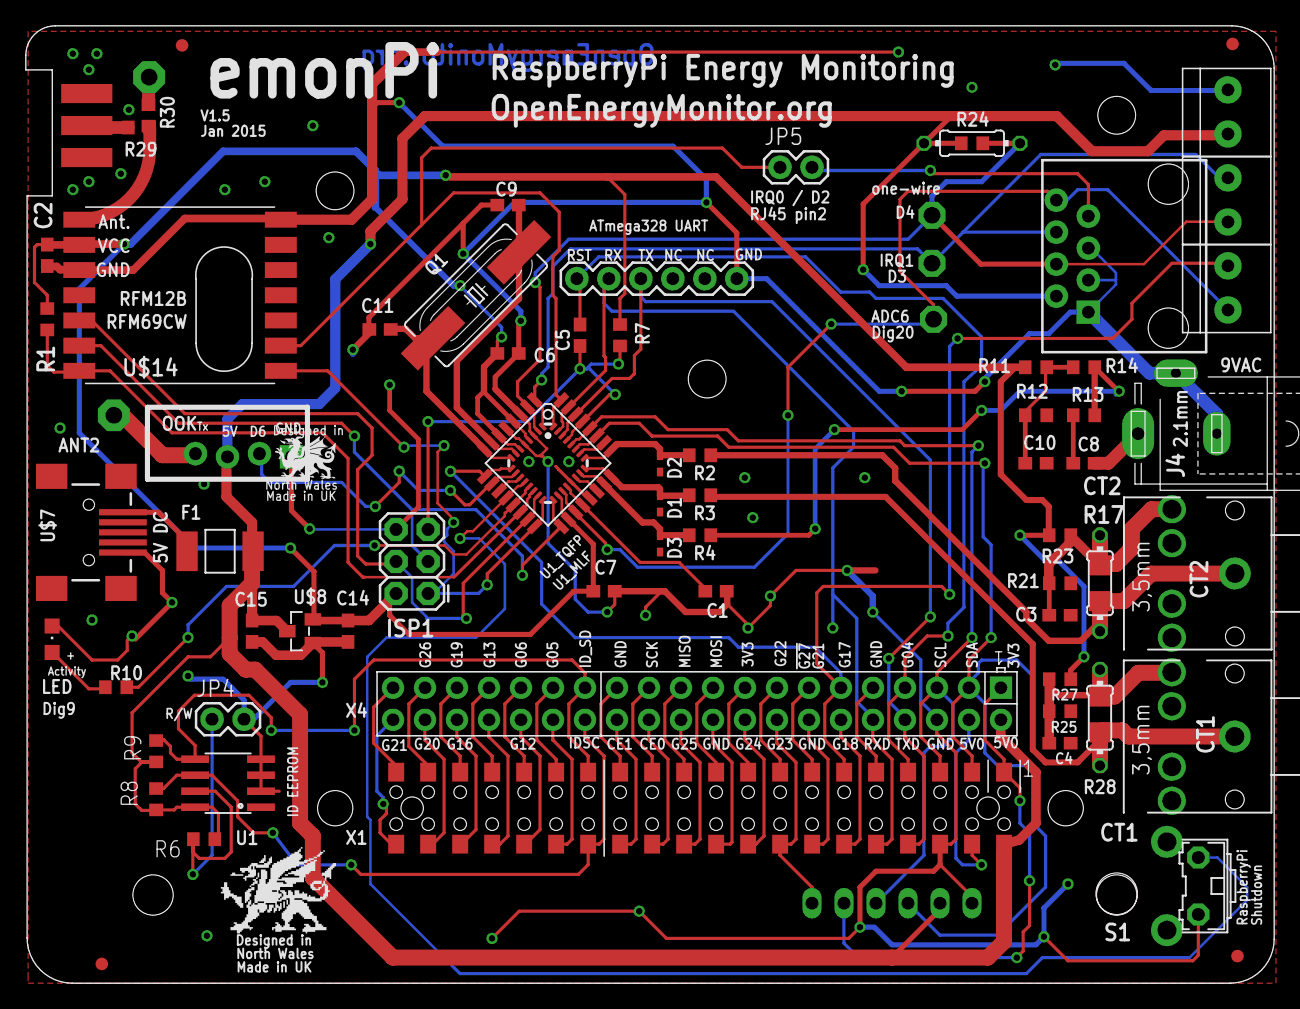
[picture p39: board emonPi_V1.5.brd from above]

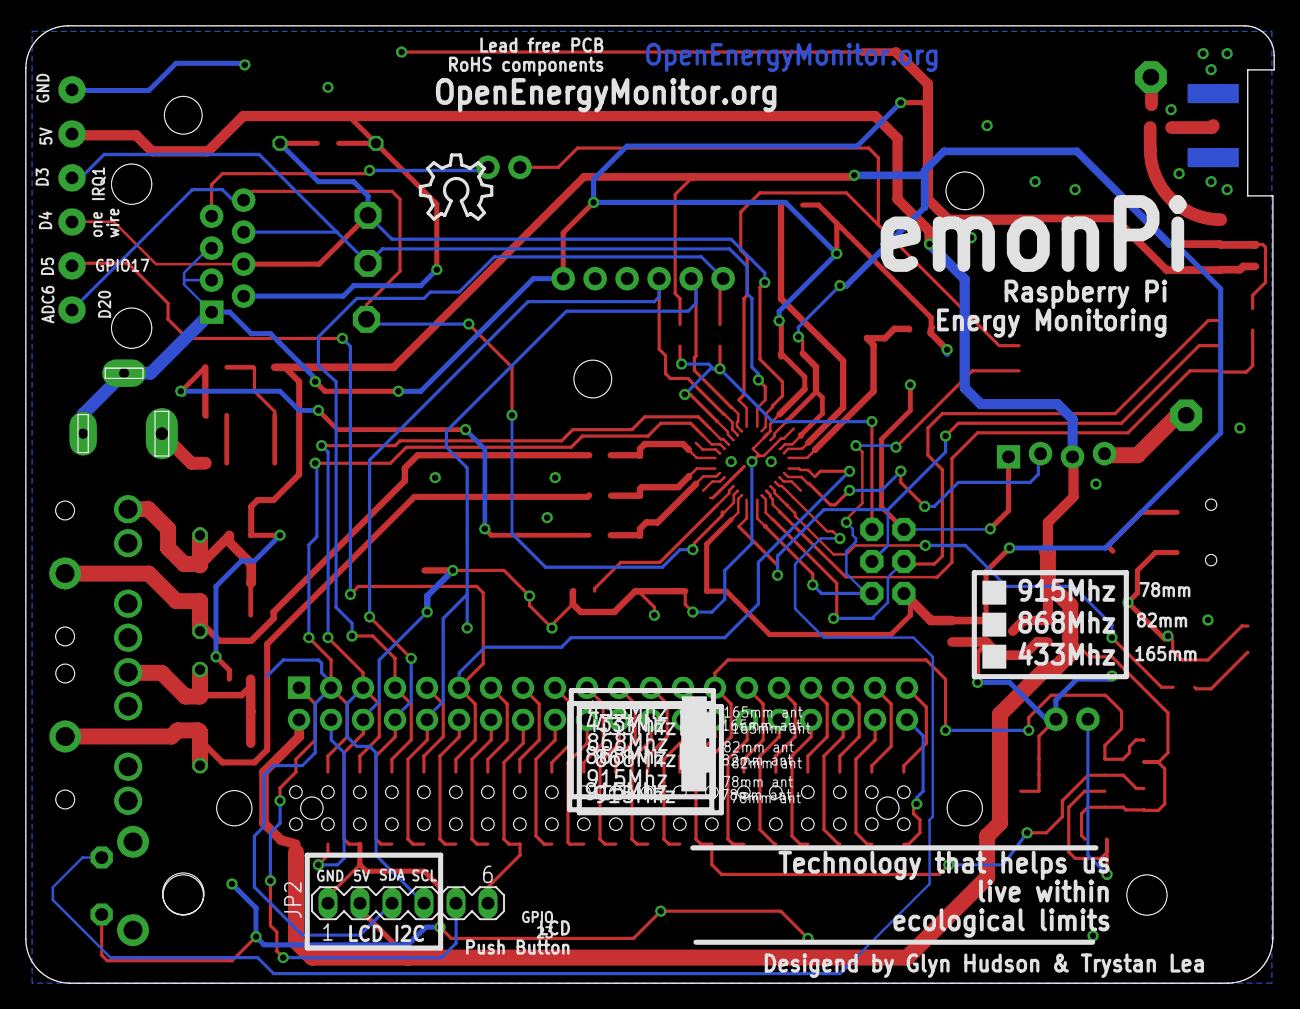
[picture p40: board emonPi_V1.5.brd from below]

Board: 2 copper layers, 99.1 x 76.0 mm, 78 parts (2 on the bottom side), 78 nets.

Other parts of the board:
U$9: STAND-OFF

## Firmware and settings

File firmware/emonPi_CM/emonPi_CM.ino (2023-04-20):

/*


  emonPi Continuous Monitoring - radio using JeeLib RFM69 "Native" format

  
   ------------------------------------------
  Part of the openenergymonitor.org project

  Authors: Glyn Hudson, Trystan Lea & Robert Wall
  Builds upon JCW JeeLabs RF69 Driver and Arduino

  Licence: GNU GPL V3

//----------------------------emonPi Firmware Version---------------------------------------------------------------------------------------- 
*/

const byte firmware_version[3] = {1,1,4};
/*
V1.0.0   10/7/2021 Derived from emonLibCM examples and original emonPi sketch, that being derived from 
            https://github.com/openenergymonitor/emonpi/blob/master/Atmega328/emonPi_RFM69CW_RF12Demo_DiscreteSampling
            and emonLibCM example sketches, with config input based on emonTx V3 sketches.
v1.1.0   16/2/2023 Support for LowPowerLabs
v1.1.1   16/2/2023 Print Radio format at startup, include message count in output
v1.1.2   28/3/2023 Fix missing ACKRequested sendACK
v1.1.3   04/4/2023 Updated to use cut down version of RFM69 LowPowerLabs library
                   Updated to match latest EmonLibCM library and emonPiFrontEndCM sketch from Robert
v1.1.4   19/4/2023 Faster baud rate 115200 and reduced delay in the main loop to improve radio performance


emonhub.conf node decoder (assuming Node 5):

[[5]]
    nodename = emonpi
    [[[rx]]]
        names = Msg, power1,power2,power1pluspower2,vrms,t1,t2,t3,t4,t5,t6,pulse1count,pulse2count,E1,E2
        datacodes = L, h, h, h, h, h, h, h, h, h, h, L, L, l, l
        scales = 1, 1,1,1, 0.01, 0.01,0.01,0.01,0.01,0.01,0.01, 1, 1, 1,1
        units = n,W,W,W, V, C,C,C,C,C,C, p, p, Wh,Wh

*/
// #define EEWL_DEBUG
// #define SAMPPIN 19 

#define RFM69_JEELIB_NATIVE 2
#define RFM69_LOW_POWER_LABS 3

#define RadioFormat RFM69_LOW_POWER_LABS

#include <emonLibCM.h>                                                 // OEM CM library

#include <emonEProm.h>                                                // OEM EPROM library

// RFM interface
#if RadioFormat == RFM69_LOW_POWER_LABS
  #include <RFM69_LPL.h>
  RFM69 radio;
#else
  #include "spi.h"                                                       // Requires "RFM69 Native" JeeLib Driver
  #include "rf69.h"
  RF69<SpiDev10> rf;
#endif

bool rfDataAvailable = false;

byte nativeMsg[66];                                                    // 'Native' format message buffer

#define MAXMSG 62                                                      // Max length of o/g message - payload can be 62 bytes max in RFM69
char outmsg[MAXMSG];                                                   // outgoing message (to emonGLCD etc)
byte outmsgLength = 0;                                                     // length of message: non-zero length triggers transmission
byte txDestId = 0 ;                                                    // 
struct {                                                               // Ancilliary information
  byte srcNode = 0;
  byte msgLength = 0;
  signed char rssi = -127;
  bool crc = false;
} rfInfo;

enum rfband {RFM_433MHZ = 1, RFM_868MHZ, RFM_915MHZ };                 // frequency band.
bool rfChanged = false;                                                // marker to re-initialise radio
#define RFRX 0x01                                                      // Control of RFM - receive enabled
#define RFTX 0x02                                                      // Control of RFM - transmit enabled

#include <LiquidCrystal_I2C.h>                                         // https://github.com/openenergymonitor/LiquidCrystal_I2C

int i2c_lcd_address[2]          = {0x27, 0x3f};                        // I2C addresses to test for I2C LCD device
int current_lcd_i2c_addr;                                              // Used to store current I2C address as found by i2_lcd_detect()
// LiquidCrystal_I2C lcd(0x27,16,2);                                   // Placeholder
LiquidCrystal_I2C lcd(0,0,0);

bool backlight = false;                                                // Controls for backlight timeout
bool backlightTimer = false;
unsigned long backlightOn;
#define BACKLIGHT_TIMEOUT 60000UL                                      // Timeout in ms (only for data from here)


//----------------------------emonPi Settings------------------------------------------------------------------------------------------------
bool debug                      = true;
bool verbose                    = false;
const unsigned long BAUD_RATE   = 115200;


int i2c_LCD_Detect(int i2c_lcd_address[]);
void emonPi_LCD_Startup(int current_i2c_addr);
void Startup_to_LCD(int current_lcd_i2c_addr);
void lcd_print_currents(int current_lcd_i2c_addr, float I1, float I2, float pf1, float pf2);

void getCalibration(void);
void send_emonpi_serial();
void emonPi_startup(void);
static void showString (PGM_P s);


//--------------------------- temperature data ----------------------------------------------------------------------------------------------

const byte MaxOnewire = 6;                              // maximum number of DS18B20 one wire sensors 
int allTemps[MaxOnewire];                               // Array to receive temperature measurements
const byte TEMPERATURE_PRECISION = 11;                  // 9 (93.8ms), 10 (187.5ms), 11 (375ms) or 12 (750ms) bits equal to resolution of 0.5C, 0.25C, 0.125C and 0.0625C

//---------------------------- emonPi Settings - Stored in EEPROM and shared with config.ino ------------------------------------------------
struct {
  byte RF_freq = RFM_433MHZ;                            // Frequency of radio module can be RFM_433MHZ, RFM_868MHZ or RFM_915MHZ. 
  byte rfPower = 25;                                    // Power when transmitting
  byte networkGroup = 210;                              // wireless network group, must be the same as emonBase / emonPi and emonGLCD. OEM default is 210
  byte  nodeID = 5;                                     // node ID for this emonPi.
  float vCal  = 268.97;                                 // (240V x 13) / 11.6V = 268.97 Calibration for UK AC-AC adapter 77DB-06-09
  float assumedVrms = 240.0;                            // Assumed Vrms when no a.c. is detected
  float lineFreq = 50;                                  // Line Frequency = 50 Hz
  float i1Cal = 90.9;                                   // (100 A / 50 mA / 22 Ohm burden) = 90.9
  float i1Lead = 1.2;                                   // 1.2° phase lead
  float i2Cal = 90.9;
  float i2Lead = 1.2; 
  float period = 9.85;                                  // datalogging period - should be fractionally less than the PHPFINA database period in emonCMS
  bool  pulse_enable = true;                            // pulse 1 counting 1
  int   pulse_period = 0;                               // pulse 1 min period - 0 = no de-bounce
  bool  pulse2_enable = false;                          // pulse 2 counting 2
  int   pulse2_period = 0;                              // pulse 2 min period - 0 = no de-bounce
  bool  temp_enable = true;                             // enable temperature measurement
  DeviceAddress allAddresses[MaxOnewire];               // sensor address data
  bool  showCurrents = false;                           // Print to serial voltage, current & p.f. values  
  byte  rfOn = 0x03;                                    // Turn transmitter AND receiver on
} EEProm;

uint16_t eepromSig = 0x0010;                            // EEPROM signature - see oemEProm Library documentation for details.

//-------------------------------------------------------------------------------------------------------------------------------------------
//-------------------------------------------------------------------------------------------------------------------------------------------

bool shutdown_switch_last_state = false;

//--------------------------- hard-wired connections ----------------------------------------------------------------------------------------

const byte LEDpin               = 9;                                   // emonPi LED - on when HIGH
const byte shutdown_switch_pin  = 8;                                   // Push-to-make - Low when pressed
const byte emonpi_GPIO_pin      = 5;                                   // Connected to Pi GPIO 17, used to activate Pi Shutdown when HIGH
//const byte emonPi_RJ45_8_IO   = A6;                                  // RJ45 pin 8 - Analog 6 - Aux I/O - D20?
const byte emonPi_int0          = 0;                                   // RJ45 pin 6 - INT0 - Dig 2 - default pulse count interrupt
const byte emonPi_int0_pin      = 2;                                   // RJ45 pin 6 - INT0 - Dig 2 - default pulse count input pin
const byte emonPi_int1          = 1;                                   // RJ45 pin 6 - INT1 - Dig 3 - default pulse count interrupt
const byte emonPi_int1_pin      = 3;                                   // RJ45 pin 6 - INT1 - Dig 3 - default pulse count input pin

// Use D5 for ISR timimg checks - only if Pi is not connected!

//-------------------------------------------------------------------------------------------------------------------------------------------

struct 
{
  unsigned long Msg;
  int power1;                                                          // Powers in watts
  int power2;
  int power1_plus_2;                                                   // added here to assure sum is from the same sampling period
  int Vrms;
  int temp[MaxOnewire];
  unsigned long pulseCount;                                            // in whatever units the meter records
  unsigned long pulse2Count;                                           // in whatever units the meter records
  long E1;                                                             // Accumulated energy from powers in Wh
  long E2;
} emonPi;                                                              // Data format for byte-wise serial transfer to Raspberry Pi
//-------------------------------------------------------------------------------------------------------------------------------------------
//-------------------------------------------------------------------------------------------------------------------------------------------

#ifdef EEWL_DEBUG
  extern EEWL EVmem;
#endif


/**************************************************************************************************************************************************
*
* SETUP        Set up & start the display, the radio & emonLibCM
*
***************************************************************************************************************************************************/
void setup() 
{  

  emonPi_startup();

  delay(2000);

  EmonLibCM_SetADC_VChannel(0, EEProm.vCal);                           // ADC Input channel, voltage calibration - for Ideal UK Adapter = 268.97
  EmonLibCM_SetADC_IChannel(1, EEProm.i1Cal, EEProm.i1Lead);           // ADC Input channel, current calibration, phase calibration
  EmonLibCM_SetADC_IChannel(2, EEProm.i2Cal, EEProm.i2Lead);           // The current channels will be read in this order

  EmonLibCM_ADCCal(3.3);                                               // ADC Reference voltage, (3.3 V)
  EmonLibCM_cycles_per_second(EEProm.lineFreq);                        // mains frequency 50/60Hz
  
  EmonLibCM_setAssumedVrms(EEProm.assumedVrms);

  EmonLibCM_setPulseEnable(true);                                      // Enable pulse counting
  EmonLibCM_setPulsePin(0, emonPi_int1_pin, emonPi_int1);              // Pulse input Pin, Interrupt
  EmonLibCM_setPulseMinPeriod(0, EEProm.pulse_period, (byte)FALLING);  // Minimum pulse period
  EmonLibCM_setPulseEnable(1, EEProm.pulse2_enable);                   // Enable pulse counting
  EmonLibCM_setPulsePin(1, emonPi_int1_pin, emonPi_int1);              // Pulse input Pin, Interrupt
  EmonLibCM_setPulseMinPeriod(1, EEProm.pulse_period, (byte)FALLING);  // Minimum pulse period

  EmonLibCM_setTemperatureDataPin(4);                                  // OneWire data pin 
  EmonLibCM_setTemperaturePowerPin(-1);                                // Temperature sensor Power Pin - Not used.
  EmonLibCM_setTemperatureResolution(TEMPERATURE_PRECISION);           // Resolution in bits, allowed values 9 - 12. 11-bit resolution, reads to 0.125 degC
  EmonLibCM_setTemperatureAddresses(EEProm.allAddresses, true);        // Name of array of temperature sensors
  EmonLibCM_setTemperatureArray(allTemps);                             // Name of array to receive temperature measurements
  EmonLibCM_setTemperatureMaxCount(MaxOnewire);                        // Max number of sensors, limited by wiring and array size.


#ifdef EEWL_DEBUG
  Serial.print(F("End of mem="));Serial.print(E2END);
  Serial.print(F(" Avail mem="));Serial.print((E2END>>2) * 3);
  Serial.print(F(" Start addr="));Serial.print(E2END - (((E2END>>2) * 3) / (sizeof(mem)+1))*(sizeof(mem)+1));
  Serial.print(F(" Num blocks="));Serial.println(((E2END>>2) * 3) / 21);
  EVmem.dump_buffer();
#endif
  // Recover saved energy & pulse count from EEPROM
  {
    long E1 = 0, E2 = 0;
    unsigned long p1 = 0, p2 = 0;
    
    recoverEValues(&E1, &E2, &p1, &p2);
    EmonLibCM_setWattHour(0, E1);
    EmonLibCM_setWattHour(1, E2);
    EmonLibCM_setPulseCount(0, p1);
    EmonLibCM_setPulseCount(1, p2);
  }

  EmonLibCM_TemperatureEnable(EEProm.temp_enable);                     // Temperature monitoring enable
  EmonLibCM_min_startup_cycles(10);                                    // number of cycles to let ADC run before starting first actual measurement

  EmonLibCM_datalog_period(0.5);                                       // Get a quick reading for display of voltage, temp sensor count.
  

  // Detect and startup I2C LCD
  current_lcd_i2c_addr = i2c_LCD_Detect(i2c_lcd_address);

  LiquidCrystal_I2C lcd(current_lcd_i2c_addr,16,2);                    // LCD I2C address to 0x27, 16x2 line display
  emonPi_LCD_Startup(current_lcd_i2c_addr);
  backlightTimer = true;

  EmonLibCM_Init();                                                    // Start continuous monitoring.

  while (!EmonLibCM_Ready())                                           // Quick check for presence of a voltage
    ;
 
  EmonLibCM_datalog_period(EEProm.period);                             // Reset to NORMAL period of readings in seconds for emonCMS
  Startup_to_LCD(current_lcd_i2c_addr);

  #if RadioFormat == RFM69_LOW_POWER_LABS
    radio.initialize(RF69_433MHZ,EEProm.nodeID,EEProm.networkGroup);  
    radio.encrypt("89txbe4p8aik5kt3");
  #else
    rf.init(EEProm.nodeID, EEProm.networkGroup, 
               EEProm.RF_freq == RFM_915MHZ ? 915                      // Fall through to 433 MHz Band @ 434 MHz
            : (EEProm.RF_freq == RFM_868MHZ ? 868 : 434)); 
  #endif
  
  emonPi.Msg = 0;
}

/**************************************************************************************************************************************************
*
* LOOP         Read the pushbutton, poll the radio for incoming data, the serial input for calibration & emonLibCM for energy readings
*
***************************************************************************************************************************************************/

void loop()             
{
  
  if (digitalRead(shutdown_switch_pin) == 0 )
  {
    digitalWrite(emonpi_GPIO_pin, HIGH);                               // if emonPi shutdown button pressed then send signal to the Pi on GPIO 11
    shutdown_switch_last_state = true;
  }
  else
  {
    digitalWrite(emonpi_GPIO_pin, LOW);
    if (shutdown_switch_last_state)
      asm volatile ("  jmp 0");

  }
  
//-------------------------------------------------------------------------------------------------------------------------------------------
// RF Data handler - inbound ****************************************************************************************************************
//-------------------------------------------------------------------------------------------------------------------------------------------

  if ((EEProm.rfOn & RFRX))
  {
    #if RadioFormat == RFM69_LOW_POWER_LABS
    if (radio.receiveDone())
    {    
      digitalWrite(LEDpin, HIGH);
      
      rfInfo.msgLength = radio.DATALEN;
      rfInfo.srcNode = radio.SENDERID;
      for (byte i = 0; i < radio.DATALEN; i++) {
        nativeMsg[i] = radio.DATA[i];
      }
      rfInfo.rssi = radio.readRSSI();
      
      if (radio.ACKRequested()) {
        radio.sendACK();
      }    
    
      // send serial data
      Serial.print(F("OK"));                                              // Bad packets (crc failure) are discarded by RFM69CW
      print_frame(rfInfo.msgLength);		                                  // Print received data
      
      digitalWrite(LEDpin, LOW);
    }
    #else
    int len = rf.receive(&nativeMsg, sizeof(nativeMsg));                 // Poll the RFM buffer and extract the data
    if (len > 1)
    {
      digitalWrite(LEDpin, HIGH);
      
      rfInfo.crc = true;
      rfInfo.msgLength = len;
      rfInfo.srcNode = nativeMsg[1];
      rfInfo.rssi = -rf.rssi/2;

      // send serial data
      Serial.print(F("OK"));                                              // Bad packets (crc failure) are discarded by RFM69CW
      print_frame(rfInfo.msgLength);		                                  // Print received data
      
      digitalWrite(LEDpin, LOW);
    }
    #endif
  } 
  
//-------------------------------------------------------------------------------------------------------------------------------------------
// RF Data handler - outbound ***************************************************************************************************************
//-------------------------------------------------------------------------------------------------------------------------------------------


	if ((EEProm.rfOn & RFTX) && outmsgLength) {                           //if command 'outmsg' is waiting to be sent then let's send it
    digitalWrite(LEDpin, HIGH);
    Serial.print ("Sending ") ; Serial.print((word) outmsgLength); Serial.print(" bytes "); Serial.print("to node " ); Serial.println(txDestId) ;
    #if RadioFormat == RFM69_LOW_POWER_LABS
      radio.send(0, (void *)outmsg, outmsgLength);
    #else
      rf.send(txDestId, (void *)outmsg, outmsgLength);                    //  void RF69<SPI>::send (uint8_t header, const void* ptr, int len) {
    #endif
    outmsgLength = 0;
    digitalWrite(LEDpin, LOW);
	}

  
//-------------------------------------------------------------------------------------------------------------------------------------------
// Calibration Data handler *****************************************************************************************************************
//-------------------------------------------------------------------------------------------------------------------------------------------

  if (Serial.available())                                              // Serial input from RPi for configuration/calibration
  {
    digitalWrite(LEDpin, HIGH);
    getCalibration();                                                  // If serial input is received from RPi
    
    if (rfChanged)
    {
      #if RadioFormat == RFM69_LOW_POWER_LABS
        radio.initialize(EEProm.RF_freq,EEProm.nodeID,EEProm.networkGroup);  
        radio.encrypt("89txbe4p8aik5kt3"); 
      #else
        rf.init(EEProm.nodeID, EEProm.networkGroup,                      // Reset the RFM69CW if NodeID, Group or frequency has changed.
            EEProm.RF_freq == RFM_915MHZ ? 915 : (EEProm.RF_freq == RFM_868MHZ ? 868 : 434)); 
      #endif
      rfChanged = false;
    }
    digitalWrite(LEDpin, LOW);
  }

//-------------------------------------------------------------------------------------------------------------------------------------------
// Energy Monitor ***************************************************************************************************************************
//-------------------------------------------------------------------------------------------------------------------------------------------

  if (EmonLibCM_Ready())   
  {
    digitalWrite(LEDpin, HIGH);

    emonPi.power1 = EmonLibCM_getRealPower(0);                       // Copy the desired variables ready for transmission 
    emonPi.power2 = EmonLibCM_getRealPower(1); 
    emonPi.power1_plus_2 = emonPi.power1 + emonPi.power2;
    emonPi.E1     = EmonLibCM_getWattHour(0);
    emonPi.E2     = EmonLibCM_getWattHour(1);
   
    emonPi.Vrms     = EmonLibCM_getVrms() * 100;                       // Always send the ACTUAL measured voltage.

    if (EmonLibCM_getTemperatureSensorCount())
    {
      for (byte i=0; i< MaxOnewire; i++)
        emonPi.temp[i] = allTemps[i];
    }
   
    emonPi.pulseCount = EmonLibCM_getPulseCount(0);
    emonPi.pulse2Count = EmonLibCM_getPulseCount(1);
    
    send_emonpi_serial();                                              // Send emonPi data to Pi serial using packet structure

    if (EEProm.showCurrents)
    {
      // to show voltage, current & power factor for calibration:
      Serial.print(F("|Vrms:")); Serial.print(EmonLibCM_getVrms());

      Serial.print(F(", I1:")); Serial.print(EmonLibCM_getIrms(0));
      Serial.print(F(", pf1:")); Serial.print(EmonLibCM_getPF(0),4);

      Serial.print(F(", I2:")); Serial.print(EmonLibCM_getIrms(1));
      Serial.print(F(", pf2:")); Serial.print(EmonLibCM_getPF(1),4);
      
      Serial.print(F(", f:")); Serial.print(EmonLibCM_getLineFrequency());
      Serial.println();
      
      lcd_print_currents(current_lcd_i2c_addr, EmonLibCM_getIrms(0), EmonLibCM_getIrms(1), EmonLibCM_getPF(0), EmonLibCM_getPF(1));
    }
    delay(10);

    // Save energy & pulse count values to EEPROM
    storeEValues(emonPi.E1, emonPi.E2, emonPi.pulseCount, emonPi.pulse2Count);
    
    digitalWrite(LEDpin, LOW);
  }
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

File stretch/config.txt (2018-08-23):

# For more options and information see
# http://rpf.io/configtxt
# Some settings may impact device functionality. See link above for details

# uncomment if you get no picture on HDMI for a default "safe" mode
#hdmi_safe=1

# uncomment this if your display has a black border of unused pixels visible
# and your display can output without overscan
#disable_overscan=1

# uncomment the following to adjust overscan. Use positive numbers if console
# goes off screen, and negative if there is too much border
#overscan_left=16
#overscan_right=16
#overscan_top=16
#overscan_bottom=16

# uncomment to force a console size. By default it will be display's size minus
# overscan.
#framebuffer_width=1280
#framebuffer_height=720

# uncomment if hdmi display is not detected and composite is being output
#hdmi_force_hotplug=1

# uncomment to force a specific HDMI mode (this will force VGA)
#hdmi_group=1
#hdmi_mode=1

# uncomment to force a HDMI mode rather than DVI. This can make audio work in
# DMT (computer monitor) modes
#hdmi_drive=2

# uncomment to increase signal to HDMI, if you have interference, blanking, or
# no display
#config_hdmi_boost=4

# uncomment for composite PAL
#sdtv_mode=2

#uncomment to overclock the arm. 700 MHz is the default.
#arm_freq=800

# Uncomment some or all of these to enable the optional hardware interfaces
#dtparam=i2c_arm=on
#dtparam=i2s=on
#dtparam=spi=on

# Uncomment this to enable the lirc-rpi module
#dtoverlay=lirc-rpi

# Additional overlays and parameters are documented /boot/overlays/README

# Enable audio (loads snd_bcm2835)
dtparam=audio=on


# Enable serial over ttyAMA0 by disabling BT
dtoverlay=pi3-miniuart-bt

# Enable how power USB mode to power 3G modems
max_usb_current=1

# Cap RAM avilable to GPU to make more ram available for headless running
gpu_mem=16

# Underclock RasPi 3B+
arm_freq=1200
arm_freq_min=600

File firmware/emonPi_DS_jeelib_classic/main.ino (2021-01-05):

/*

  emonPi  Discrete Sampling

  If AC-AC adapter is detected assume emonPi is also powered from adapter (jumper shorted) and take Real Power Readings and disable sleep mode to keep load on power supply constant
  If AC-AC addapter is not detected assume powering from battereis / USB 5V AC sample is not present so take Apparent Power Readings and enable sleep mode

  Transmit values via RFM69CW radio

   ------------------------------------------
  Part of the openenergymonitor.org project

  Authors: Glyn Hudson & Trystan Lea
  Builds upon JCW JeeLabs RF12 library and Arduino

  Licence: GNU GPL V3

*/

/*Recommended node ID allocation
------------------------------------------------------------------------------------------------------------
-ID-	-Node Type-
0	- Special allocation in JeeLib RFM12 driver - reserved for OOK use
1-4     - Control nodes
5-10	- Energy monitoring nodes
11-14	--Un-assigned --
15-16	- Base Station & logging nodes
17-30	- Environmental sensing nodes (temperature humidity etc.)
31	- Special allocation in JeeLib RFM12 driver - Node31 can communicate with nodes on any network group
-------------------------------------------------------b------------------------------------------------------


Change Log:
https://github.com/openenergymonitor/emonpi/blob/master/Atmega328/emonPi_RFM69CW_RF12Demo_DiscreteSampling/compiled/CHANGE%20LOG.md

emonhub.conf node decoder:

[[5]]
    nodename = emonPi
    firmware = emonPi_RFM69CW_RF12Demo_DiscreteSampling.ino
    hardware = emonpi
    [[[rx]]]
        names = power1,power2,power1_plus_power2,Vrms,T1,T2,T3,T4,T5,T6,pulseCount
        datacodes = h, h, h, h, h, h, h, h, h, h, L
        scales = 1,1,1,0.01,0.1,0.1,0.1,0.1,0.1,0.1,1
        units = W,W,W,V,C,C,C,C,C,C,p

*/

#define emonTxV3                                                      // Tell emonLib this is the emonPi V3 - don't read Vcc assume Vcc = 3.3V as is always the case on emonPi eliates bandgap error and need for calibration http://harizanov.com/2013/09/thoughts-on-avr-adc-accuracy/
#define RF69_COMPAT 1                                                 // Set to 1 if using RFM69CW or 0 is using RFM12B

#include <JeeLib.h>                                                   // https://github.com/openenergymonitor/jeelib
#include <avr/pgmspace.h>
#include <util/parity.h>
ISR(WDT_vect) { Sleepy::watchdogEvent(); }                            // Attached JeeLib sleep function to Atmega328 watchdog -enables MCU to be put into sleep mode inbetween readings to reduce power consumption

#include "EmonLib.h"                                                  // Include EmonLib energy monitoring library https://github.com/openenergymonitor/EmonLib
EnergyMonitor ct1, ct2;

#include <OneWire.h>                                                  // http://www.pjrc.com/teensy/td_libs_OneWire.html
#include <DallasTemperature.h>                                        // http://download.milesburton.com/Arduino/MaximTemperature/DallasTemperature_LATEST.zip
#include <DS2438.h>                                                   // https://github.com/jbechter/arduino-onewire-DS2438


#include <Wire.h>                                                     // Arduino I2C library
#include <LiquidCrystal_I2C.h>                                        // https://github.com/openenergymonitor/LiquidCrystal_I2C

int i2c_lcd_address[2]={0x27, 0x3f};                                  // I2C addresses to test for I2C LCD device
int current_lcd_i2c_addr;                                                  // Used to store current I2C address as found by i2_lcd_detect()
// LiquidCrystal_I2C lcd(0x27,16,2);                                  // Placeholder
LiquidCrystal_I2C lcd(0,0,0);


//----------------------------emonPi Firmware Version---------------------------------------------------------------------------------------------------------------
// Changelog: https://github.com/openenergymonitor/emonpi/blob/master/firmware/readme.md
const int firmware_version = 293;                                     //firmware version x 100 e.g 100 = V1.00

//----------------------------emonPi Settings---------------------------------------------------------------------------------------------------------------
bool debug =                   true;
const unsigned long BAUD_RATE=    38400;

const byte Vrms_EU=               230;                              // Vrms for apparent power readings (when no AC-AC voltage sample is present)
const byte Vrms_USA=              120;                              // USA apparent power VRMS
const int TIME_BETWEEN_READINGS=  5000;                             // Time between readings (ms)
const unsigned long RF_RESET_PERIOD=        60000;                            // Time (ms) between RF resets (hack to keep RFM60CW alive)


//http://openenergymonitor.org/emon/buildingblocks/calibration

const float Ical1=                90.9;                             // (2000 turns / 22 Ohm burden) = 90.9
const float Ical2=                90.9;
float Vcal_EU=                    256.8;                             // (230V x 13) / (9V x 1.2) = 276.9 - Calibration for EU AC-AC adapter 77DE-06-09
const float Vcal_USA=             130.0;                             // Calibration for US AC-AC adapter 77DA-10-09
bool USA=                      false;
const byte min_pulsewidth=        60;                                // minimum width of interrupt pulse

const float phase_shift=          1.7;
const int no_of_samples=          1480;
const byte no_of_half_wavelengths= 20;
const int timeout=                2000;                               // emonLib timeout
const int ACAC_DETECTION_LEVEL=   3000;

const byte TEMPERATURE_PRECISION=  12;                                 // 9 (93.8ms),10 (187.5ms) ,11 (375ms) or 12 (750ms) bits equal to resplution of 0.5C, 0.25C, 0.125C and 0.0625C
const byte MaxOnewire=             6;                                  // maximum number of DS18B20 one wire sensors
bool RF_STATUS=                 true;                                  // Turn RF on and off
//-------------------------------------------------------------------------------------------------------------------------------------------
//-------------------------------------------------------------------------------------------------------------------------------------------
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

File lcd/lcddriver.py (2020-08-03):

from time import sleep
import smbus

# LCD Address
# ADDRESS = 0x27
# Update 16th Dec 16: I2C address is now set by calling 'lcd = lcddriver.lcd(0x27)' from withing the main program

# commands
LCD_CLEARDISPLAY = 0x01
LCD_RETURNHOME = 0x02
LCD_ENTRYMODESET = 0x04
LCD_DISPLAYCONTROL = 0x08
LCD_CURSORSHIFT = 0x10
LCD_FUNCTIONSET = 0x20
LCD_SETCGRAMADDR = 0x40
LCD_SETDDRAMADDR = 0x80

# flags for display entry mode
LCD_ENTRYRIGHT = 0x00
LCD_ENTRYLEFT = 0x02
LCD_ENTRYSHIFTINCREMENT = 0x01
LCD_ENTRYSHIFTDECREMENT = 0x00

# flags for display on/off control
LCD_DISPLAYON = 0x04
LCD_DISPLAYOFF = 0x00
LCD_CURSORON = 0x02
LCD_CURSOROFF = 0x00
LCD_BLINKON = 0x01
LCD_BLINKOFF = 0x00

# flags for display/cursor shift
LCD_DISPLAYMOVE = 0x08
LCD_CURSORMOVE = 0x00
LCD_MOVERIGHT = 0x04
LCD_MOVELEFT = 0x00

# flags for function set
LCD_8BITMODE = 0x10
LCD_4BITMODE = 0x00
LCD_2LINE = 0x08
LCD_1LINE = 0x00
LCD_5x10DOTS = 0x04
LCD_5x8DOTS = 0x00

# flags for backlight control
LCD_BACKLIGHT = 0x08
LCD_NOBACKLIGHT = 0x00

En = 0b00000100  # Enable bit
Rw = 0b00000010  # Read/Write bit
Rs = 0b00000001  # Register select bit


class lcd(object):
    # initializes objects and lcd
    def __init__(self, i2c_address=0x27, bus=1):
        self.bus = smbus.SMBus(bus)
        self.i2c_address = i2c_address
        self._backlight = LCD_NOBACKLIGHT

        # Set 4bit mode reliably
        self.lcd_write(0x03)
        self.lcd_write(0x03)
        self.lcd_write(0x03)
        self.lcd_write(0x02)

        self.lcd_write(LCD_FUNCTIONSET | LCD_2LINE | LCD_5x8DOTS | LCD_4BITMODE)
        self.lcd_write(LCD_DISPLAYCONTROL | LCD_DISPLAYON)
        self.lcd_write(LCD_CLEARDISPLAY)
        self.lcd_write(LCD_ENTRYMODESET | LCD_ENTRYLEFT)
        sleep(0.2)

    @property
    def backlight(self):
        return self._backlight
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

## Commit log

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2014-06-30 fix shutdown running as service
    [shutdownpi.py]
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2014-08-18 remove I2C handover, replaced with Pi shutdown LCD
2015-01-27 fix Rx packet formatting, node ID is still incorrect
    [emonPi_RF.ino, emonPi_RFM69CW_DiscreteSampling.ino]
2015-01-29 fix RF Rx packet printing
    [emonPi_RF.ino]
2015-02-02 fix new line after serial
    [emonPi_RF.ino, emonPi_Serial_LCD.ino, emonPi_Startup.ino]
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2015-02-17 add device tree I2C config for latest kernel in Pi2
2015-02-21 fix IP print out
    [emonPiLCD.py]
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2015-02-21 fix power string lenght
    [emonPiLCD.py]
2015-02-21 fix IP / network mixup
    [emonPiLCD.py]
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2015-02-24 fix serial printing format, emonHub now succesfully decodes packets from local sampling and RF receive data :-)
    [emonPi_RF.ino, emonPi_Serial_LCD.ino, emonPi_Startup.ino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]
2015-03-01 send shutdown button signal directly to the Pi via GPIO and let python LCD script handle
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2015-03-14 slow down post rate to 10's, disable LED only for RF receive, add support for auto detect and read from up to 6 DS18B20, add LCD display for EU/USA calibration
2015-03-14 enable setting Vcal via serial command '1v' = UK '2v'= USA
2015-03-16 fix interrupt pulse counting
    [emonPi_Serial_LCD.ino, emonPi_Startup.ino]
2015-03-17 LCD script for pi, tasks carried out in background thread accessed via redis in foreground thread
2015-03-17 set temperature validation to match sensor limits and only call request temperature one per loop
2015-03-17 correct number of temperature struct array
2015-03-19 change to 'p' to set AC calibration via serial 'v' is firmware version, bug fix temperate and pulse counting
    [emonPi_RF.ino, emonPi_Serial_LCD.ino, emonPi_Startup.ino]
2015-03-23 ddress the potential problem of a pulse arriving as the variable is accessed
    [emonPi_Startup.ino]
2015-04-22 look for node 15 from emonpi for power values
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2015-04-28 remove wifi noise page and formatting tweaks for LCD display
    [emonPiLCD.py]
2015-05-05 fix shutdown button to work when backlight is off
    [emonPiLCD.py]
2015-05-13 emonPi V1.2 firmware fix AC wave detect & AC calibration improve
    [emonPi_Startup.ino]
2015-05-27 explicit specify to switch to and pull from origin master github repo
2015-06-12 V1.7 fimrware fix AC-AC USA calibration bug
2015-06-12 remove RF reset as this issue has now been fixed in latest JeeLib
    [emonPi_RF.ino]
2015-10-30 echo current time and date to update log
2015-10-30 V1.8 firmware: Enable pulse count INT1 internal pull-up to fix spurious pulse count readings
    [emonPi_Startup.ino]
2015-11-05 add extra check IP address is numerical and remove scrip stopped debug
    On Raspbian Jessie while network is connecting a non numerical string was returned in place of the IP address. Added extra check so this would not be showing on the LCD.
    Removed "LCD STOPPED" message as this was interfering with shutdown sequence and causing backlight to be left on aftershutdown
    [emonPiLCD.py]
2015-11-12 pull from whatever branch we're currently on
    To enable update when on V9 branch
2015-11-12 pull from whatever branch we're currently on
    Will now work for updating when on V9 branch
2015-11-16 V1.9 firmware Fix counting pulses faster than 110ms
    [emonPi_Startup.ino]
2015-11-17 Add V2,0 firmware .hex - don't print ACK's to serial
2015-11-24 change location of pid file to /tmp to allow user pi to write
2015-11-25 move location of emonpiupdate.log
    move location of emonpiupdate.log to ~/data to make persistent on reboot since /var/log is mounted as tmpfs
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2015-12-17 keep copy of cmdline with noop settings and update fstab to not track directory acces times to minimise writes
2015-12-20 add MQTT authentication support to LCD script, fix RSSI error and add extra info pages
    [emonPiLCD.py]
2015-12-20 improved MQTT error notification
    [emonPiLCD.py]
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2015-12-20 add check to run LCD I2C detect script at startup and exit LCD script if not detected
2015-12-20 fix LCD detect when no LCD is present
    [emonPiLCD.py]
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2016-01-01 Fix it conversion error
    [emonPiLCD.py]
2016-01-02 Only display MQTT not connected error msg on screens which pull data from MQTT
    Fix issue where MQTT not connected error is displayed momentarily at startup while waiting for MQTT server to startup
    [emonPiLCD.py]
2016-01-04 don't sample from CT channels when no CT is connected
2016-01-04 Script is currently cloning the wrong branch
    'master' is set as the default branch in github, and which is being cloned by this script.
    By specifying '-b stable' forces the script to clone the 'stable' branch instead.
2016-01-24 mount entire /var/lib in tmpfs to fix dhcp, random-seed & openHAB read-only FS issues in one go
2016-01-26 Revert "mount entire /var/lib in tmpfs to fix dhcp, random-seed & openHAB read-only FS issues in one go"
    This reverts commit 56a6a8b829e276f094fdb7b8cab46d8ab59d3bbb.
2016-01-31 Use F() to reduce SRAM usage for Print-based classes
    The F-macro helps reduce SRAM by placing the string in PROGMEM
    Serial and LiquidCrystal_I2C both inherits Print
2016-02-08 fix display SD card version info at startup
    [emonPiLCD.py]
2016-02-20 V2.3 DS fix VRMS sampling bug
    [emonPi_Startup.ino]
2016-02-22 re-compile V2.3 firmware with Arduino 1.6.3 instead of 1.6.7 > fix LCD character issue :-/
2016-02-22 revert to Arduino 1.6.7 compiled version (smaller size) now LCD issue has been fixed by using https://github.com/marcoschwartz/LiquidCrystal_I2C
2016-02-22 add message to use updated LCD I2C lib
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2016-02-26 Avoid shell calls in background thread.
    - Use SIOCGIFADDR to find IP address.
    - Use /proc/net/wireless to find signal quality.
    [emonPiLCD.py]
2016-02-26 Fix whitespace as per PEP8.
    [emonPiLCD.py]
2016-02-26 Refactor to avoid globals. Always display on LCD.
    This patch significantly changes the structure of the code. There is now
    a main() function and the background thread is gone.
    To facilitate the removal of global variables there is now an LCD class
    which stores the lines to be displayed and ensures they are padded to 16
    chars.
    MQTT's own background thread is used to dispatch messages so that we
    don't have to handle reconnecting to mqtt ourselves.
    Since using ioctl to get the IP address of the interfaces is much
    faster we can now poll every second.
    Always display data on the LCD, even if the backlight is off.
    [emonPiLCD.py]
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2016-02-26 Avoid calling lcd.backlight too often.
    [emonPiLCD.py]
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2016-02-26 Simplify Temp2/Pulse page.
    basedata is a list of strings, so its elements can never be equal to an
    int. Just display 0C and 0p if there are no sensors connected.
2016-02-28 fix running on emonpi without gsm dongle
    [gsmhuaweistatus.py]
2016-03-01 improved HTTP error handling
    [gsmhuaweistatus.py]
2016-03-02 Use private attribute name for use in property.
    Fixes RuntimeError: maximum recursion depth exceeded
    [emonPiLCD.py]
2016-03-04 Only update LCD if the content has changed. Add error checking.
    [emonPiLCD.py]
2016-03-08 use serial1 instead of tty1 to be compatible with pi3
    https://www.raspberrypi.org/forums/viewtopic.php?f=107&t=138223
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2016-03-08 Fix bug: properties only work with new-style classes.
    [lcddriver.py]
2016-03-11 add hardware designs
    [emonPi2C_V1.1.brd, emonPi2C_V1.1.sch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]
2016-03-18 remove duplicated emonpi2c hardware
    [emonPi2C_V1.1.brd, emonPi2C_V1.1.sch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]
2016-04-07 don't print emoncms update finished since the update is not really finished
    this was misleading since after this emoncmsupdate script the emonPi update still needs to finished which takes some time as more services e.g emonPiLCD need to be restarted.
2016-04-15 update folder structure to keep arduino IDE happy
2016-04-28 no need to mount logrotate if logs and status are in /var/log RW tmpfs partition
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2016-05-12 turn on backlight if shutdown button is pressed
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2016-06-08 move comments onto different line to function decleration, fix platformio compile
    [firmware.ino, lcd_serial.ino, startup.ino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]
2016-06-12 rename firmware to src.ino so we can also still compile with Arduino IDE
2016-07-01 add sudoers entry for reboot button
2016-07-25 fix emonpi admin reboot button sudoers entry
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2016-10-14 needed sudo
    Cannot install, php_dir for channel "pecl.php.net" is not writeable by the current user
2016-11-19 Add "quiet mode" to the emonPi "RF" firmware
    Reintroduces the "quiet mode" seen in the rfm2pi firmwares to allow
    debugging of RF issues.
    Via serial "1q" sets quiet mode (default) and "0q" removes quiet mode
    for a more verbose output including bad packets that have failed crc
    checks. In emonHub it can be set with "quiet = true" or "quiet = false"
    in the interfacer settings.
    [rf.ino, src.ino]
2016-11-21 fix 3 figure firmware version LCD display
    [lcd_serial.ino, src.ino]
2016-11-28 fix emonPiLCD script not-connecting to MQTT at startup
    [emonPiLCD.py]
2016-11-28 fix LCD driver pio compile issue
2016-11-30 trigger emonpi update by holding emonPi LCD button at startup
2016-11-30 fix force update LCD push button startup
2016-12-16 add i2c LCD detection to LCD python script
2016-12-16 allow i2c LCD address to be set at runtime
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2017-04-26 faster AP stop when used in conjunction with raspberrypi reboot
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2017-06-15 a couple of fixes and start on 'continue in ethernet mode'
2017-06-15 deal with case where wifi is configured in client mode in wpa_supplicant but flag in setup db is not yet set
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2017-12-21 V2.8.4: correct USA voltage 120V
    [src.ino]
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2018-03-27 Avoid undefined return values in certain paths
    [rf.ino, temperature.ino]
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2018-05-29 Revert "Mount /var/lib/php/sessions as tempfs for Stretch php7"
    This reverts commit f658535d011311c69ba8a39c30738c275f8901a1.
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2018-08-23 add Stretch specific config files & modify WiFi AP to work on both Jessie & Stretch
    [config.txt]
2018-10-20 Correction to versions
    Commit https://github.com/openenergymonitor/emonpi/commit/ef63fd52edb5e96ba0189d938df953c583cd612d broke support for the current latest image "emonSD-26Oct17".
    See https://community.openenergymonitor.org/t/after-update-to-9-9-0-process-list-all-unavaiblable/8893/7?u=pb66
2018-10-30 LCD script improvments: error handling, AP mode display
    [emonPiLCD.py]
2018-11-19 Update service-runner-update.sh
    Line 138 is not outputting the new line for the \n because echo doesn't understand those.
    either change to printf, or to "echo -e" and remove the "\n"
2018-11-25 Add support for Dallas DS2438 temperature readings The DS2438 is commonly used in a lot of ibuttonlink.com sensors which are very popular https://www.ibuttonlink.com/collections/1-wire-temperature-se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
    These plug straight into the emonpi and are very useful.
    The DS2438 also has other capabilites for measuring DC Voltage and
    current which are not added in this commit. Maybe someday..
2018-11-27 Added configuration file for emonPiLCD.py Allows user to tweak config and choose other values for display for the power readings (for example, if an external power meter is being used)
    Fixed issue with backlight=0 , and default page is now the power
    readings. Useful if emonpi is in a dark cupboard (as they usually are)
    [emonPiLCD.cfg]
2018-11-27 Defaults set correctly for emonpi
    [emonPiLCD.cfg]
2018-11-27 Reduce Pi CPU usage by 30 - 40% ! The emonPiLCD.py script has been refactored to properly use the button Callback and only workout values for the LCD on a button press
    Previous there was a crazy while (true) loop which constantly battered
    the Pi and REDIS causing massive CPU usage.
    This should leave a lot more headroom for things like openhab and make
    the pi more responsive.
    The shutdown button has also been moved to a callback, avoiding the need
    to poll constantly. It activates on 'long press'
    [emonPiLCD.py]
2018-11-27 fix default ssh password
    [emonPiLCD.py]
2018-11-27 Fixed some bugs with update not working without button being pressed Refactored code to provide fucntion for lcdUpdate Removed unneeded dependencies and cleaned up unused vars Fixed error with long b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
    [emonPiLCD.cfg]
2018-11-28 Fix non-initialise variable error for GSM when eth but no wifi In other words, initialise redis eth,wlan and gsm variables in main()
    [emonPiLCD.py]
2018-12-04 Added Shutdown & Ssh menu to main push button Long hold turns off backlight
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2018-12-06 set default IP address LCD display
    [emonPiLCD.cfg]
2018-12-09 SSH toggling feature added. Will now detect if SSH enabled or not and offer to disable / enable accordingly on the push button
2018-12-10 change sshd to ssh
    [emonPiLCD.cfg]
2018-12-12 fix non-zero LCD timeout
    [emonPiLCD.py]
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2019-02-07 - update all emoncms modules that have .git folder in emoncms/Modules folder - print git tags - allow for emoncms installed in both /var/www/emoncms and /var/www/html/emoncms directories
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2019-04-28 Update EmonpiLCD
    Update emonpiLCD.config so that the default is that the screen sleeps.
    this is inline with EmonPis sold from the shop.
    [emonPiLCD.cfg]
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2019-09-26 - only upgrade settings.php if present - switch postprocess branch to stable
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2019-09-26 fix device module branch switch
2019-10-04 exit without failure state if emonbase
    [emonPiLCD.py]
2019-10-17 Fix dodgy merge commit 53a34285.
    [emonPiLCD.py]
2019-11-17 fix RFM init
    https://community.openenergymonitor.org/t/emonpi-firmware-build/12428/45
    [src.ino]
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2020-06-14 LCD refactor.
    - The logic to detect the address isn't suitable in an initialiser.
    Failure is messy. Move it up into main.
    - lcd_clear is used once but text is immediately displayed so it is
    pointless. Just remove it.
    [emonPiLCD.py]
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2020-06-14 Refactor lcddriver. Probe directly.
    We don't need the extra indirection of the LCD class in emonPiLCD, just
    move the useful functionality into lcddriver and use it directly.
    Just try to create the lcd object, it will throw an exception if it
    can't communicate with the LCD driver.
2020-06-14 Avoid subprocess to detect SD image version.
    [emonPiLCD.py]
2020-06-14 Generalise MQTT->redis->display logic.
    This allows using the modern MQTT topics, rather than the deprecated
    "packed" format. Add these to the config file too.
    [emonPiLCD.cfg]
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2022-01-31 lock updateLCD() process to avoid LCD corruption if interrupted
    [emonPiLCD.py]
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2023-04-04 fix version and native compile
    [emonPi_CM.ino]
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2023-06-27 Update readme.md
    Fix closing braket

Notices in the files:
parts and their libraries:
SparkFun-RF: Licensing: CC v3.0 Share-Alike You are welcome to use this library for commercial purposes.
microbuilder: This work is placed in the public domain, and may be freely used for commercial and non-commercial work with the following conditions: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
